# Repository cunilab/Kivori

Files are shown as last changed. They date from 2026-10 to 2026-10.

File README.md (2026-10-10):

# Kivori

Kivori is a desk buddy you control your computer with: the buddy is why you want one, the physical knob and button are why you keep using it, and the display shows important desktop and system state around the buddy.

> **Product thesis:** Control the desktop physically. Understand the desktop visually.

## Project status

**M0 — Working foundation.** Connection, protocol, deterministic rendering, Device Studio, the ESP32-C3/ST7789 runtime, the rotary volume loop and the mascot with its activity log are built. Remaining physical acceptance rows live in [`docs/validation.md`](docs/validation.md).

**M1 — Useful desk device.** Software complete on Windows and macOS, host-tested end to end. The push switch does Press (Play/Pause), Hold (mute) and Double press (next view); holding it ~10 s reboots the device with no app needed. The display has Buddy, Clock, Volume, Media and CPU/RAM views, and every action outcome is shown honestly as Confirmed, Started, Unverified or Failed. **Physical validation is outstanding:** the M0 rows and the Phase 4 rows in [`docs/validation.md`](docs/validation.md) need one human session.

**M2 and M2.5.** Three contextual buttons (Press and Hold each), the bindings config UI and foreground-app profiles are software complete and host-tested, awaiting hardware validation (Phase 5 and 6 rows).

**M3 — Paid beta.** Software complete: host takeovers, sleep and lock handling, firmware update and recovery, launch at login with a tray, the installer and an unsigned release pipeline ([`docs/release.md`](docs/release.md)), first-run onboarding, and per-unit provisioning ([`docs/provisioning.md`](docs/provisioning.md)).

Beta users start with the [user guide](docs/user-guide.md). Still open, and none of it is code: the hardware validation session (issue #38), signing the installer (needs certificates, #36), and the enclosure print (#33). See [`docs/roadmap.md`](docs/roadmap.md). Product behavior is defined in [`docs/product.md`](docs/product.md); durable technical choices are the ADRs in [`docs/architecture.md`](docs/architecture.md).

## Hardware

One ESP32-C3, one ST7789 240×240 panel, one HW-040 rotary encoder, three momentary push buttons. USB provides power, flashing, and the product data link — no external UART bridge.

### Pin map

| Signal | GPIO | Notes |
|---|---:|---|
| SPI SCK | 6 | SPI2, 20 MHz, Mode 3 |
| SPI MOSI | 7 | |
| Display D/C | 2 | strapping pin, driven after boot |
| Display RST | 3 | |
| Backlight | 8 | active-high; strapping pin, must be high at reset anyway |
| Encoder CLK (A) | 4 | |
| Encoder DT (B) | 5 | |
| Encoder SW | 10 | push switch: Press, Hold, ~10 s recovery reboot |
| Button left / middle / right | 0 / 1 / 20 | to GND, internal pull-up, no resistor; GPIO0/1 need a devkit without a 32 kHz crystal |
| USB D− / D+ | 18 / 19 | native USB Serial/JTAG, `0x303A:0x1001` |

Encoder COM to **GND**, VCC to **3V3**. **Not 5V — ESP32-C3 GPIOs are not 5 V tolerant.** Firmware enables internal pull-ups and reads all three encoder lines active-low, so it works whether or not your HW-040 board populates its own pull-ups.

### Two things worth knowing about these pins

**GPIO9 is deliberately avoided for the switch**, even though it is the BOOT button on most devkits. Holding GPIO9 low at reset enters the ROM download mode, and the encoder switch is Kivori's recovery control — a user power-cycling while holding it for recovery would land in the downloader instead of booting Kivori.

**The display pins are measured evidence; the encoder pins are not.** The display profile was physically verified on 2026-08-11 and is recorded in [`docs/validation.md`](docs/validation.md) (rows 1.9, 1.24, 1.25). The encoder pin map is a *specification* wired to on request, pending physical confirmation — row 3.15 of the same checklist. Do not treat the two as equally settled.

Both live in one place, [`firmware/esp32-c3/src/profile.rs`](firmware/esp32-c3/src/profile.rs), so a rewire is a single constant change.

## Getting started

### Prerequisites

- **Rust** stable (both workspaces pin it; the firmware workspace adds the `riscv32imc-unknown-none-elf` target automatically)
- **[Bun](https://bun.sh)** for the frontend
- **[just](https://github.com/casey/just)** as the command runner
- **[espflash](https://github.com/esp-rs/espflash)** only if you are flashing hardware — `cargo install espflash`
- **jq** for the dependency guard scripts
- A `WOKWI_CLI_TOKEN` only if you intend to run the Wokwi simulation gate

### Run the desktop app

```bash
bun install
just desktop                   # UI dev server + native app with the bundled firmware, one command
```

The native core owns the serial link; the webview receives only typed IPC commands. Device discovery is automatic — there is no COM-port picker by design.

### Flash the device

```bash
just fw-build                  # builds the product firmware (physical-st7789)
just fw-flash                  # flash + monitor over USB
```

Both recipes select the `physical-st7789` feature, which is what reaches the real display-and-input runtime. A plain `--features embedded` build compiles, but falls through to a bare fallback with no display and no input — useful to know if you invoke cargo directly.

### Verify without hardware

Most of the system is provable on a host machine:

```bash
just test                      # host workspace + frontend
just fw-test                   # firmware core against host-sim adapters
just golden                    # deterministic rendering, frame-hash goldens
just sim-test                  # Wokwi scenarios (needs a token)
```

Host-sim, Wokwi simulation, and physical hardware are **separate classes of evidence** in this project, and simulation never gets promoted to physical proof. Hardware results are recorded in [`docs/validation.md`](docs/validation.md).

## Documentation

One file per topic:

| File | What it answers |
|---|---|
| [`docs/product.md`](docs/product.md) | What Kivori must do: scope, behavior rules, numbered invariants, acceptance gates |
| [`docs/architecture.md`](docs/architecture.md) | How it works: components, wire protocol, IPC, rendering, rotary loop, decisions, principles |
| [`docs/roadmap.md`](docs/roadmap.md) | What gets built next, milestone by milestone (M0 to paid beta to v1) |
| [`docs/validation.md`](docs/validation.md) | The hardware checklist and how to run a validation session |
| [`docs/release.md`](docs/release.md) | How to cut a Windows or macOS release, and the unsigned-installer limits |
| [`docs/provisioning.md`](docs/provisioning.md) | Flashing and checking each new unit (`just provision`) |
| [`docs/user-guide.md`](docs/user-guide.md) | Short guide for a beta customer: install, setup, controls, recovery |
| [`docs/bom.md`](docs/bom.md) | Draft bill of materials (prices still to fill in) |

Wokwi simulation setup lives in [`sim/wokwi/README.md`](sim/wokwi/README.md). If the docs disagree,
`product.md` wins on behavior and the code wins on facts. Older plans, specs and research are in Git
history.

## Repository layout

```text
Kivori/
├── docs/        product, architecture, roadmap, validation, release, provisioning, user guide, BOM
├── apps/        Tauri desktop app (native core + Device Studio webview)
├── crates/      shared no_std crates: model, protocol, renderer, assets, framebuffer
├── firmware/    ESP32-C3 firmware
├── hardware/    3D-printable enclosure and printed prototype PCB (FreeCAD, parametric)
├── sim/         Wokwi simulation
├── tests/       golden frames and cross-crate tests
└── tools/       asset compiler and generators
```

## Common commands

The repository uses [`just`](https://github.com/casey/just) as a convenience command runner.

```bash
just dev               # Vite dev server for the Device Studio UI
just lint              # Rust + TypeScript formatting/lint/type checks
just test              # host workspace + frontend tests
just build             # host workspace + frontend build
just fw-check          # shared no_std crates compiled for RISC-V (isolation proof)
just fw-test           # firmware core against host-sim adapters
just fw-build          # build the product ESP32-C3 firmware (physical-st7789)
just fw-flash          # flash + monitor the product firmware over USB
just sim-test          # Wokwi integration scenarios (needs WOKWI_CLI_TOKEN)
just desktop           # UI dev server + native app with the bundled firmware
just provision         # flash and check one new unit (docs/provisioning.md)
just bundle-windows    # build the unsigned Windows installer (docs/release.md)
just bundle-macos      # build the macOS .app/.dmg (docs/release.md)
just golden            # deterministic rendering golden-frame tests
just check-boundaries  # shared-crate dependency firewall
just assets            # recompile the canonical asset blob
```

Three guard scripts run in CI and are worth running locally before pushing — they fail for reasons ordinary tests do not catch:

```bash
bash scripts/check-release-surface.sh   # dev-only surfaces absent from production builds
bash scripts/check-crate-boundaries.sh  # no std/OS deps in the shared no_std crates
bash scripts/check-offline-deps.sh      # no first-party crate pulls a network client
```

`check-release-surface.sh` compiles the shared crates for the device target on purpose, including a positive control that proves the absence checks are not vacuous. It is the one gate most likely to catch a change that every test suite still passes.

See [`docs/validation.md`](docs/validation.md) and [`sim/wokwi/README.md`](sim/wokwi/README.md) for hardware and simulator setup.

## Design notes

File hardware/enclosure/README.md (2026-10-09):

# Kivori enclosure (prototype v3, "big keycap")

A 110 × 70 mm wedge case (30 mm thick at the far edge, 18 mm at the near edge, so the face tilts
about 10° towards you). It follows the blueprints in [`docs/assets/`](../../docs/assets/) and is
10 mm wider than drawn: at 100 mm, the Ø48 knob overlaps the left button.

The look is a big keycap, matching the keycap mascot on screen:

- **Shell:** the walls lean in 6° towards the face, and a 45° bevel frames it. The sides are
  clean: no latch windows or screws.
- **Visor:** a black panel, 1 mm proud of the face, carries the display window and the three
  button openings. Its edge follows the knob at an even gap.
- **Knob:** sits inside a thin groove ring. Fine ribs round the edge for grip, and a line marker
  on top.
- **Plinth:** dark and set back under the shell, so the light shell seems to float above the desk.
  The underside carries the wordmark, the RST/BOOT labels and recesses for rubber feet.
- **Colours:** light matte shell; black visor, knob and plinth; accent-colour caps.

Inside is a **printed PCB** (`Carrier`): a plate with the outline, mounting holes and part positions
a real PCB would have. Components sit on it and are hand-wired along engraved grooves on the
back. Once the prototype works, `export/pcb-outline.dxf` becomes the Edge.Cuts layer in KiCad.

No screws. Four hooks on the back plate catch ribs inside the walls. Each hook has 45° ramps
both ways, so the plate clicks in and pulls back out. The printed PCB is clamped between posts on
the faceplate and columns on the back plate.

How each part is held on the printed PCB, even with the case open:

| Part | Held by |
|---|---|
| HW-040 | A pocket stops it sliding. Two pegs go through its two M3 holes along the long edge. The pocket floor is open under the encoder legs and the three pull-up resistors. |
| Display | Four standoffs whose pegs go through its four corner holes. |
| SuperMini | A 1 mm recess in the back whose end wall takes the USB plug-in force. When closed, a pad on the back plate presses up under the USB connector. |
| 12×12 switches | Legs through the plate, bent over on the back before soldering. |

The pegs are 0.2 mm smaller than the holes (press fit) and stick out 1 mm past the module board.
To lock a part for good, touch each peg tip with the soldering iron so it melts into a small head
(heat-staking). To remove the part later, cut the head off. The faceplate has relief pockets over
the display pegs, so a staked head still fits.

## Files

| File | What |
|---|---|
| `build_case.py` | The whole model. Every dimension is a parameter at the top. |
| `kivori-case.FCStd` | Generated FreeCAD document (printed parts plus blue stand-ins for the bought parts). |
| `export/*.stl` | Printed parts, already in print orientation (binary STL). |
| `export/pcb-outline.dxf` | Printed PCB outline, mounting holes and pin holes, in mm. |

To rebuild after changing a parameter, run it headless from the repo root:

```bash
/Applications/FreeCAD.app/Contents/Resources/bin/freecadcmd hardware/enclosure/build_case.py
```

or in FreeCAD's Python console (or through the FreeCAD MCP):

```python
p = "<repo>/hardware/enclosure/build_case.py"
exec(open(p).read(), {"__file__": p, "__name__": "__main__"})
```

It prints an interference report (`interference: none` is the goal), regenerates the document
and rewrites `export/`.

## Parts to print

FDM, 0.4 mm nozzle, 0.2 mm layers, 3 walls, 20 % infill. None of the parts needs supports.

| Part | Material | Orientation (already applied in the STL) |
|---|---|---|
| `Shell` | matte light PLA (white or warm grey) | face down |
| `Visor` | black PLA; a smooth PEI sheet gives it a glossy face | top down |
| `BackPlate` (with the plinth) | black **PETG** (the hooks crack in PLA) | desk side down |
| `Carrier` (printed PCB) | any PLA (hidden) | back down, pegs and standoffs up |
| `Knob` | black PLA | top down |
| `CapLeft` / `CapMiddle` / `CapRight` | accent-colour PLA | flange down |

Every part is printed in a single colour; the two-tone look comes from printing the parts in
different filaments, so no filament change mid-print is needed.

## Bought parts

| Part | Notes |
|---|---|
| ESP32-C3 SuperMini | Flush in a recess in the back of the printed PCB, components facing the back plate. No header pins: solder wires to the pads. |
| ST7789 1.3" 240×240, 7-pin | On four standoffs with pegs, glass in a 0.6 mm pocket behind the window, header pins through the slot. |
| HW-040 rotary encoder | In a pocket on the front of the printed PCB, on two pegs. Its right-angle header points towards the middle of the case; wires drop to the back through the slot past the pin tips. The nut is optional. |
| 3 × 12×12 mm push switch, 10 mm tall | Legs go through the printed PCB. |
| Thin wire (26–30 AWG) | Laid in the grooves on the back. |
| 4 × 10 mm stick-on rubber feet | In the recesses under the plinth. |

## Assembly

1. Press the HW-040 onto its two pegs in the pocket on the front of the printed PCB. Press the
   display onto its four pegs, header through the slot. Optionally heat-stake the six peg tips.
2. Put the three switches through their holes and bend the legs over on the back.
3. Press the SuperMini into the recess on the back, components facing out and USB-C towards the
   open end.
4. Wire along the grooves (table below) and solder each wire to the pin where its groove ends.
5. Drop the three caps into the face openings from inside the shell, flange first.
6. Lower the printed PCB onto the four posts, encoder shaft through the face hole.
7. Press the back plate straight in until all four hooks click, then stick the feet on.
8. Press the visor's three pegs into the face. A drop of CA glue or thin double-sided tape keeps
   it there.
9. Push the knob onto the D-shaft.

To open: grip the plinth in the shadow gap and pull. The hooks release without tools. RST and
BOOT are pinholes in the plinth, labelled; a paperclip reaches the SuperMini's buttons.

## Wiring

These are the pins from [`profile.rs`](../../firmware/esp32-c3/src/profile.rs) and the README.

| SuperMini | Net | Goes to |
|---|---|---|
| IO6 | SCL | display SCL |
| IO7 | SDA | display SDA |
| IO2 | DC | display DC |
| IO3 | RES | display RES |
| IO8 | BLK | display BLK (backlight) |
| 3V3 | 3V3 | display VCC, encoder + (**never 5 V**) |
| GND | GND | display GND, encoder GND, one leg of each switch |
| IO4 | CLK | encoder CLK |
| IO5 | DT | encoder DT |
| IO10 | SW | encoder SW |
| IO0 / IO1 / IO20 | B1 / B2 / B3 | left / middle / right switch, other leg |

Validation row 5.1 still applies: check that the SuperMini has no 32.768 kHz crystal on
GPIO0/GPIO1.

## Dimensions to verify (NOMINAL in `build_case.py`)

Nothing here was measured on the real parts. The HW-040 and display layouts are scaled from a
dimensioned drawing and product photos (about ±0.5 mm). The rest comes from KiCad footprints and
seller listings. Ranked by risk:

1. **Display module** (`DISP_*`):
   - 4 corner holes, Ø2, centres 2 mm in from both edges.
   - Board 39.22 × 27.78 mm, 3.0 mm thick with the glass.
   - Glass 27.6 mm long including the FPC ledge, centre 1.6 mm from the board centre towards the
     end away from the header. Active area centre 0.5 mm the same way.
   - Header row 2.2 mm in from its end, header on the right as mounted (`DISP_HEADER_SIDE`).
2. **HW-040** (`HW040_*`, in the module's own frame, origin at the board centre):
   - Board 26 × 18.5 × 1.3 mm.
   - Shaft at (−3.7, +1.25).
   - M3 holes at (−8.4, −7.45) and (+5.8, −7.45).
   - Header row at x = +10.35.
   - Shaft top 21 mm above the board underside. EC11 body 6.5 mm and bushing 7 mm are NOMINAL.
3. **SuperMini**: BOOT/RST positions (`SM_BTN_*`), header pin order (`SM_COL_A/B`), USB-C size.
4. **12 mm switch**: projected-plunger type, seller drawing TS-G005, 10 mm tall version.
   - Housing 12 × 12 × 3.5 mm with a round Ø7 platform up to 4.3 mm.
   - Stem: a 3 mm square neck, then a wider 4 × 4 mm head about 1.8 mm tall, top at 10 mm.
   - The cap socket is 4.3 mm square. It slips over the head and stops the cap turning; the
     flange behind the faceplate is what holds the cap in.
   - Pins on a 12.5 × 5 mm grid (land pattern Ø1.5). Two extra Ø2 holes, 9 mm apart, clear the
     locating bosses some 12 × 12 switches have (Omron B3F); TS-G005 shows none.

A cheap check before the full print: print only the `Carrier` first (about 1 h), then press the
parts on. If a peg misses its hole, measure the hole position, change the parameter and rebuild.

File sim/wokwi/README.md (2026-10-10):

# Wokwi pre-hardware simulation gate

Runs the **real** Kivori ESP32-C3 firmware in the [Wokwi](https://wokwi.com) simulator so the embedded
runtime, protocol loop, lifecycle state machine, and renderer integration can be exercised **before**
anyone flashes a board.

> **Simulation does not replace physical validation.** A green Wokwi run says the firmware's logic
> executes correctly on a simulated RISC-V core. It says nothing about whether the product works on real
> hardware. The physical checks in [`docs/validation.md`](../../docs/validation.md)
> remain mandatory and unchecked until someone runs them on a device.

## Four modes, four artifacts

| Mode | Feature | Artifact | Diagram | What drives the device |
|---|---|---|---|---|
| **Internal on-target self-test** | `wokwi` | `target/wokwi/kivori-selftest.elf` | `diagram.json` (UART0 monitor) | an in-firmware harness — this is an *integration self-test*, **not** an external serial-transport test |
| **External serial test** | `wokwi-serial` | `target/wokwi/kivori-serial.elf` | `diagram-usb-serial.json` (`serialInterface: USB_SERIAL_JTAG`) | Wokwi `write-serial` injects **real wire frames** from outside; the firmware's real USB Serial/JTAG rx/tx loop, decoder, sequence policy, and `Dispatcher` handle them |
| **Production runtime** | `wokwi-runtime` | `target/wokwi/kivori-runtime.elf` | `diagram-runtime.json` (USB Serial/JTAG + generic display + logic analyser) | **the real `runtime::run` loop** — the same function the physical firmware calls, with a simulation-only board profile. The strongest evidence in the gate: it is the shipping loop, not a harness |
| **Generic SPI display probe** | `wokwi-spi` | `target/wokwi/kivori-spi.elf` | `diagram-spi.json` (`wokwi-ili9341` as a *generic* SPI sink) | the real T072 `mipidsi` `DisplaySink` over the real esp-hal SPI peripheral; counted at the `embedded-hal` boundary and captured as a VCD |

The external mode is the stronger evidence: bytes genuinely enter the device from outside. Injected bytes
are generated by [`tools/wokwi-vectors`](../../tools/wokwi-vectors) from the real `kivori-protocol` codec,
so no wire-format constant is duplicated for tests. Regenerate with:

```bash
cargo run -p kivori-wokwi-vectors     # writes sim/wokwi/generated/ (CI fails on a stale diff)
```

Neither mode creates an operating-system serial port: **the Tauri desktop cannot open a Wokwi device.**

## How it works

Wokwi automation supports both directions: `wait-serial` asserts on serial **output**, and `write-serial`
accepts a **byte array**, so real binary frames can be injected as serial **input**. The supported step
vocabulary was verified against the CLI's own validator (v0.26.1): `wait-serial`, `write-serial`, `delay`,
`set-control`, `expect-pin` are accepted; `wait-pin`, `screenshot`, `wait-text` are not.

* The **internal** self-test ([`selftest.rs`](../../firmware/esp32-c3/src/selftest.rs)) drives the core
  from inside via [`LoopbackTransport`](../../firmware/esp32-c3/src/sim_probe.rs), printing one
  `KIVORI-SIM …` line per check. Useful, but it is an on-target *integration* self-test — it does not
  exercise the serial peripheral.
* The **external** mode ([`external.rs`](../../firmware/esp32-c3/src/external.rs)) is the real thing:
  injected bytes arrive through the USB Serial/JTAG peripheral via
  [`transport.rs`](../../firmware/esp32-c3/src/transport.rs) (the same adapter the hardware run loop will
  use), pass through the real decoder + sequence policy + `Dispatcher`, and the device's real response
  frames go back out over the same peripheral. Redacted `KIVORI-EXT …` markers report the semantics.

Nothing under test is simulation-specific:

| Layer | In simulation | On hardware |
|---|---|---|
| Protocol codec, dispatcher, lifecycle FSM | identical (`kivori-protocol`, `proto.rs`, `state.rs`) | identical |
| Renderer, scene model, compiled asset bundle, RGB565 tiles | identical (`kivori-renderer`, same blob bytes) | identical |
| Clock | `EspClock` (esp-hal system timer) | same `EspClock` |
| Transport | **real `UsbJtagTransport`** (external mode); `LoopbackTransport` probe (internal mode) | same `UsbJtagTransport` |
| Display | `TileProbe` (internal mode); **real `MipidsiSink`** over real SPI (`wokwi-spi` mode) against a *generic* display part | same `MipidsiSink`, with the **confirmed** panel model and its real offsets |

There is **no separate simulation renderer** — that would violate Constitution II.

## Usage

```bash
bash scripts/build-wokwi-firmware.sh              # builds all FOUR ELFs into target/wokwi/
export WOKWI_CLI_TOKEN=...                        # CI token; never committed, never in argv
bash scripts/test-wokwi.sh                        # runs all eight scenarios
bash scripts/test-wokwi.sh boot spi-display-probe  # or a subset, matched by name
```

`wokwi-cli` must be installed (`curl -L https://wokwi.com/ci/install.sh | sh`, then
`export PATH="$HOME/.wokwi/bin:$PATH"`). Both the CLI and the token are required; the script exits with
status 2 and an explanation rather than reporting a false pass.

### The token must be a CI token

`WOKWI_CLI_TOKEN` must be a **CI token** from <https://wokwi.com/dashboard/ci> (short, `wok_…` shaped).
An interactive user/session credential — for example the long JWT that `wokwi-cli` writes to
`~/.wokwi/user.tok` after a browser login — is **not** a CI token: the CLI connects to the Simulation API
and the API answers `Unauthorized`. If you see:

```
Connected to Wokwi Simulation API 1.0.0-…
API Error: Unauthorized
```

the transport and the project are fine; the credential is the wrong type, revoked, expired, or from a
different account. Mint a CI token and re-export it. Never commit a token; never put it in workflow YAML
(CI reads `secrets.WOKWI_CLI_TOKEN`).

## Scenarios

Internal self-test (hand-written, no injection):

| Scenario | Asserts |
|---|---|
| [`boot.yaml`](scenarios/boot.yaml) | firmware boot, monotonic/advancing clock, `booting` → `offline` |
| [`protocol.yaml`](scenarios/protocol.yaml) | dispatch loop, `Hello`/`HelloAck` + nonce, identity, capability advertisement, major-version rejection, `Ping`/`Pong`, malformed-frame recovery |
| [`state-cycle.yaml`](scenarios/state-cycle.yaml) | `SetState`/`StateReport`, `booting`/`offline` never sendable, compiled-asset parse, 6×240×40 RGB565 tiles, change-driven refresh, safe diagnostics |

External serial injection (generated — contain real wire bytes):

| Scenario | Asserts |
|---|---|
| [`generated/serial-smoke.yaml`](generated/serial-smoke.yaml) | readiness marker, one real `Ping` frame received over USB Serial/JTAG, `Pong` response path |
| [`generated/protocol-serial.yaml`](generated/protocol-serial.yaml) | handshake, compatible-minor accept, unsupported-capability intersection, unsupported-major drop, CRC-invalid drop, malformed-COBS drop, truncated-frame drop, recovery with the next valid frame, sequence duplicate/gap/wraparound classes |
| [`generated/state-cycle-serial.yaml`](generated/state-cycle-serial.yaml) | `SetState(idle)` → `StateReport(idle)`, `SetState(happy)` → `StateReport(happy)`, structural sendable guard |

Generic SPI display probe (hand-written; real SPI traffic):

| Scenario | Asserts |
|---|---|
| [`generated/production-runtime.yaml`](generated/production-runtime.yaml) | the **production** loop: device-owned `booting` → `offline`, the first full frame, change-driven refresh, health cadence, `Hello`→`HelloAck`, `SetState`→`StateReport` for idle and happy, a malformed frame dropped and reported as a SAFE `Diagnostic` (category+code only), recovery on the next valid frame, and `ALL PASS production-runtime` only once all ten hold |
| [`spi-display-probe.yaml`](scenarios/spi-display-probe.yaml) | SPI peripheral + GPIO bring-up, panel reset sequenced, command/data phases distinguishable (D/C), CS-framed transactions, solid red/green/blue and checkerboard RGB565 frames, six 240×40 tiles of 9,600 pixels in top-to-bottom order, an **exact** per-frame byte volume (115,248 data + 18 command bytes), no retransmission for an unchanged frame, retransmission on a state change |

### VCD capture requires a logic analyzer part

`--vcd-file` alone produces **nothing**. Verified from an actual run: the CLI reported
`Error exporting VCD: Error 6: No logic analyzer in diagram` and wrote no file. `diagram-spi.json`
therefore includes a `wokwi-logic-analyzer` with `channelNames: "SCK,MOSI,CS,DC,RST"` on `D0`–`D4` plus
`GND`; `triggerMode` defaults to `off`, which records from the start, so no trigger wiring is needed.

Two things a real capture taught us, both now encoded in the checker and its tests:

* **Every line reads `1` at time 0.** The pins float high until the firmware configures them ~164 ms into
  boot, so the first sample is not bus activity. Measuring from time 0 made "data follows command" fail on
  a perfectly good bus. Every activity measurement is now taken **after the panel reset is released**.
* **The capture is a truncated window.** `bufferSize` is 500,000 samples (≈6.7 MB), while a full run clocks
  ~691 KB of pixel data. The checker's thresholds are deliberately below a full frame's worth for that
  reason — the VCD proves the bus behaves, and the firmware's own counters prove the exact volume.

`wokwi-cli lint` warns `Unknown attribute "channelNames"`; its attribute list is stale, and the simulator
honours it — the produced VCD declares `SCK`/`MOSI`/`CS`/`DC`/`RST`, not `D0`–`D4`.

That scenario also writes `target/wokwi-vcd/spi-display-probe.vcd`, which
[`tools/wokwi-vcd`](../../tools/wokwi-vcd) then parses: clock activity, CS/D/C transitions, a reset pulse,
data following a command phase, a minimum clocked-bit volume, and monotonic stage ordering. A capture that
cannot be parsed — or whose signals cannot be identified — **fails**; it is never accepted for existing.
Run `cargo run -p kivori-wokwi-vcd -- --list-signals <file.vcd>` to see the real signal names and adapt
`Role::candidates` from evidence.

### Marker order is part of the contract

`wait-serial` scans **forward only**, so a scenario must await markers in the order the firmware genuinely
emits them. The production-runtime scenario's first draft awaited `health-report` after
`unchanged-frame-no-reflush`; the runtime emits health on tick 1 and the first quiet frame on tick 2, so the
run hung to timeout — the same defect that once broke `state-cycle-serial`. The order now matches real
behaviour and is pinned by a host test (`emission_order_is_stable`), plus marker/firmware coupling tests in
`tools/wokwi-vectors/tests/scenario_files.rs`.

Timeouts are per-scenario wall-clock budgets, because Wokwi runs slower than real time and the production
runtime re-hashes six tiles every simulated 33 ms. Budgets never change what a scenario asserts.

A scenario fails when a `wait-serial` line never arrives (panic, hang, decode failure, missing handshake
reply, missing `Pong`, render-loop stall) or when `--fail-text` matches `KIVORI-SIM FAIL` / `panicked`.

## What this gate does **not** prove

Simulation is **not** evidence for any of the following. Each remains a physical-hardware task:

- real USB VID/PID enumeration (`0x303A:0x1001`) — T115
- Tauri opening a real serial device / desktop↔device end-to-end — T115, T117
- electrical correctness, signal integrity, pull-ups, level shifting
- **the identity of the physical panel controller** (measured on the real board as an ST7789, validation rows 1.9, 1.24, 1.25; simulation says nothing about it) — T118
- real display offsets, colour order, orientation, or any panel init sequence — T118
- the Kivori board's real SPI/CS/D/C/RST pin map — the `wokwi-spi` pins are a *simulation-only* profile
- anything analog: a VCD is a digital event list, so no signal integrity, timing margin, or level checks
- physical SPI integrity and timing — T119
- sustainable physical frame rate over SPI — T119
- physical unplug/reconnect reliability — T116, T117
- power consumption or thermal behaviour
- esp-hal `unstable` API behaviour on real silicon — T122

## Display strategy (staged)

**Stage 1 (implemented).** No display part in [`diagram.json`](diagram.json). `TileProbe` proves the
canonical renderer produces the right RGB565 tile geometry and that unchanged frames flush nothing —
without asserting anything about a controller.

**Stage 2 (implemented — T131).** [`diagram-spi.json`](diagram-spi.json) adds Wokwi's built-in
`wokwi-ili9341` and the `wokwi-spi` firmware drives it through the real T072 adapter
([`display.rs`](../../firmware/esp32-c3/src/display.rs)), so genuine SPI traffic exists to observe. Three
scopes, and only the first two are claimed:

| Scope | Claimed? | Content |
|---|---|---|
| **A — generic SPI transactions** | ✅ | peripheral init, reset sequencing, command/data phases, CS framing, transfer boundaries |
| **B — generic RGB565 tile stream** | ✅ | six 240×40 tiles, 9,600 pixels each, deterministic byte volume and order, tile Y offsets, change-driven refresh |
| **C — controller-specific behaviour** | ❌ **not claimed** | any ST7789/GC9A01/ILI9341 init sequence, panel offsets, orientation, colour order, backlight |

`wokwi-ili9341` is used **only** as a generic SPI/RGB565 sink. It does **not** validate an ST7789 (or
GC9A01) initialisation sequence — the controllers differ in init, offsets, and colour order — and a green
probe run is therefore not evidence that any real panel will light up. The adapter itself is generic over
`mipidsi`'s `Model`, so no controller is hard-coded anywhere in the firmware.

The pin numbers in `diagram-spi.json` (`SCK=4, MOSI=5, CS=6, D/C=7, RST=10`) are a **simulation-only**
profile (`WokwiSpiPins`). They were chosen from the board part's valid pins as reported by
`wokwi-cli lint` — `0–10, 18, 19, RST, RX, TX` — excluding `18`/`19` (USB Serial/JTAG on this SoC) and
`2`/`8`/`9` (ESP32-C3 strapping pins). They are **not** the Kivori hardware pin map (SCK 6, MOSI 7, D/C 2, RST 3, backlight 8, see
[`profile.rs`](../../firmware/esp32-c3/src/profile.rs)).

**Custom ST7789 chip: deliberately not created.** The physical controller is confirmed as an ST7789
(validation rows 1.9, 1.24, 1.25), but no chip model is needed yet. If one is, implement only the command subset Kivori uses — `SWRESET`, `SLPOUT`, `COLMOD`, `MADCTL`, `CASET`,
`RASET`, `RAMWR`, `DISPON` — with the Wokwi Custom Chips SPI/framebuffer APIs, and treat that chip as a
development tool, never a production dependency.

## Relationship to the other gates

```
host tests (primary)        cargo test --workspace, firmware --features host-sim, golden frames
        │
        ▼
Wokwi simulation (this)     embedded runtime + protocol/lifecycle/render on a simulated C3
        │
        ▼
physical hardware (final)   docs/validation.md — still required, still unchecked
```

Simulation may fail a change that host tests pass (e.g. a real linker/runtime problem), which is exactly
its value. It may also pass a change that a real board rejects — which is why it is never the last gate.

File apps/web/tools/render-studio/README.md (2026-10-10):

# Studio renders (dev only)

Renders the product pictures in `apps/web/public/media/renders/`. The WebP/PNG results are committed; this
tool is not part of the web build and CI never runs it.

```bash
bun apps/web/tools/render-studio/render.mjs            # all shots
bun apps/web/tools/render-studio/render.mjs hero-34    # selected shots by name
```

Needs the installed Google Chrome (`/Applications/Google Chrome.app`, or set `CHROME_PATH`). No browser is
downloaded. `three` and `puppeteer-core` are pinned devDependencies of `apps/web`.

How it works:

- `render.mjs` serves `scene.html` on 127.0.0.1 while it runs and drives Chrome with `puppeteer-core`.
- The enclosure STLs are read from `hardware/enclosure/export/` at render time only (Carrier is left out). They
  are never copied into `public/` or served by the site.
- `scene.js` puts every part back in its assembled place. The STLs are in print orientation, so each part gets
  the inverse of `print_pose` in `hardware/enclosure/build_case.py` plus its original bounding-box minimum
  (taken from the build script). If the enclosure model changes, re-derive those offsets (the numbers in
  `PARTS`), then re-render.
- The screen texture comes from `public/media/screens/` (see `../export-screens.mjs`).
- Output: 2400 px wide WebP (quality 90) and a `-1200` variant, plus a transparent `hero-34-transparent` PNG/WebP.

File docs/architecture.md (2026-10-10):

# Kivori architecture

How Kivori is built today. Product goals are in [product.md](./product.md), open work in [roadmap.md](./roadmap.md), test and hardware evidence in [validation.md](./validation.md).

## 1. Overview

Kivori is a small desk companion. A keycap-shaped mascot lives on a 240x240 screen, reacts to what the desktop tells it, a rotary knob turns volume (or per-profile shortcuts), its push switch runs actions (Press, Hold, Double press) and the out-of-band recovery hold, and three contextual buttons run per-profile actions. The display can also show a clock, volume, media and CPU/RAM view.

| Component | What it is |
|---|---|
| Firmware | ESP32-C3, ST7789 240x240 panel, HW-040 rotary encoder, three buttons. Version 1.3.0, protocol 1.5. `no_std`, no heap, `riscv32imc`. |
| Desktop native core | Tauri 2.12 Rust process. Owns the serial port, the connection, OS integration, preview rendering, flashing. |
| Desktop webview | React UI. Only calls a fixed set of typed commands. No serial, filesystem or shell access. |
| Shared crates | One copy of the model, protocol, renderer and asset reader, used by both firmware and desktop. |

```text
                  USB Serial/JTAG (COBS + CRC-32 + postcard frames)
  +--------------------+  <------------------------------------>  +---------------------+
  | Desktop native core|                                           | Firmware (ESP32-C3) |
  |  device thread     |   Hello/HelloAck/Ready, SetState,         |  ports: Clock,      |
  |  orchestrator      |   InputEvent, Presentation, ...           |  Transport, Display,|
  |  platform backends |                                           |  Input              |
  +---------+----------+                                           |  renderer -> ST7789 |
            | typed Tauri IPC (commands, events, binary channel)   +----------+----------+
  +---------+----------+                                                      |
  | React webview      |                                        HW-040 A/B/SW + panel
  +--------------------+
```

The wire carries meaning (state, input, presentation), never pixels. Both sides render with the same crates, so the Device Studio preview matches the panel.

### Repo layout

Two Cargo workspaces. Shared crates are `no_std`, no-alloc, and the single source of truth.

| Path | Purpose |
|---|---|
| `crates/kivori-model` | State enums, device profile, timeline, version and capabilities, mascot animator, input and presentation types. |
| `crates/kivori-protocol` | Wire codec: COBS, header, CRC-32, postcard `Message`, handshake and negotiation, sequence policy. |
| `crates/kivori-framebuffer` | RGB565 tile bands and content hashing (change detection). |
| `crates/kivori-renderer` | Deterministic scene compositor and volume overlay (`embedded-graphics` `DrawTarget`). |
| `crates/kivori-assets` | Zero-copy reader for the compiled asset blob. |
| `apps/desktop/src-tauri` | `kivori-desktop`: `device/` (discovery, session, reconnect, heartbeat, nonce), `runtime/` (device task), `orchestrator/`, `input/`, `action/`, `platform/`, `presentation/`, `desk/` (profiles, bindings, catalog, actions), `config/` (store, schema, resolve, migrate), `companion.rs`, `activity/`, `firmware.rs`, `firmware_marker.rs`, `window_lifecycle.rs`, `provision.rs` (dev-only `just provision`), `ipc/`, `render/`. |
| `apps/desktop/src` | React frontend and typed IPC wrappers. |
| `firmware/esp32-c3` | Separate workspace: `ports.rs`, `input/` (quadrature, gesture), `physical_st7789.rs`, `physical_rotary.rs`, `runtime.rs`, `proto.rs`, plus host simulation adapters in `sim/`. |
| `tools/asset-compiler` | SVG to deterministic RGB565 blob (host build tool). |
| `tools/wokwi-*`, `tests/e2e-host-sim`, `tests/golden-frames` | Simulation vectors, host-sim end-to-end tests, cross-OS frame-hash harness. |
| `.github/workflows/` | CI, see below. |
| `scripts/` | Boundary guards (`check-crate-boundaries.sh`, `check-offline-deps.sh`, `check-frontend-offline.mjs`) and firmware/desktop build scripts. |

CI workflows (`.github/workflows/`):

| Workflow | What it runs |
|---|---|
| `host` | Rust on Ubuntu and Windows, the frontend, and the Windows Device Studio startup smoke test: format, clippy, tests, the boundary, offline and release-surface guards. |
| `firmware` | no_std isolation proof, firmware host-sim tests and RISC-V builds and clippy per feature set. |
| `determinism` | Golden-frame hashes across operating systems and the byte-reproducible asset blob. |
| `wokwi` | The Wokwi simulation gate. Path-filtered (`firmware/**`, `crates/**`, `sim/**`, Wokwi tools and scripts) because its minutes are metered. |
| `release` | The unsigned Windows installer and draft release on a `v*` tag, manually with an optional macOS build; also on pull requests that touch packaging files ([release.md](./release.md)). |

`scripts/check-crate-boundaries.sh` fails CI if a shared crate gains a std, host or OS dependency. Compiling the shared crates for RISC-V is the hard backstop.

### State axes

Three separate axes. Never merge them into one enum.

- Companion (6): `booting, idle, happy, busy, sleeping, offline`. What the device shows.
- Sendable (4): `idle, happy, busy, sleeping`. The subset the desktop may command. `booting` and `offline` come from the device.
- Connection (5): `disconnected, connecting, connected, incompatible, error`. The link lifecycle.

Desktop state is in memory only. `desired` defaults to `idle` and is re-sent after a reconnect. `reported` is what the device says and never overwrites `desired`.

### Chosen platform APIs

- Transport: ESP32-C3 native USB Serial/JTAG (VID:PID `0x303A:0x1001`). It has a 64-byte FIFO and TX can stall if the host does not drain, so frames are small and writes are bounded.
- Firmware HAL: `esp-hal`, bare metal. Display: `mipidsi` with windowed writes.
- Desktop serial: blocking `serialport` on a dedicated device thread.
- Windows volume and mute: Core Audio `IAudioEndpointVolume` with callbacks, on its own COM thread.
- macOS volume and mute: CoreAudio `kAudioHardwareServiceDeviceProperty_VirtualMainVolume` and `kAudioDevicePropertyMute` on the default output device, with HAL property listeners, on its own `kivori-audio` thread (FFI declared by hand in `platform/macos/audio.rs`).
- Media keys and shortcuts: `enigo` (Windows `SendInput`, macOS Quartz events; macOS needs Accessibility permission). On macOS every synthesized input runs on the app's main thread via Tauri's `run_on_main_thread`: since macOS 15 the HIToolbox layout lookups it uses assert the main queue and kill the process otherwise.
- Media playback observation (state, title, artist): Windows Global System Media Transport Controls, polled on a `kivori-media` thread. macOS has no public API, so it is layered (ADR-0009): the vendored MediaRemote adapter, then AppleScript for Spotify and Music, then unknown.
- CPU/RAM: Windows `GetSystemTimes` / `GlobalMemoryStatusEx`; macOS per-CPU `host_processor_info` (`host_statistics` is rate-limited for third-party apps) and Activity Monitor's "Memory Used". Local time: `GetLocalTime` / `localtime_r`.
- Sleep, wake, lock and console changes: Windows `PowerRegisterSuspendResumeNotification` (callback) plus `WTSRegisterSessionNotification` on a message-only window thread; macOS IOKit `IORegisterForSystemPower` on a CFRunLoop thread (hand-declared FFI) plus a 4 Hz poll of the session lock flag. See Host presence.
- Flashing: a pinned `espflash` sidecar, driven by the native core (see Firmware update and recovery).
- Not built yet: a Linux backend, desktop self-update, a factory-provisioned device id.
- Device id (#24): the firmware derives its 16-byte `device_id` from the chip's factory eFuse unique ID, falling back to the base MAC, through a domain-separated SHA-256 (`kivori-device-id-v1`); raw eFuse bytes never go on the wire. The raw id stays in the transport layer; UI and logs only show the short hash (ADR-0005). Simulator and Wokwi images keep fixed ids.

## 2. Wire protocol

Contract crate: `kivori-protocol`. Both peers compile the same `Message` enum.

### Framing

One packet is `COBS(frame) || 0x00`. COBS makes the stream self-synchronizing, so the decoder resyncs after corruption. Decoded frame, little-endian:

| Field | Type | Notes |
|---|---|---|
| `magic` | u16 | `0x4B56` ("KV") |
| `ver_major`, `ver_minor` | u16, u16 | Sender protocol version. Outside the payload so a major mismatch is caught before decoding. |
| `seq` | u16 | Wrapping sequence number |
| `payload_len` | u16 | At most `MAX_PAYLOAD` = 512 |
| `payload` | bytes | postcard-encoded `Message` |
| `crc32` | u32 | CRC-32/IEEE over header and payload |

Constants: `PROTOCOL_MAJOR` 1, `PROTOCOL_MINOR` 5. COBS and CRC are implemented in-crate.

Every decode failure is a typed `ProtoError` (`BufferOverflow, Cobs, TooShort, BadMagic, UnsupportedVersion, PayloadTooLarge, LengthMismatch, BadCrc, Postcard`). The decoder never panics, always makes forward progress, and never dispatches a frame that failed CRC.

### Handshake

```text
Desktop                                   Device
  | Hello { desktop_version, desktop_caps, nonce } -> |
  | <- HelloAck { device_caps, device_id, firmware_version, nonce_echo } |
  |  nonce mismatch or unsupported major: Bye, Incompatible/Error       |
  | Ready { negotiated_minor, negotiated_caps } ->    |   Connected
  | SetState { desired } ->  <- StateReport { reported, elapsed_ms }    |
```

- A device counts as Kivori only after a well-formed `HelloAck` with the matching nonce. VID:PID alone is not identity.
- The desktop gives up on a missing `HelloAck` after 5 s, closes the link, and retries with backoff.
- After connecting, the desktop pings every 1 s and treats 3 misses as a lost link. `Pong.t_ms_echo` matches a ping.
- The desktop never sends state commands to an `Incompatible` device.
- Discovery rotates through every VID:PID match (`CandidateRotator`), because a stock ESP32-C3 shares the ids. Each port has its own backoff; a port that fails to open or answer is passed over for the others, and after 3 handshake timeouts in a row it is only retried when no other candidate exists. A single never-failed candidate is tried immediately.
- On an `Incompatible` handshake the UI shows the state, then the desktop closes that link and skips the port until it is unplugged, so another candidate can connect (`Incompatible` -> `Connecting`). With only the incompatible board plugged in, the state stays and no attempt is made. Port names are never logged or recorded in the activity log.

### Nonce is the session identity

The handshake nonce also identifies the connection. It is minted fresh from OS randomness (`getrandom`, one `u32` per attempt; `device/nonce.rs`), so two desktop processes cannot collide.

- Firmware stamps every `InputEvent` with the nonce of the `Hello` it accepted. The desktop drops any `InputEvent` with another session.
- The desktop stamps every `Presentation`. Firmware drops any with another session, or with a revision that is not newer.
- Firmware clears input state and its revision high-water mark on a new `Hello`, on `Bye`, and on link loss. The desktop clears open gestures whenever it leaves `Connected`.
- `Presentation.revision` increases within a session and restarts at 1 in a new session.
- The nonce is a freshness token. It is not secret and authenticates nothing.

### Negotiation and compatibility

- Compatible if the device major is one the desktop supports. Otherwise `Incompatible`.
- `negotiated_minor = min(desktop, device)`. `negotiated_caps = desktop_caps & device_caps`.
- A capability set on one side only stays off. An unnegotiated peer never sends or acts on the gated message.
- Evolution is append-only: the postcard variant index is the wire tag, and this also holds for every type nested inside a message. Add variants at the end, gate new behavior with a capability. Reordering or removing anything needs a new major.
- Unknown input: a bad frame or an undecodable payload (`Postcard`, including an unknown variant) is rejected and counted, never dispatched. A message that is invalid for the current session phase is rejected too. Unknown capability bits are preserved and ignored.
- Sequence policy: a duplicate `seq` does not re-apply side effects, a gap is counted and the newer frame accepted, wrap `0xFFFF` to `0` is normal. USB CDC is ordered, so there are no retransmits. This is not enough for a firmware-image transfer protocol, which would need its own offsets and acks.
- Frame and blob format changes (asset format v2) require updating desktop and firmware together.

### Firmware update and recovery

- The webview only ever asks for "flash the bundled image" (`flash_firmware`) or "restore" (`restore_firmware`). Ports, paths and `espflash` output never leave the native process. `FirmwareStatus` carries a phase, a safe message, the image size, a `failure` token, the bundled version and an update `advice` token; the UI owns all wording.
- Sidecar lookup (`find_espflash`): `espflash[.exe]` beside the application executable first (where the installer puts it). `PATH` and `~/.cargo/bin` are searched only when built with the `device-studio` feature (the dev default). Release builds use `--no-default-features`, so they never run whatever `espflash` sits on `PATH`. A missing tool is `ToolMissing`. The installer bundles the pinned binary (see Release pipeline).
- Flash: on `FlashFirmware` the device task sends `Bye(FirmwareUpdate)` (only when `supports_host_takeovers()`, so the panel shows Updating), drops the serial handle, runs `espflash` and then waits up to 20 s for the same port to handshake. The device identity must match (`FlashTarget::Verified { port, hash }`), so a swapped board is not reported as success.
- Failures: stderr is captured in-process through a reader thread, bounded to the last 8 KiB, classified by the pure `classify_espflash(exit, stderr)` and dropped; it is never logged or emitted. Classes: `ToolMissing`, `PortBusy`, `NoDownloadMode`, `Timeout`, `Cancelled`, `ImageUnavailable`, `ReconnectTimedOut`, `Unknown`. Matching is conservative (case-insensitive fragments of known `espflash` 4.x and OS messages); anything else is `Unknown`. Refresh the fixtures from real output in the hardware session.
- Recovery: a unit that cannot handshake (wrong-major firmware, or held in ROM download mode with BOOT) is restored with `FlashTarget::Recovery { port }`. `request_recovery` refuses unless exactly one allowlisted (`DEFAULT_ALLOWLIST`) port is present, so the flasher cannot be pointed at the wrong board. After the flash, any compatible device on that port is accepted and its new short hash recorded. A flash requested while the connection is `incompatible` takes this path too. A verified flash still rejects a different hash.
- Version advice: `build.rs` scans the embedded firmware image (`KIVORI_FIRMWARE_PATH`) for `KIVORI-FW-VERSION:<x.y.z>\0` with the pure `scan_firmware_version` and sets `KIVORI_BUNDLED_FIRMWARE_VERSION` (empty with no firmware). `update_advice(device, bundled)` returns `UpToDate`, `UpdateAvailable`, `DeviceNewer` or `Unknown`. It is advice only: nothing flashes without an explicit request.

### Host takeovers (protocol 1.5, `HOST_TAKEOVERS_V1`)

- `ByeReason` gains `HostSleeping` (3) and `FirmwareUpdate` (4), appended after the original three. The desktop sends them only when `Session::supports_host_takeovers()`; an older device never sees them. `Session::close(link, reason)` writes the `Bye` and ends the session. The desktop sends `Bye(HostSleeping)` on suspend (see Host presence) and `Bye(Shutdown)` on Quit; the flash sends `Bye(FirmwareUpdate)` first (see Firmware update and recovery).
- `Bye(HostSleeping)`: the device shows Sleeping and keeps showing it across the link loss that follows (`DeviceEvent::HostSleep` latches it). A new `Hello` clears the latch. Without the capability negotiated, the reason acts like any other `Bye` and the device goes Offline.
- `Bye(FirmwareUpdate)`: the device drops to Offline and the runtime renders the Updating screen (`render_updating`; below recovery, above the pose). It lapses after 120 s (`UPDATING_MAX_MS`) so it cannot stick if the host dies, and a new session ends it at once.
- Host-silence timeout: with an accepted session and no valid inbound frame for 4 s (`HOST_SILENCE_MS`), the firmware calls `link_lost` and goes Offline. The desktop pings every second (`HEARTBEAT_INTERVAL`), so a killed or crashed desktop never leaves a frozen "connected" frame. This applies to every session, whatever was negotiated.
- The firmware version comes from the firmware crate's own `Cargo.toml` (1.3.0) and is also embedded as `KIVORI-FW-VERSION:<ver>` text in the image.

### Messages (tag = postcard variant index)

| Tag | Message | Dir | Payload | Capability |
|---:|---|---|---|---|
| 0 | `Hello` | D to V | desktop_version, desktop_caps, nonce | |
| 1 | `HelloAck` | V to D | device_caps, device_id, firmware_version, nonce_echo | |
| 2 | `Ready` | D to V | negotiated_minor, negotiated_caps | |
| 3 | `Bye` | both | reason (`IncompatibleVersion`, `Shutdown`, `ProtocolError`, `HostSleeping`, `FirmwareUpdate`) | `HOST_TAKEOVERS_V1` for the last two |
| 4 | `SetState` | D to V | desired (`SendableState`), at_ms (optional) | |
| 5 | `StateReport` | V to D | reported (`CompanionState`), elapsed_ms | |
| 6 | `Ping` | D to V | t_ms | |
| 7 | `Pong` | V to D | t_ms_echo, uptime_ms | |
| 8 | `Health` | V to D | free_bytes | |
| 9 | `Diagnostic` | V to D | category, code | |
| 10 | `Error` | both | category, code | |
| 11 | `PlayMascotAction` | D to V | action, personality, seed | `MASCOT_INTERACTION` |
| 12 | `MascotActionApplied` | V to D | action, personality, seed, applied_at_ms | `MASCOT_INTERACTION` |
| 13 | `InputEvent` | V to D | session, gesture_id, control (`Rotary`), kind, device_ms | `PHYSICAL_INPUT_V1` |
| 14 | `Presentation` | D to V | session, revision, primary, value (optional), transient_ms | `PRESENTATION_V1` |
| 15 | `Status` | D to V | session, `DeskStatus` | `DESK_STATUS_V1` |
| 16 | `Feedback` | D to V | session, action, kind | `ACTION_FEEDBACK_V1` |
| 17 | `MediaInfo` | D to V | session, `Option<MediaInfo>` (title, artist) | `MEDIA_INFO_V1` |
| 18 | `ControlLabels` | D to V | session, `ControlLabels` (rotate, press, hold) | `CONTROL_LABELS_V1` |

`InputEvent.control` is `Rotary`, `Button` or `ContextButton(0..3)` (the three contextual buttons, left to right; needs `CONTEXT_BUTTONS_V1`; `Press` and `Hold` only, an index of 3 or more is rejected). With `Rotary`, `kind` is `GestureStarted`, `Detent(Cw|Ccw)` or `GestureEnded`; with `Button` (needs `BUTTON_INPUT_V1` too), it is `Press`, `Hold` or `DoublePress` (needs `DOUBLE_PRESS_V1`), sent once per gesture. The desktop rejects a kind that does not belong to its control. `Presentation.primary` is `Idle, Active, Error, Unknown`. `value` is `{ kind: Volume, current_percent, confidence, at_boundary }`.

`DeskStatus` (`kivori-model::desk`) is `{ mode, clock, volume_percent, muted, media, cpu_percent, ram_percent, high_load }`; every value is an `Option` and `None` is rendered as unknown. `mode` is `Buddy, Clock, Volume, Media, System`; `media` is `Playing, Paused, Stopped`. `Feedback.kind` is `Processing, StateConfirmed, ExecutionConfirmed, Unverified, Error` and `action` is `Volume, PlayPause, Mute, Shortcut, Launch`. `MediaInfo` text is `MediaText`: at most 32 ISO-8859-1 characters (what the device's Latin-1 font can draw), sanitized on the desktop (other characters become `?`, control characters dropped, a cut ends in `~`). `ControlLabels` holds one `MediaText` per control (rotate, press, hold, and the three contextual buttons, empty until that hardware lands), derived on the desktop from its live bindings (`Bindings::labels`) and sent once per session and again when a binding changes; an empty label means "draw nothing", never a guess. Status, feedback, media info and control labels are session-scoped like `Presentation`: the device drops any from another session and forgets them all on every session boundary.

| Bit | Capability |
|---:|---|
| 0 | `MASCOT_INTERACTION` |
| 1 | `PHYSICAL_INPUT_V1` |
| 2 | `PRESENTATION_V1` |
| 3 | `BUTTON_INPUT_V1` |
| 4 | `DESK_STATUS_V1` |
| 5 | `ACTION_FEEDBACK_V1` |
| 6 | `DOUBLE_PRESS_V1` |
| 7 | `MEDIA_INFO_V1` |
| 8 | `CONTROL_LABELS_V1` |
| 9 | `CONTEXT_BUTTONS_V1` |
| 10 | `HOST_TAKEOVERS_V1` |

`Capabilities` is a `u32` set in `kivori-model`. Bits are allocated centrally and never reused.

## 3. Desktop and webview IPC

The webview may call only these commands and listen to these events. No command exposes raw serial bytes, port choice, filesystem, shell, environment, raw `device_id`, or the network. DTOs carry no internals (device id is a short hash only). TS wrappers live in `apps/desktop/src/lib/ipc/`.

| Command | Purpose | Build |
|---|---|---|
| `get_app_info` | App version, protocol version, supported majors, Device Studio flag | all |
| `get_connection_status` | Connection, desired, reported, device info, retry count, connection generation, negotiated mascot flag, last mascot action, `host` (`active, locked, sleeping`) | all |
| `list_states` | Companion states | all |
| `set_desired_state` | Set `desired`; sends `SetState` when connected | all |
| `get_onboarding`, `complete_onboarding`, `restart_onboarding` | First-run state (`completed`), finish it, reopen it ("Run setup again"); see First-run onboarding | all |
| `get_accessibility`, `request_accessibility`, `open_accessibility_settings` | macOS Accessibility status (`granted, missing, notApplicable`), the system prompt, and the settings pane; see First-run onboarding | all |
| `get_startup_settings`, `set_launch_at_login` | Launch-at-login state and switch (`startup://changed`); see Launch at login and tray | all |
| `get_config` | Saved settings: `version`, `revision`, `notice`, `profiles` (every profile as resolved, each slot with `deviceLabel` and `overridden`), `display`, `buddy` | all |
| `set_display_settings` | `defaultView`, `secondaryView` (a view, or `cycle`); returns the config | all |
| `set_buddy_settings` | `reactions`, `intensity` (`low, normal, high`); returns the config | all |
| `set_binding` | `profile`, `control` (`press, hold, button1Press, button1Hold, button2Press, button3Press, button3Hold`), `slot` (a replacement slot, or `null` to reset it); `button2Hold` is refused (reserved for the profile pin); returns the config | all |
| `set_rotate` | `profile`, `rotate` (`systemVolume` or `shortcuts`, or `null` to reset); returns the config | all |
| `reset_profile` | `profile`; drops every override of that profile; returns the config | all |
| `reset_config` | Every setting back to its default; returns the config | all |
| `save_macro`, `delete_macro` | Create or replace a macro by id; delete one (refused while a binding names it); returns the config | all |
| `play_mascot_action` | `greet, pet, tickle, surprise, comfort` | all |
| `get_activity_log` | Newest N activity records | all |
| `get_diagnostics` | None; returns `DiagnosticsDto` (see Diagnostics) | all |
| `get_firmware_status`, `flash_firmware`, `restore_firmware` | Firmware update status, update request and recovery request (no arguments, no port or path) | all |
| `render_preview_frame`, `open_preview_stream`, `update_preview_stream`, `ack_preview_frame`, `close_preview_stream` | Native-rendered RGBA frames for Device Studio | `device-studio` only |
| `mirror_state` | Dev-labelled `set_desired_state` | `device-studio` only |
| `get_desk_status` | Display mode, monitored values (`null` = unknown), Press/Hold bindings, last action outcome | all |
| `set_display_mode` | `buddy, clock, volume, media, system` | all |
| `list_action_catalog` | Every bindable action with `slot`, `scope`, `verification`, `params`, `availability`, `reason`, `runsWhenProtected`. Availability is the device thread's latest backend snapshot (system volume and per-app volume); until its first publish, and for key input, it is what the OS is expected to provide | all |
| `test_action` | `action` (an `ActionSpec`, validated natively like a saved binding); runs it now through the device thread, exactly as if its control fired. Returns nothing: the outcome arrives in `desk://status` `lastAction`. A protected foreground refuses everything but system actions | all |
| `test_rotate` | `rotate` (a `RotateSpec`, validated natively). Tests the knob once: a volume knob (system or one app) steps one detent up and back to exactly where it was (down first when already at the top), so the net change is zero; a shortcut pair sends its clockwise shortcut once. Same outcome path and Protected rule as `test_action` (the shortcut is refused, a volume nudge injects no keys and runs). The UI counts down 3 seconds first for a shortcut pair | all |

| Event | Payload | When |
|---|---|---|
| `connection://status` | `ConnectionStatusDto` | Any change to connection, desired or reported |
| `activity-log://event` | `ActivityEventDto` | A new activity record |
| `desk://status` | `DeskStatusDto` | Any change to the desk projection |
| `config://changed` | `ConfigDto` | After every successful save or reset |
| `startup://changed` | `StartupSettingsDto` | After launch at login changes, from the tray item or `set_launch_at_login` (the OS entry's state) |

- Events are small JSON. Frame bytes travel as raw RGBA8888 (240x240, no JSON or base64) through a `tauri::ipc::Response` or a `Channel<ArrayBuffer>`. The canvas only blits. RGB565 to RGBA happens in Rust.
- Dev-only commands are compiled out of release builds, and so is the Device Studio route.
- Preview animation input: `{ initialState, events: [{ atMs, state }], actionEvents: [{ atMs, action, personality, seed }] }`, at most 256 events, integer milliseconds. Supplying it selects externally clocked playback, which supports pause, step and backward seek. Streaming keeps at most two in-flight frames and drops frames that were superseded while rendering.
- `connectionGeneration` changes whenever device uptime may have reset. Device Studio maps applied-action acknowledgments onto its own monotonic clock per generation.

## 4. Timing, rendering and assets

### Timing (ADR-0003)

- Canonical time is integer `elapsed_ms: u32`. The renderer never sees wall-clock time or floats.
- Device Studio keeps an integer step index `n` and derives `ms = (n * 1000 + 15) / 30`. It never accumulates a float, so it has no drift.
- Per-scene frame selection: `floor(elapsed_ms * num / (1000 * den)) mod frame_count`. The 30 FPS step is only an inspection cadence.
- Implementation: `crates/kivori-model/src/timeline.rs`. Negative indices clamp to 0 and results saturate at `u32::MAX`.

### Rendering path

- `render_scene(blob, scene, elapsed_ms, tile)` composites into an RGB565 tile with integer math only. Stitched tiles must equal the full-frame output.
- In simulation firmware can render through small tile buffers. On the physical ST7789 it stages one full RGB565 pose (115,200 bytes, 112.5 KiB) in static SRAM, then sends only changed 40x40 tiles by SPI DMA. Composing and hashing never overlap the transfer. Tile hashes (`kivori-framebuffer`) skip unchanged tiles.
- The unwired TE pin means no refresh sync, and this is not panel double buffering.
- Golden frames (`tests/golden-frames`) pin frame hashes across OSes. An intentional pixel change updates the goldens in the same change.

### Assets (ADR-0004)

- SVG is a build input only. `tools/asset-compiler` (pinned `resvg`/`tiny-skia`, stable ordering, no timestamps) writes a byte-reproducible blob. CI recompiles and diffs its hash.
- Blob: fixed header (magic, `format_version` = 2, offsets, hash), a postcard structured section (scenes, layers, keyframes, tables) loaded into bounded `heapless` structures, and a data pool read zero-copy from flash.
- Format v2: sprites are cropped RGB565 with an optional packed alpha4 pool. Layer roles: `Static, Body, Eyes, Mouth, Cap`. Readers reject v1 blobs. The mascot pack is capped at 128 KiB at build time.
- Bitmap fonts are compiled into the blob, so text does not depend on host fonts.
- Layers use integer keyframe transforms and sprite-frame selection. Generic layers are step-held. The mascot uses Q8 fixed-point transforms and cubic smoothstep.

### Mascot: the keycap buddy

- Layers, in draw order: `Body` (the fixed base: side walls and front lip), `Cap` (top face, upper wall wedges, legend), both eyes, then the mouth. Base and cap are shared by all six states. One eye texture serves both eyes.
- `face::buddy_face(state, view)` (`kivori-model`, #13) maps observed desk truth to a face override (Error, celebrate, Strained, Muted, Listening, Attentive; rules in product.md). The firmware applies it to the pose on the Buddy view only. Faces are eye/mouth sprite frames compiled from `assets/mascot.svg`; the blob is ~126 KB of its 128 KiB cap, so new faces need art or crop trimming first.
- A pose's `press_q8` sinks the cap and the face printed on it while the base stays put, so the walls visibly shorten. Happy holds a 16 px press.
- `MascotAnimator` (in `kivori-model`) resolves blinking, per-state motion, and eased transitions (350 ms, 600 ms into sleep). Expression changes are hidden inside a blink. Firmware keeps the animator between state changes and renders through the same compositor as Device Studio.
- Volume overlay room: `MascotPose::with_overlay_room` scales the body by 0.72 (184/256) and lifts it 34 px so the keycap sits above the bar. The switch is instant, not eased.

### Companion and personality rules

- Personalities: `cozy` (default), `playful`, `calm`. They scale motion amplitude and the self-play interval (calm 18-30 s, cozy 8-16 s, playful 4-8 s). They never change the reported state.
- Reactions: `greet, pet, tickle, surprise, comfort`. The companion director (desktop) runs self-play only in `idle` and `happy`. Device Studio reactions are forwarded to a connected device that negotiated `MASCOT_INTERACTION`.
- Personality never looks like a desktop state. No reaction may use the same `(eye_frame, mouth_frame)` as any state face. A test enforces this.
- A state change interrupts a running reaction.
- Reactions over `busy`, `booting` and `offline` are refused (`CompanionState::allows_reaction`). Firmware sends no `MascotActionApplied` for a refused one, so the desktop never assumes it played. A poke over `sleeping` gives a sleepy `Affectionate` response, then returns to sleeping.
- Higher layers win. When v1 adds Success and Error primary states, rerun the face-uniqueness check.

## 5. Rotary volume loop

```text
HW-040 A/B/SW -> InputSource port -> QuadratureDecoder -> RotaryGesture -> InputEvent (tag 13)
  -> wire -> Session decode -> InputIngress -> resolve_binding -> apply_step
  -> GestureValue -> VolumeBackend -> PresentationResolver -> Presentation (tag 14)
  -> wire -> firmware expires value after transient_ms -> render_volume_overlay -> panel / preview
```

Everything between the two hardware adapters (`PhysicalRotary` in firmware, the Windows backend on the desktop) is a pure function or state machine and is host-testable.

- Input port: `InputSource::sample() -> { a, b, sw }`. `PhysicalRotary` only reads and inverts the pins. All three lines are active-low with internal pull-ups. Pins: CLK GPIO4, DT GPIO5, SW GPIO10 (the push switch, read since M1). GPIO9 is avoided because it is the BOOT strap. Power the HW-040 from 3V3, not 5V. This pin map is a specification until a dated physical check closes it (see validation.md).
- Decoder: a Gray-code state machine on phase `(a << 1) | b`, resting at `00`. It emits a `Direction` only when the knob returns to rest after four quarter-steps in one sense. The accumulator resets at every rest arrival. Bounce and partial motion emit nothing. An impossible transition (both bits change) is counted as `invalid_transitions`, resets the accumulator, and is a diagnostic only.
- Gesture: the first detent opens a gesture (`gesture_id`, unique within the session, never 0). 250 ms without a detent (`GESTURE_END_MS`) emits exactly one `GestureEnded`. A direction reversal does not split a gesture.
- Ingress: `InputIngress` rejects an event with a stale session (`StaleSession`). It also requires an observed `GestureStarted` before a `Detent` or `GestureEnded` (`UnknownGesture`), as defence in depth.
- Freshness (#26, `input/freshness.rs`): `Session` turns each `Pong` into a device-to-host clock offset (`uptime_ms` plus half the round trip, against the host time the `Pong` was read; the latest sample with a round trip of at most 500 ms wins, wrapping `u32` arithmetic throughout) and clears it on every session boundary. `RotaryPipeline::accept_inputs_fresh` runs after the session and gesture checks: a discrete `LogicalInput` (`Press`, `Hold`, `DoublePress`, `ButtonPress`, `ButtonHold`) whose age (host receive time converted to device time, minus `InputEvent.device_ms`) exceeds `MAX_ACTION_AGE` (750 ms) is dropped and logged as `InputStale` (no payload), with no device feedback, like other rejected input. Detents and gesture boundaries bypass the check. With no offset yet there is no age and nothing is dropped. The age left over (`remaining`) becomes the job's deadline in `ActionWorker`, whose single queue a slow launch can stall: a job dequeued past its deadline is skipped, logged as `InputStale` and its pending feedback cancelled. A stale action is dropped before `DeskRuntime::on_input`, so a focus or Protected change during a backlog cannot send it to the new app. Knob-shortcut detents carry no deadline.
- Binding and step: one global binding, rotate to master volume (`action::resolve_binding`). `apply_step` moves 2 points per detent (`BASE_STEP_PERCENT`), clamps to 0-100 and flags a boundary.
- `GestureValue` (preview to confirmed):
  - While a gesture is open it owns the displayed value. Each detent applies locally and is shown as `Preview`, even if the backend set succeeded.
  - At `GestureEnded` the desktop reads the value back and reconciles the display to it as `Confirmed`. Desktop truth wins.
  - An external change during a gesture is recorded but not drawn over the preview. An endpoint switch marks the gesture abandoned so it is not retargeted.
  - `Unverified` means the set was dispatched but the read-back failed.
- `VolumeBackend` trait: `availability`, `read`, `set` (returns the OS read-back value, so `StateConfirmed` is honest).
  - Windows: Core Audio `IAudioEndpointVolume` on the default render endpoint (`eRender` + `eConsole`). A dedicated `kivori-audio` thread owns COM and both callbacks (`IAudioEndpointVolumeCallback`, `IMMNotificationClient`). Callbacks only post to a channel. Kivori writes carry a Kivori GUID, so its own echo is ignored while external changes and endpoint switches are applied.
  - macOS: CoreAudio (see Chosen platform APIs). It has no event-context GUID, so a notification is tagged `Kivori` when it matches Kivori's own write within 250 ms.
  - Linux: `NotImplementedYet { target }`. A deterministic `FakeVolumeBackend` runs all host tests.
- `AppVolumeBackend` trait (per-app volume and mute): `availability`, `read(app)`, `set(app, pct)` (returns the read-back), `read_mute(app)`, `set_mute(app, muted)`, and `AppVolumeError::{NoSession, ReadBackUnavailable, Os}`. `app` is the lowercase foreground-style id (Windows: the executable file name, `spotify.exe`).
  - Windows: the same `kivori-audio` thread, through `Command::App*` arms (`platform/windows/app_volume.rs`). It takes the default render endpoint, `IAudioSessionManager2::GetSessionEnumerator`, then per session `IAudioSessionControl2::GetProcessId` and `QueryFullProcessImageNameW` for the lowercase exe file name (a session it cannot inspect, such as an elevated process, is skipped). Every matching session is written with `ISimpleAudioVolume::SetMasterVolume(level, &KIVORI_EVENT_CONTEXT)` and read back; the result is confirmed only if all read-backs agree, otherwise `ReadBackUnavailable` (Unverified). No session, or no endpoint, is `NoSession`.
  - macOS: `Unsupported { reason: "Per-app volume isn't available on macOS" }`; Linux: `NotImplementedYet`. `FakeAppVolumeBackend` runs all host tests.
  - Keep three ideas apart: `BackendAvailability` (implemented or not), `ConfirmationClass` (`StateConfirmed`, `ExecutionConfirmed`, `TriggeredUnverified`), and the derived `ActionAvailability`. An OS-level `PlatformCapability` is not a type: "this OS cannot do it" is `ActionAvailability::Unsupported { reason }`, decided by the action catalog.
- Presentation: `PresentationResolver` is a pure function from `ProductSnapshot` to `Presentation`. `value` is a transient overlay of 800 ms (`VALUE_TRANSIENT_MS`). Firmware expires it locally, so the overlay clears without a host timer. Firmware stores `primary` but does not render it; a failed volume write is shown through `Feedback { Volume, Error }` instead (section 5b).
- Overlay: `render_volume_overlay` (`kivori-renderer/src/overlay.rs`) draws a solid-rect bar with no glyphs. `Confirmed` is a solid fill, `Preview` is hollow (top and bottom rows only), and the track outline turns white at a boundary. It is composited over the mascot in the same tile pass.
- Firmware owns raw input truth (conditioning, detents, gestures). The desktop owns action meaning.
- Edge capture: every edge on CLK, DT or SW raises the GPIO interrupt, whose handler only stores a timestamped level snapshot in a 128-entry queue (`physical_rotary.rs`). The run loop drains it each tick (`InputSource::drain`), so quarter-steps and switch edges during a frame compose or flush are not lost. On overflow new edges are dropped: the decoder counts one invalid transition, which can lose a detent but never invents one.
- Latency: the firmware renders on the tick a `Presentation` or `Feedback` arrives instead of waiting for the 33 ms frame cadence, and the desktop device thread blocks on serial bytes (bounded by its 50 ms tick) instead of sleeping. Row 3.14 measures the result.
- Every `SetState` is answered with a `StateReport` of the current state, changed or not, so a reconnecting desktop always learns it.

## 5b. Push switch, recovery hold and desk

```text
SW edge -> InputSource::drain -> ButtonGesture (debounce 20 ms, edge-timed)
  Press (< 500 ms) / Hold (500 ms - 2 s) -> InputEvent{Button} -> InputIngress -> Bindings
  -> ActionWorker (kivori-actions thread) -> Outcome -> FeedbackLadder -> Feedback (tag 16)
  2 s: recovery takeover (time-based progress) ... 10 s from key-down: Bye, software_reset
desktop 1 Hz: CPU/RAM, volume/mute, media, local time -> StatusPublisher -> Status (tag 15)
```

- `ButtonGesture` (`firmware/.../input/button.rs`) is pure and host-tested. Times are measured between debounced edges at the moment the switch first changed, and a release still inside its debounce window stops the hold clock. A press that starts while a rotary gesture is open never becomes Press or Hold (one gesture owns input) but can still recover. While the switch is down, detents are decoded but swallowed (invariant 33).
- The recovery hold needs no host, session or capability (invariant 24). A session boundary drops a half-done press but never a running recovery. On the reboot tick the device renders "Restarting", queues `Bye(Shutdown)` for an accepted session, flushes it for at most 20 ms and calls `esp_hal::system::software_reset`.
- Local acknowledgement: while the switch is down the keycap sinks 8 px (Buddy view) or the screen gets a white frame. This is the device's own < 50 ms acknowledgement, not a confirmation.
- Double press: with `DOUBLE_PRESS_V1` negotiated, a short press waits 250 ms (`DOUBLE_WINDOW_MS`) for a second key-down; two short presses are one `DoublePress`, which the desktop turns into the next display view. A long second press fires the first `Press`, then behaves normally (Hold, recovery). Without the capability a press fires on release with no wait.
- Contextual buttons (GPIO0, GPIO1, GPIO20 to GND, internal pull-ups) are captured by the same edge interrupt and each runs its own `ButtonGesture` with double press off. They never own recovery: a `RecoveryStarted` or `Reboot` from one is ignored, so a long hold fires nothing. One gesture owns all input: a switch going down while any other control is busy (raw or debounced) is ineligible, and knob detents are swallowed while any switch is down.
- Profiles (`desk/profile.rs`, #12): built-in `Profile`s matched by lowercase foreground id. `Context` polls `ForegroundObserver` (`platform/foreground.rs` pure rules; `windows/foreground.rs` Win32 foreground window, input-desktop name and token elevation; `macos/foreground.rs` NSWorkspace via raw Objective-C FFI plus the session lock flag) every 100 ms, commits after 400 ms stable, commits Protected at once, and resolves every input and every `ControlLabels` from one context so labels and bindings never disagree. A knob gesture records its binding (`KnobTarget::{Shortcuts, AppVolume}`) and the focused app at `GestureStarted`; `RotaryPipeline::accept_inputs` hands only system Volume gestures to the volume loop. An App Volume gesture stays in `DeskRuntime`: each detent is an `Action::AppVolumeStep` on the action worker (read, `action::volume::apply_step`, write with read-back), so a fast spin never reaches the batched system-volume path. The detents show nothing one by one: when the gesture has ended and every detent has finished, the device gets one `Feedback { Volume }` at the least-confirmed outcome, or the gesture's single Error (`knob_failure`) if any detent failed. It runs under Protected (it injects no input) and does not follow focus.
- Bindings (`desk/actions.rs`): a `Slot { action: Option<Action>, label: Option<String> }` per gesture; `Bindings` holds Press, Hold and three `ButtonSlots { press, hold }`. `Bindings::default()` is the General profile: Press = Play/Pause, Hold = master mute, Double press = next view (fixed); contextual buttons Press = Previous track, Play/Pause, Next track (media keys, always Unverified), Hold unbound. A button's Hold is bindable, except the middle button's, which `Context::resolve` checks first and keeps for cycling the pin. The device legend shows Press labels only; Hold labels are not on the wire (a later protocol change).
- Layering (`config/resolve.rs`): `resolve(builtins_for(os), &ConfigFile)` takes each built-in `Profile` (`Profile.id` keys the override; names, ids and labels are owned strings) and replaces only the slots an override sets, so untouched controls keep built-in fixes from app updates. A `SlotSpec` replaces the whole slot; `action: null` is an explicit unbind. Validation: labels are 1 to 32 Latin-1 characters (`MediaText`), shortcuts parse with `Shortcut::from_str` and are stored canonical, launch targets pass `launch::validate_target`, `button2Hold` is refused. `ConfigStore` resolves on open (a file that does not resolve is corrupt) and on every save, and caches the `ResolvedConfig`. The override entry is removed when it becomes empty, so a reset leaves no trace.
- Live pickup: after a save the device thread calls `DeskRuntime::apply_config`: `Context::set_profiles` swaps the profiles (the pin and the committed app's profile stay), the display settings are applied, and `sent_controls` is cleared so the next tick re-sends the labels even when they did not change. A knob gesture in progress keeps the keys it recorded at `GestureStarted`.
- Classification (`desk/actions.rs`): mute is State Confirmed only when the OS read-back shows the new state; play/pause and a shortcut are always Unverified (a matching media state can be stale or caused by something else, so it is never proof; the media indicator and view show what the OS reports); a launch is Execution Confirmed once the OS accepted it (`open -a` exit 0 on macOS, process created on Windows; no shell). A missing permission is Error with `permission_required`, never another mechanism.
- Action catalog (`desk/catalog.rs`): `CATALOG` lists every bindable action with its slot (`rotate` or `discrete`), scope (`system, app, media, keyboard, launch, macro`), verification, params and `runsWhenProtected`; `availability(os, &services)` derives `ActionAvailability` per entry (`list_action_catalog` shows it). Verification maps from `ConfirmationClass`: `StateConfirmed` is `confirmed`, `ExecutionConfirmed` is `started`, `TriggeredUnverified` is `unverified` (a macro is `leastOfSteps`). A table test runs each entry's action against the fakes and holds the entry to what `execute` classifies (macros are checked in their own test). Macros are `Available` on every OS (each step is checked when it runs). App Volume and App Mute are `Available` (confirmed) on Windows and `Unsupported` on macOS; pressing a binding that cannot run is an Error and nothing ever falls back to system volume or system mute. `runsWhenProtected` is `Action::is_system()`: system volume, media keys and mute run in a protected context, shortcuts, launches and knob shortcuts do not.
- Macros (`desk/actions.rs`, `config/{schema,resolve}.rs`): `MacroSpec { id, name, steps }` holds at most 8 `StepSpec`s (`Action { action }`, never a Macro, or `Delay { ms: 50..=2000 }`) and a config holds at most 32. `resolve` turns every macro into an `Arc<Macro>` by id and bindings (`ActionSpec::Macro { id }`, discrete slots only) hold the same `Arc`; an unknown id fails `save` and a stored file with one is corrupt on load (backed up, defaults). `execute_macro` runs on the action worker: steps in order, the least-confirmed outcome wins (Error < Unverified < Started < Confirmed), the first Error stops it and nothing is rolled back. Between steps it stops (Error) when the worker epoch moved (`cancel_pending`: the session ended) and before a shortcut or launch step when the foreground became Protected or is no longer the app the macro started in (invariants 9 and 12); a Delay sleeps in 10 ms slices so a cancel is seen at once. A macro is not `is_system`, so it is suspended under Protected like a shortcut. Its wire `ActionKind` is its first action step's kind (`FeedbackLadder::start_as`) and its UI token is `macro`. The #26 dequeue deadline applies unchanged: a macro longer than the device's 1.5 s Unverified window shows Unverified on the device and its late outcome is only logged. `save_macro` replaces by id (bindings keep working and see the new steps); `delete_macro` is refused while any binding names the macro, so nothing becomes unbound silently. `ConfigDto.macros` carries the specs; the UI edits them in `features/controls/MacroEditor.tsx`.
- Action tokens (`ActionToken`): the desktop-only identity used by `lastAction`, the activity log (`DeskAction { action }`) and the DTO tokens (`volume, playPause, mute, shortcut, launch, previousTrack, nextTrack, appVolume, appMute, macro`). `Action::wire_kind()` maps to the wire `ActionKind` for `Feedback`; the wire gains no variants (firmware's postcard decoding rejects an unknown one), so App Volume (`Volume`), App Mute (`Mute`) and macros reuse an existing kind. Metadata never carries keys, a launch target or an app id.
- Test action: `test_action` becomes `DeviceCommand::TestAction`, which calls `DeskRuntime::test`. It classifies Protected from the live foreground first and refuses a non-system action there (Error, no key sent, never a bypass), otherwise it goes through the same worker, feedback ladder and activity log as a device press.
- `FeedbackLadder` (`desk/mod.rs`): Processing at 500 ms, Unverified at 1.5 s, after which a late outcome is logged but not shown. Timeout is never Error. A newer action replaces the pending feedback; a session end clears it, and requests still queued for the worker are skipped (an epoch counter), so nothing from an old session runs later. A new streak of failed volume writes is shown once as a volume Error.
- `StatusPublisher`: sends `Status` when anything shown changes, when the minute rolls over, or every 1 s (bounded recovery from a dropped initial status); the device advances the clock locally in between. High load is CPU at or above 85 % for 3 samples, cleared below 70 % or when CPU is unknown.
- Device rendering order (`firmware/.../render.rs`, `kivori-renderer::desk`): recovery takeover, else the Buddy pose or the selected desk view, then the volume overlay (except in the Volume view, which shows the value itself), then the chrome: mute and media indicators, the high-load cue (Buddy only), the control legend (Buddy only, never shrinking the keycap: with a contextual button bound, the three button labels over ticks pointing at the buttons under the keycap and the knob label top left; otherwise `TURN` / `PRESS` / `HOLD` captions over the labels; three fixed 80 px columns, a label too wide for its column fades at the edge), the press frame and the feedback badge. Unverified is an amber ring with `?`, never a check mark.
- View switch (`desk::render_views`): for `VIEW_TRANSITION_MS` (320 ms) the outgoing view slides up and the new one pushes in from below (integer ease-out cubic). Each view is drawn into a row slice of the tile (`TileBand::split_at_row` + `scrolled`), so the mascot slides like any view, no extra buffer is needed and tiles still stitch to the full frame. The volume overlay and chrome stay fixed above it.

## 6. Activity log, flashing, offline rule

### Activity log (ADR-0005)

The typed session activity log is the only runtime log.

- Every record is an `ActivityEventDto`: native-issued `id`, ISO-8601 `at`, `summary`, and closed `type`, `severity` (`info, warning, error`), `source` (`connection, action, device, protocol, firmware`), `outcome` tokens.
- Optional `metadata` is a fixed allowlist: connection state, retry and elapsed counters, diagnostic category and code, versions, short device hash, capability mask, state, personality, action, seed, protocol counters, reported state. There is no free-form map.
- Never logged: raw payload bytes, raw device id, port or file paths, usernames, tokens, secrets, flasher output, raw error text. The UI reads only the fixed fields.
- Delivery: the webview subscribes to `activity-log://event` first, then calls `get_activity_log(limit)`. It dedupes by id (live copy wins), sorts by id, and keeps the newest 256. Nothing is persisted or uploaded.
- The raw device id stays inside the transport layer. Only a short non-reversible hash may appear.
- Raw payload output exists only behind the `debug-payloads` Cargo feature. It is off by default and must not ship.
- Tests: native redaction tests, frontend runtime-cast privacy tests, ordering and 256-entry retention tests.

### Host presence (sleep, lock, console; M3 S2)

- `platform/host_events.rs` is pure. A per-OS source turns notifications into `HostEvent`s (`Suspending, Resumed, Locked, Unlocked, ConsoleDisconnected, ConsoleConnected`) on a channel the device thread drains next to its commands (`HostSignal`, with an ack channel on `Suspending`). `HostPresenceTracker::on_event` returns the actions to take; an event that changes nothing returns none, so Windows' two resume notices and repeated lock events are harmless.
- Sleep: the OS callback sends `Suspending` and waits at most 500 ms (`SUSPEND_ACK_BUDGET`). The device thread writes `Bye(HostSleeping)` (`Bye(Shutdown)` if the device did not negotiate `HOST_TAKEOVERS_V1`) with `Session::close`, drops the link, clears the connection timers, leaves the manager `Disconnected` with no retry count, then acks. macOS answers `IOAllowPowerChange` after the ack or the timeout; `kIOMessageCanSystemSleep` is allowed at once. While asleep, or while another user session has the console, discovery does not run, so the port is never reopened before the machine is really suspended.
- Wake (`Resumed`): the pending retry is cleared and the candidate rotator is reset, so discovery runs on the next tick with no backoff. A resume with no suspend seen is ignored; the heartbeat covers it.
- Lock: not a link event. The orchestrator gets a host override (`Sleeping`) and the buddy's reactions pause. `Orchestrator::desired()` is the effective state (what is sent and resent on reconnect); `user_desired()` is the user's, which the UI shows and which returns on unlock. Changes made while locked wait behind the override. The knob and buttons keep working; the Protected rules in `foreground.rs` already suspend shortcuts.
- Console loss (Windows fast user switching): the link is released without a goodbye so another user's Kivori can claim the port; `ConsoleConnected` rediscovers.
- Input never runs across a sleep: closing the session discards queued input, and leaving `Connected` ends the session boundary in `synchronize_session` (gesture state, queued actions), so anything made before the sleep is rejected as `NoSession`.
- `ConnectionStatusDto.host` is `locked` while the override is set and `sleeping` while the link is released for a suspend. Activity records: `hostSuspending`, `hostResumed`, `hostLocked`, `hostUnlocked` (source `connection`, info).
- If the OS refuses the registration the app logs one warning and runs without it; the device then falls back to its host-silence timeout and shows Offline.

### Launch at login and tray (M3 S4)

- `tauri-plugin-autostart` is used from Rust only: `init(MacosLauncher::LaunchAgent, Some(["--autostart"]))` and `app.autolaunch()`. There is no JS package and no permission in `capabilities/default.json`, so the webview reaches it only through `get_startup_settings` and `set_launch_at_login(enabled)`. The OS entry (Windows `Run` key, macOS LaunchAgent) is the source of truth: nothing is stored in `config.json`, and each command returns what the OS reports after the change. Its own dependencies (`auto-launch`, `dirs`, `os_info`, registry and `smappservice` bindings) have no network crate.
- Hidden start: `tauri.conf.json` creates the window with `visible: false`. `setup` shows it unless `std::env::args()` contains `--autostart` (`window_lifecycle::launched_at_login`); a login launch starts `WindowLifecycle::hidden()` (tray only, a close request is a no-op, `Reactivated` shows the window). The device task runs either way.
- Tray (`runtime/lifecycle.rs`, id `kivori`): a disabled status line (`Connected`, `Not connected`, `Paused while locked`), `Open Kivori`, a `Launch at login` check item and `Quit`. The tooltip reads `Kivori · Desktop x.y.z · Firmware a.b.c` (firmware only while a device is connected, plus `Update available` when the advice says so). `tray_model(&ConnectionStatusDto, UpdateAdvice)` is pure; `refresh_tray` applies it from the device thread next to `emit_status`, so the tray follows the same snapshot as the UI. The check item is re-read from the OS after each toggle.
- A second launch while Kivori runs still goes to single-instance and surfaces the window.

### First-run onboarding (M3 S6)

- State: `config.json` gains `onboarding: { completed }` (`#[serde(default)]`, still schema v1). `get_onboarding`, `complete_onboarding` and `restart_onboarding` (the last backs the Device page's "Run setup again") read and save it; the two writers go through the normal config path, so they publish `config://changed` like any save.
- Existing users: a file that parses and has no `onboarding` key was written before the field existed, so `ConfigStore::open` loads it as `completed: true` and the stored settings are never questioned. A missing file (fresh install) or a file that is recovered as corrupt or newer starts at `completed: false`, so first-run setup shows once and can always be skipped. A file that does name the field is taken at its word. `reset` keeps `completed` as it was, so "Reset all settings" does not send anyone back through setup. Downgrading to a build older than this field makes the strict parser set the file aside as corrupt (the known M2 consequence of `deny_unknown_fields`, only before the beta).
- Permissions (`platform/permissions.rs`): `accessibility()` (`AXIsProcessTrusted`), `request_accessibility()` (`AXIsProcessTrustedWithOptions` with the prompt option, so macOS shows its own dialog) and `open_accessibility_settings()` (`/usr/bin/open` with one fixed `x-apple.systempreferences:` URL, no caller input) return `Granted`, `Missing` or `NotApplicable` (every other OS). The FFI is declared by hand like the other macOS code. The webview reaches them through `get_accessibility`, `request_accessibility` and `open_accessibility_settings`, which return the tokens `granted`, `missing`, `notApplicable`.
- Diagnostics: the "input permission" row reads `accessibility()` (cached for a second in the device loop): `granted` or `required` on macOS, `notNeeded` elsewhere, and `required` also while the last desk action was refused by the OS.
- UI (`features/onboarding/`): while `completed` is `false`, `App.tsx` renders `Onboarding` instead of the sidebar layout (until the native answer arrives, which is a few milliseconds, the normal layout shows). Steps: Welcome, Plug in, Permissions, Tour, Make it yours, Done. A step moves on only from real status (connected, Accessibility granted, a control seen on the device) or its Skip button, and "Skip setup" is always in the header. Plug in follows `ConnectionStatusDto`; an incompatible device, or three or more failed reconnects (`needsRecovery`), offers the S3 `RecoveryDialog`, and the update hint appears when the advice says `updateAvailable`. Permissions is dropped from the step list when `get_accessibility` says `notApplicable` (Windows). The Tour needs no new input event: `useTour` watches `desk://status` and ticks Turn the knob on a change of `volumePercent`, then Press the knob and Press a button on a new settled (not `processing`) `lastAction`, in that order. A repeated identical action does not change the status, so the button hint asks for the side buttons. Make it yours saves the default view and buddy intensity immediately (`setDisplaySettings`, `setBuddySettings`); Launch at login is on by default but is only applied (`set_launch_at_login`) when the person presses Finish, and not at all on Skip setup.

### Config

- One JSON file, `config.json`, in the per-user app data directory (`app_local_data_dir`: `%LOCALAPPDATA%\id.immer.kivori` on Windows, `~/Library/Application Support/id.immer.kivori` on macOS). It is Local, not Roaming, so settings stay per user and per machine. Installers never touch it. A missing file means defaults, and nothing is written until the first change.
- Atomic write: write `config.json.tmp` in the same directory, flush it to disk, then rename it over `config.json` (retried 3 times, 50 ms apart, for antivirus locks). There is no non-atomic fallback. A stale `.tmp` is deleted at load.
- Save first, then apply: a command validates and saves, and only then sends the new config to the device thread. A failed save changes nothing and returns a fixed, path-free error.
- Recovery (`ConfigStore::open` never fails): a file over 256 KiB, not JSON, without a numeric `version`, with an unknown field or an invalid value is renamed to `config.corrupt-<unix_secs>.json` and defaults are used (`notice: recoveredCorrupt`). A `version` above this build's is renamed to `config.v<N>-<unix_secs>.json` with its bytes intact (`recoveredNewerVersion`). The newest 5 of these backups are kept. Each recovery is a `configRecovered` activity record and a `notice` on `ConfigDto`. Paths never cross IPC.
- Versioning: `version` is read first. An older file is copied to `config.v<old>.bak`, migrated step by step (`config/migrate.rs`, one function per version) and written back (`notice: migrated`). The schema rejects unknown fields, so during M2 new fields stay in version 1 with `#[serde(default)]`; after the beta ships, any field change bumps `CONFIG_VERSION`.
- Reset copies the current file to `config.before-reset.json` (one slot) and writes defaults.
- The file holds `profiles` (sparse overrides by profile id: `rotate`, `press`, `hold` and three `buttons` of `press` and `hold`) and `macros` (at most 32, see Macros), `display` (`defaultView`, `secondaryView`) and `buddy` (`reactions`, `intensity`). Intensity is the mascot personality: low, normal, high are calm, cozy, playful. Reactions turn the companion director's self-play on or off. A double press toggles between the default and the chosen view (from any other view it returns to the default), or steps through every view when `secondaryView` is `cycle`.

### Diagnostics

- `get_diagnostics` returns `DiagnosticsDto`, shown as a card on the Device page (polled every 1 s while visible) and copied as JSON by "Copy diagnostics". Groups: `versions` (app, firmware, protocol, negotiated minor, capability names, short device hash), `connection` (state, connected-for, reconnects, retry count, last pong age, round trip), `health` (device uptime, free SRAM, malformed frames, sequence gaps, device errors), `host` (system volume, app volume, media observation, focus detection, input permission) and `config` (status, schema version, custom bindings, macros). Unknown values are `null`.
- Privacy: no ports, paths or raw device ids. The device appears only as its short hash. A DTO allowlist test pins the serialised keys.
- Sources: `Session` keeps `Health.free_bytes`, `Pong.uptime_ms` with its receive instant, and counters for malformed frames, sequence gaps and device `Error`s. All of it is connection-scoped and reset by `Session::open` (the free-memory and uptime figures also clear when the link drops). The round trip comes from `HeartbeatMonitor` (`on_ping_sent(t_ms)`, `on_pong(t_ms_echo, now_ms)`), taken only from the echo of the latest ping.
- The device thread writes a `DiagnosticsSnapshot` (raw figures and `Instant`s) at most once a second; `get_diagnostics` turns it into ages and adds the config summary from the config store at read time. Host-service tokens come from the live backends (`available`, `unsupported`, `unavailable`; media `observable`; focus `detecting`; input permission `required`, `granted`, `notNeeded` or `unknown`). Input permission is `granted` or `required` on macOS (from the Accessibility check, see First-run onboarding), `required` also after the OS refused synthesized input, and `notNeeded` elsewhere.
- Firmware update advice (bundled version, update available) belongs in `FirmwareStatus` (M3); diagnostics will read it from there rather than duplicate it.

### Firmware flashing from the app

- Overview has a Flash firmware button, enabled when connected and no update is running. `flash_firmware` takes no arguments. It installs only the firmware embedded in the desktop build.
- Native flow: reject a disconnected or concurrent request, release the serial port, run `espflash` on that port with verification on, wait for a compatible handshake from the same device, then report `succeeded`. Failure returns `failed` and connection handling resumes. Accepting a request is not completion.
- `FirmwareStatusDto`: `available`, `phase` (`idle, preparing, flashing, reconnecting, succeeded, failed`), `message`, `imageSize`. The UI polls it every 750 ms. Timeouts: flash 90 s, reconnect 20 s.
- Embedding: `scripts/build-desktop-firmware.ps1` builds the firmware release ELF with `physical-st7789`, then builds the desktop with it embedded. For other pipelines set `KIVORI_FIRMWARE_PATH`. The build rejects a non-RISC-V or non-ELF32 image. A host build without the variable disables the action, so a stale artifact cannot slip in.
- `espflash` is the pinned sidecar shipped in the installer (dev builds may use one on `PATH`). Mirror to device sends a state command only. It does not install anything.

### Release pipeline (M3 S5)

- Versions: the Cargo workspace version is the only app version. `tauri.conf.json` has no `version`, so Tauri takes it from `kivori-desktop`; the installer name, `CFBundleShortVersionString` and the tag check all follow it.
- Config split: the base `tauri.conf.json` stays dev-safe (`bundle.active: false`, no `externalBin` or `resources`), because Tauri's build script checks those paths at compile time and would break every dev and CI `cargo build`. Packaging lives in `tauri.release.conf.json` (NSIS, per-user install, embedded WebView2 bootstrapper, the `espflash` sidecar, `THIRD_PARTY_NOTICES.md`) and `tauri.release.macos.conf.json` (app and dmg, the adapter resource, `Info.plist`, `Entitlements.plist`, hardened runtime), merged with `tauri build --config`. Release builds pass `-- --no-default-features`, so Device Studio and the PATH fallback are compiled out.
- Sidecar: `scripts/fetch-espflash.{sh,ps1}` download espflash 4.6.0 from the official GitHub release, check a pinned SHA-256 and write `src-tauri/binaries/espflash-<triple>[.exe]` (gitignored). Tauri installs it as `espflash[.exe]` next to the app, which is where `find_espflash` looks first. Bump the version and hashes together, in both scripts and `release.yml`.
- Windows: `.github/workflows/release.yml` builds the firmware ELF on Ubuntu, then on Windows builds the NSIS installer with `KIVORI_FIRMWARE_PATH`, runs `check-release-surface.sh --desktop-artifact` (dev symbols absent, firmware version marker present), silently installs, checks the exe and `espflash --version`, runs the startup smoke test with `--autostart`, and silently uninstalls. `nsis/hooks.nsh` removes the HKCU `Run\Kivori` value that `tauri-plugin-autostart` writes; the workflow plants that value before uninstalling to prove it. A `v*` tag (which must equal the workspace version) uploads the installer and `SHA256SUMS` to a draft GitHub release. Nothing is published automatically.
- Signing is not implemented: the installer is unsigned and a placeholder step (repository variable `WINDOWS_SIGNING`) fails closed until owner certificates exist (#36). Unsigned binaries trigger SmartScreen, and Defender may flag `espflash.exe`.
- macOS (ADR-0009): `scripts/bundle-macos.sh` is the main path; CI only builds it on a manual dispatch. The adapter is staged by `build.rs` in `target/release/mediaremote-adapter/` and bundled to `Contents/Resources/mediaremote-adapter`, which is what `adapter_dir()` resolves. With `APPLE_SIGNING_IDENTITY` set the script signs the two Mach-O helpers, then the app, with hardened runtime. Notarization is not done.

### Offline-first rule

Core function needs no internet, cloud, CDN, telemetry or licence check. Discovery, handshake, reconnect, rendering, Device Studio, state control, the activity log and app launch all work offline.

- No first-party crate may depend on a network client. Firmware, shared crates and the webview never get network access.
- The webview loads no remote scripts, styles, fonts, images, fetches or sockets (localhost in dev is the exception).
- No telemetry, and no startup wait on the network.
- If update discovery is added, it goes in one isolated native module, and the guards are narrowed for that module only.
- Guards: `scripts/check-offline-deps.sh`, `scripts/check-frontend-offline.mjs`, `apps/desktop/src-tauri/tests/offline_smoke.rs`.

## 7. Decisions

- **ADR-0001 Two cargo workspaces.** The root workspace holds the host crates, the desktop, tools and tests. `firmware/esp32-c3` has its own `[workspace]` and reaches shared crates by path. Because one workspace unifies features, and a std feature enabled by the desktop would silently break the firmware `no_std` build. The firmware also needs its own target, panic strategy and runner.
- **ADR-0002 One wire protocol crate.** COBS framing, CRC-32, postcard payloads, an append-only `Message` enum, major-gated compatibility, minor and capability negotiation. Because both peers share one schema, COBS resyncs after corruption where a length prefix cannot, and postcard is `no_std` with a stable format. Reordering or removing anything is a major change.
- **ADR-0003 Integer-millisecond timebase.** Time is `u32` ms, and Device Studio derives it from a step index with `(n*1000+15)/30`. Because accumulating 33.33 ms as a float or 33 ms as an integer drifts and differs across platforms. Any frame is directly addressable.
- **ADR-0004 Layered scenes and a compiled asset blob.** Scenes are layers with integer keyframes, drawn with `embedded-graphics`, and compiled from SVG into a deterministic blob (format v2 adds alpha4 and the mascot roles, and allows Q8 interpolation for the mascot). Because baked frames cost too much flash and fight tile rendering, and byte-reproducible assets keep host and device pixels equal.
- **ADR-0005 Typed activity log with an allowlist.** Closed types, fixed metadata, hashed device id, raw payloads compiled out, session-only history. Because payloads, identity, paths and tool output are sensitive. Support loses raw-byte detail in release builds on purpose.
- **ADR-0006 The handshake nonce is the session identity.** One OS-random `u32` per connection attempt stamps `InputEvent` and `Presentation`, and `revision` is session-scoped. Because a complete stale gesture pair buffered across a disconnect would otherwise pass the observed-`GestureStarted` check and change the volume. A dedicated `SessionEpoch` message was rejected because the nonce already has the right lifecycle. `gesture_id` only needs to be unique inside a session.

- **ADR-0007 Interrupt-captured input edges.** The GPIO interrupt records a timestamped level snapshot on every edge of CLK, DT and SW into a bounded queue; decoding stays above the port. Because the loop only returns to input between render passes, and composing plus flushing a frame takes longer than the quarter-steps of a detent, so polling once per tick loses detents and mistimes presses. Rejected: sampling between tile writes (still blind during composition) and a timer-sampled ISR (fixed cost whether or not anything moves).
- **ADR-0008 Desk state as two new messages.** Display mode plus monitored values travel as `Status` (tag 15, the whole snapshot on every change) and action outcomes as `Feedback` (tag 16, transient, newest wins), each behind its own capability. Because `Presentation` is a fixed wire struct (adding fields is a major change) whose job is the rotary overlay, and persistent truth and transient outcomes expire differently. Rejected: a per-field delta protocol (more states to get wrong for a payload under 64 bytes).

- **ADR-0009 macOS now-playing observation is layered: MediaRemote adapter, then AppleScript, then unknown.** macOS has no public system-wide now-playing API: `MPNowPlayingInfoCenter` only publishes, and the private MediaRemote framework has refused unentitled callers since 15.4. Kivori therefore (1) runs the BSD-3 [ungive/mediaremote-adapter](https://github.com/ungive/mediaremote-adapter), copied into `apps/desktop/src-tauri/vendor/` at a pinned commit and compiled from source by `build.rs` with plain clang (no prebuilt binaries, no extra build tool, no network; a missing toolchain is a warning, not a failed build). Apple's own entitled `/usr/bin/perl` loads the helper and streams JSON lines, read by a `kivori-media` thread that owns the long-running child. Each start first runs the adapter's `test` command, so an empty payload, once it has lasted 1 s, is an honest system-wide Stopped. (2) While the adapter is unavailable (test fails, process dies, unexpected output) Kivori retries it with backoff (2 s doubling to 60 s) and meanwhile polls Spotify and Music through public Apple Events (`osascript` with a 3 s timeout, never launching either app, one-time Automation prompt); because AppleScript cannot see browsers, finding nothing there is unknown, never Stopped. (3) Otherwise status and title are `None`. Rejected: the Rust wrapper crates (they ship prebuilt binaries, need a Swift toolchain, or are barely maintained) and AppleScript alone (no browsers). Accepted risk: a private framework reached through an Apple binary that Apple may remove or lock down; then Kivori degrades to layer 2 or unknown and never reports a guessed state. Titles and artists are never logged (ADR-0005). Release builds must bundle and sign the helper (roadmap M3).

## 8. Engineering principles

1. Observable truth first. An acknowledgement is not confirmation, unknown stays unknown, stale input is never replayed.
2. One visual model. Preview and device use the same scenes, assets, timing and renderer. The frontend never re-implements device pixels.
3. Deterministic rendering. Same inputs give byte-identical RGB565. No wall clock, unseeded randomness or platform floats. Intentional pixel changes update the goldens in the same change.
4. Hardware limits are design inputs (RAM, flash, SPI, USB, boot straps, recovery). Shared crates stay `no_std` and no-alloc. Hardware claims need hardware evidence, and simulation is labelled as simulation.
5. Desktop owns desktop meaning (OS integration, bindings, actions, config, updates). Firmware owns what must work without a healthy desktop (input conditioning, gestures, local rendering, device health, recovery).
6. Send meaning across boundaries (state, input, presentation), not drawing commands or streamed frames.
7. Offline-first core. Network features are isolated, explicit, and never block startup or device operation.
8. Least privilege. The webview gets typed native capabilities only. Ask for OS permission only when a feature needs it. Missing permission is a capability state, not a reason to elevate. Diagnostics use allowlists.
9. Test across boundaries without hardware where possible, and validate for real where a mock cannot prove the claim. A test must not claim evidence for a layer it did not exercise.
10. Build the smallest complete vertical path. Extract a crate or service only when isolation, reuse, security or runtime ownership needs it.
11. Record hard-to-reverse decisions as a new entry in [Decisions](#7-decisions): what, why, and what was rejected.
12. Evidence beats earlier recommendations. If measurements or tests show a better approach, change the code and fix the docs.

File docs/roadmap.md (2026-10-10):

# Kivori Roadmap

The order Kivori is built in. What it must be is in [product.md](./product.md); how it works is in
[architecture.md](./architecture.md); hardware checks are in [validation.md](./validation.md).

**Direction:** a desk buddy you control your computer with. Two equal pillars, **buddy** (the
reason to buy) and **control** (the daily value), with **monitoring** in support. Next work must
serve at least one pillar and never make the buddy smaller to fit more text.

**Sequence:** working foundation → useful device → configurable device → paid beta → customer
feedback → v1 investment. The aim is to learn whether people pay for Kivori before building every
long-term concern. Engineering rigor stays; only the order changes.

**Beta platform:** Windows is supported. macOS is later or experimental. Linux is later.

## Rules
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

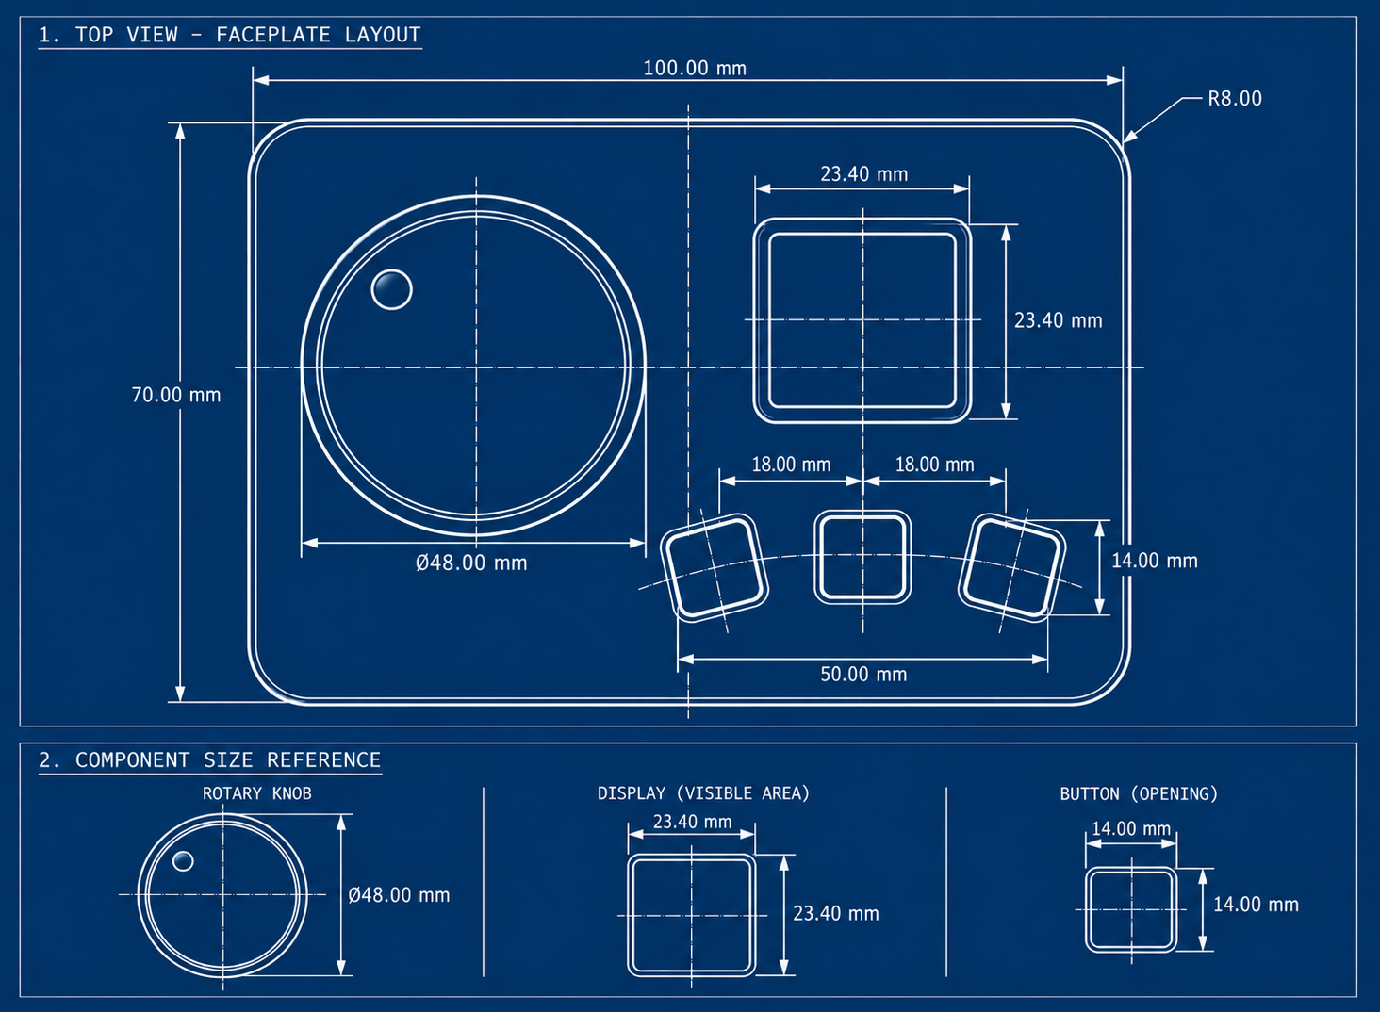
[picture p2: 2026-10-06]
docs/assets/soft-arc-faceplate-blueprint.png

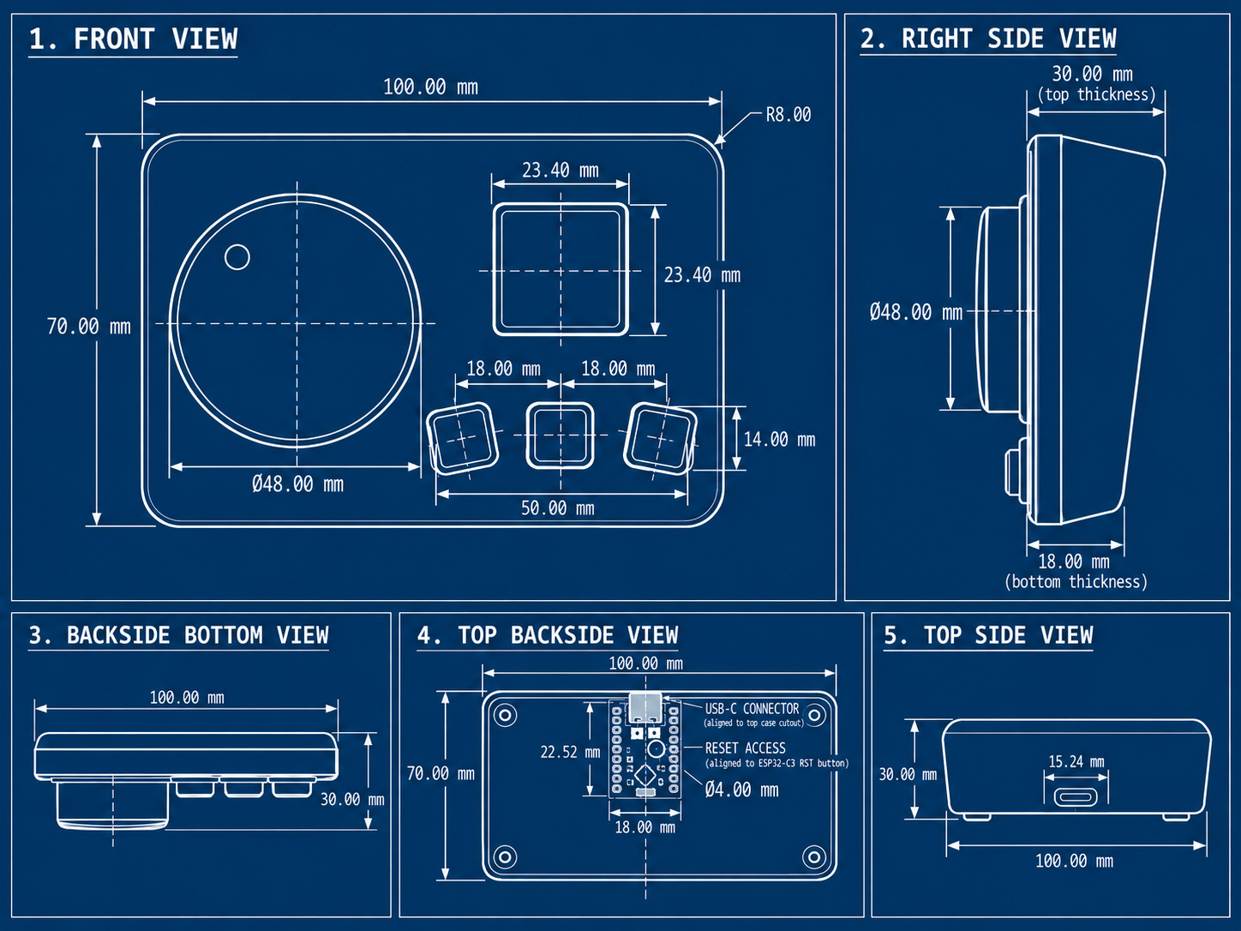
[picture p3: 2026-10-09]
docs/assets/image.png

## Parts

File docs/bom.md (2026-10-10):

# Kivori bill of materials (beta draft)

Drafted from the repo, not from purchase orders. Cells marked **OWNER** are blank on purpose:
prices and suppliers need the owner. Roadmap M3 item "BOM and real unit cost" stays open until they
are filled in. Related: [roadmap.md](./roadmap.md), [hardware/enclosure/README.md](../hardware/enclosure/README.md),
[validation.md](./validation.md).

## Electronics and bought parts

| Part | Exact type / spec as used | Qty | Notes | Unit price | Supplier |
|---|---|---:|---|---|---|
| ESP32-C3 board | ESP32-C3 SuperMini (the enclosure's target). Native USB Serial/JTAG (`0x303A:0x1001`), no header pins (wires soldered to the pads) | 1 | Must have **no 32.768 kHz crystal** on GPIO0/GPIO1 (validation 5.1); BOOT/RST reachable through the plinth pinholes. GPIO9 is not used by Kivori | **OWNER** | **OWNER** |
| Display | ST7789 1.3" 240x240 SPI module, 7-pin (SCL, SDA, RES, DC, BLK, VCC, GND), no CS | 1 | Verified on the board 2026-08-11 (offset 0,0, RGB order, inversion on). 3.3 V | **OWNER** | **OWNER** |
| Rotary encoder | HW-040 (EC11-type with push switch), CLK/DT/SW/+/GND, 3 pull-up resistors on the module | 1 | Beta part. Decision #8: HW-040 for beta, PEC11R/EC11 for v1. Power from 3V3, never 5 V. Pins CLK 4, DT 5, SW 10 are a spec until row 3.15 is ticked | **OWNER** | **OWNER** |
| Push buttons | Momentary tactile switch, 12×12 mm, 10 mm tall, projected plunger (seller drawing TS-G005), each between its GPIO and GND, no resistors | 3 | Left / middle / right on GPIO 0 / 1 / 20. The size the enclosure and its keycaps are built for | **OWNER** | **OWNER** |
| Wire | Thin wire, 26-30 AWG | 1 set | Hand-wired along the grooves on the back of the printed PCB | **OWNER** | **OWNER** |
| USB cable | USB-C **data** cable (not charge-only) | 1 | Power, flashing and the data link; no UART bridge | **OWNER** | **OWNER** |
| Rubber feet | 10 mm stick-on | 4 | In the recesses under the plinth | **OWNER** | **OWNER** |

## Printed parts

Source: `hardware/enclosure/export/*.stl`, already in print orientation. FDM, 0.4 mm nozzle, 0.2 mm
layers, 3 walls, 20 % infill, no supports. The enclosure README gives **no filament estimate**, so
the weight column is for the owner to fill from the slicer.

| Part (STL) | Material | Qty | Notes | Filament (g) | Unit cost |
|---|---|---:|---|---|---|
| `Shell` | Matte light PLA | 1 | Face down | **OWNER** | **OWNER** |
| `Visor` | Black PLA | 1 | Top down; glued or taped with three pegs | **OWNER** | **OWNER** |
| `BackPlate` (with plinth) | Black PETG | 1 | Hooks crack in PLA | **OWNER** | **OWNER** |
| `Carrier` (printed PCB) | Any PLA | 1 | Pegs and standoffs up | **OWNER** | **OWNER** |
| `Knob` | Black PLA | 1 | Pushes onto the D-shaft | **OWNER** | **OWNER** |
| `CapLeft`, `CapMiddle`, `CapRight` | Accent-colour PLA | 3 | One of each | **OWNER** | **OWNER** |

`export/pcb-outline.dxf` is not a printed part: it becomes the KiCad board outline later.

## Fasteners and consumables

The enclosure README lists **no screws or inserts**: the case is snap-fit (four hooks on the back
plate). Optional: a drop of CA glue or thin double-sided tape for the visor, and a soldering iron for
heat-staking the peg tips and soldering wires.

## Open questions

- **Totals.** No unit cost can be computed until the **OWNER** cells are filled in.
- Regulatory cost (FCC / CE, #36) and packaging are not in this list.

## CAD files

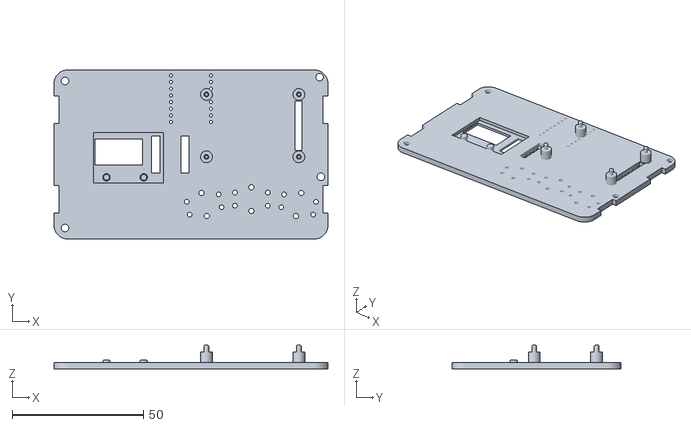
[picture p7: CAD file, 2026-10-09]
hardware/enclosure/export/Carrier.stl
104.4 x 64.4 x 9.10

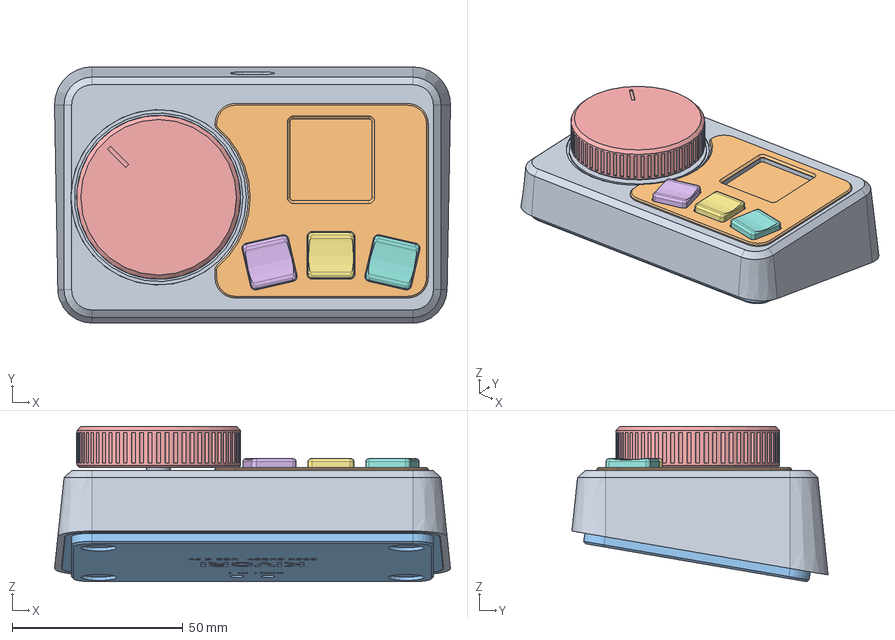
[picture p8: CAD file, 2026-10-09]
hardware/enclosure/kivori-case.FCStd
116.0 x 75.1 x 45.5 mm
Visor
BackPlate
Carrier
Knob
CapLeft
CapMiddle
CapRight
Dummy_Encoder
Dummy_Display
Dummy_SuperMini
Dummy_SwitchLeft
Dummy_SwitchMiddle
Dummy_SwitchRight

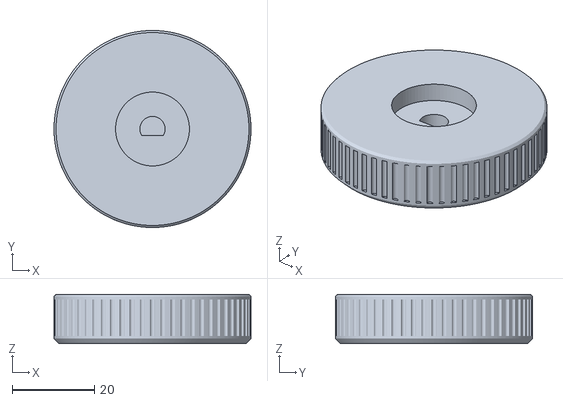
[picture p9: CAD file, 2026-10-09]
hardware/enclosure/export/Knob.stl
48.0 x 48.0 x 12.0

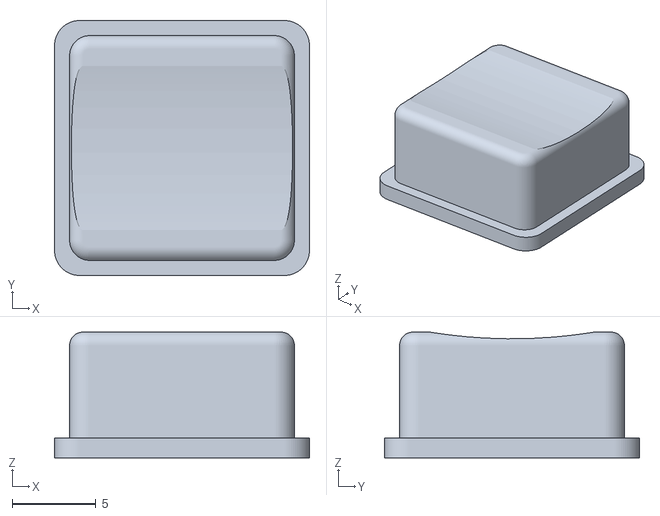
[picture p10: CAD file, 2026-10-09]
hardware/enclosure/export/CapMiddle.stl
15.2 x 15.2 x 7.50

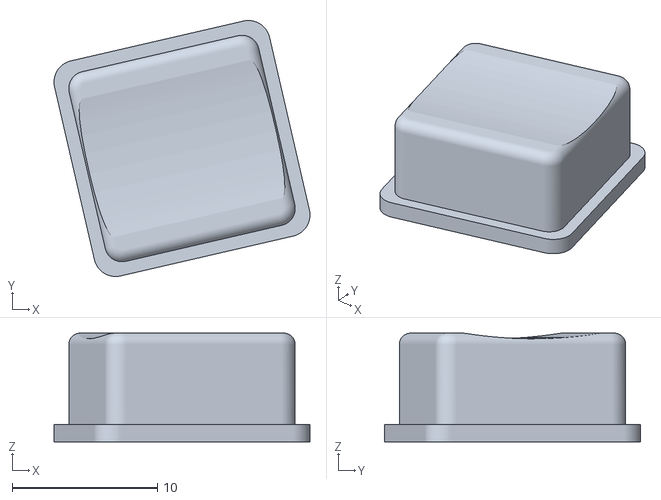
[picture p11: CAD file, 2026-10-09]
hardware/enclosure/export/CapLeft.stl
17.6 x 17.6 x 7.50

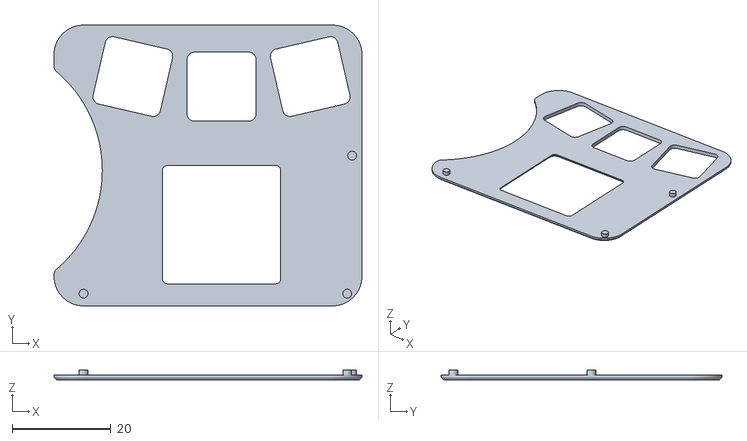
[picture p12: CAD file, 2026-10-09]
hardware/enclosure/export/Visor.stl
62.5 x 57.0 x 2.00

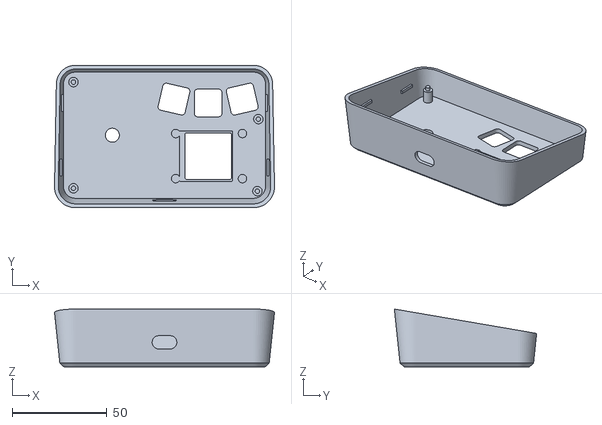
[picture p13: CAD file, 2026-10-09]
hardware/enclosure/export/Shell.stl
116.0 x 75.1 x 30.6

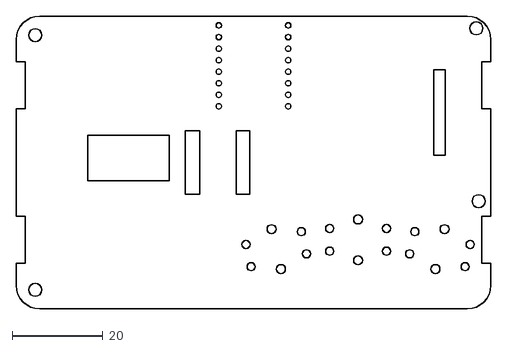
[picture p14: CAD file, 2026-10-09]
hardware/enclosure/export/pcb-outline.dxf
104.4 x 64.4

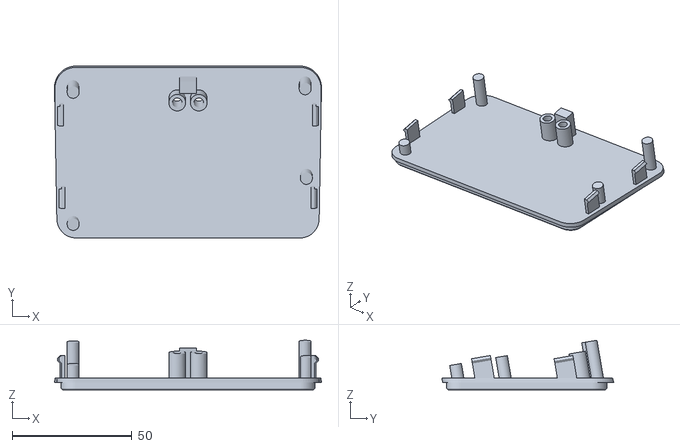
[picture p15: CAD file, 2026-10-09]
hardware/enclosure/export/BackPlate.stl
111.6 x 71.8 x 20.7

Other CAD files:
hardware/enclosure/export/CapRight.stl

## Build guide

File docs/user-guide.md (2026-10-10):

# Kivori user guide

A short guide for beta customers. Kivori is a desk buddy with a knob, three buttons and a small
screen. It controls your computer and shows what is going on. It is written for Windows; the few
macOS differences are called out.

## What's in the box

- Kivori unit (knob, three buttons, screen) _(to be confirmed)_
- USB-C data cable _(to be confirmed)_
- Installer download link or USB stick _(to be confirmed)_
- Quick-start card _(to be confirmed)_

## Install

1. Run the Kivori installer. It installs for your user only and does not ask for administrator
   rights.
2. This beta installer is not signed yet, so Windows SmartScreen may show "Windows protected your
   PC". This is expected for an unsigned app. If you got the installer from us, choose **More
   info**, then **Run anyway**.
3. Finish the installer and open Kivori.

A signed installer is coming, and the SmartScreen step will go away with it.

**macOS:** open the `.dmg` and drag Kivori to Applications.

## First run and setup

Kivori walks you through a short setup. You can skip any step, and "Skip setup" is always at the top.

1. **Welcome.**
2. **Plug in.** Connect Kivori with a USB-C **data** cable. Kivori finds it by itself; there is no
   port to choose.
3. **Permissions (macOS only).** Choose Allow access, then switch Kivori on under Privacy &
   Security, Accessibility. Without it, shortcuts and media keys will not work.
4. **Try it.** Turn the knob, press the knob and press a side button. Each step ticks when Kivori
   sees it.
5. **Make it yours.** Pick the starting screen, how lively the buddy is, and whether Kivori starts
   with Windows.

You can repeat setup any time: Device page, **Run setup again**.

## The controls

| Control | What it does by default |
|---|---|
| Turn the knob | Volume (faster turns take bigger steps) |
| Press the knob | Play / Pause |
| Hold the knob (about 1 second, then let go) | Mute |
| Double-press the knob | Switch screen view |
| Left / middle / right button | Previous track / Play-Pause / Next track |
| Hold the middle button | Pin a profile (see below) |
| Hold the knob for about 10 seconds | Restarts Kivori, even if the app is closed |

A short press means pressed and released within half a second. Holding the knob past about 2
seconds does nothing until the 10-second restart, and the screen shows its progress. The left and
right buttons can also be given a Hold action in the app; holding them for a long time never
restarts anything.

## Profiles

Kivori changes what the controls do to suit the app in front of you, for example media keys in a
player or tab switching in a browser. This is **Auto**, and the profile name shows at the top left of
the screen. The built-in profiles are General, Browser, Code, Media, Zoom and Teams.

To stay on one profile, hold the middle button. Each hold moves on: General, Browser, Code, Media,
Zoom, Teams, then back to Auto. A dot next to the name shows it is pinned. On a protected window
(such as a Windows permission prompt or the lock screen) shortcuts and app launches pause, while
volume, media keys and mute keep working.

## Customising controls and macros

Open the **Controls** page. Pick a profile, then **Edit** any control to choose a different action:
system or per-app volume, media, mute, a keyboard shortcut, launching an app, or a macro. **Test**
runs it right now. **Reset** puts the built-in action back. Changes are saved on this computer for
your Windows user.

A **macro** runs up to 8 steps in order, with optional waits. It stops at the first step that fails
and does not undo earlier steps. Create macros on the Controls page, then bind one to a control.

## Display views and the buddy

The screen is home to your buddy, with the profile, clock and control labels around it. Under
**Display** you choose the starting view and what a double press switches to. The views are Buddy,
Clock, Volume, Media and System (CPU and memory).

The buddy shows what your computer is really doing: it looks strained under heavy load, muted when
you are muted, and happy after a confirmed action. Under Display you can switch its reactions on or
off and set its intensity (Low, Normal, High).

## What the badges mean

After an action, the screen briefly shows a badge:

| Badge | Meaning |
|---|---|
| Green check | **Confirmed.** Kivori read the new state back from your computer. |
| Blue arrow | **Started.** The computer accepted it and started it (for example launching an app). |
| Amber "?" | **Unverified.** Sent, but the computer cannot confirm what happened. Keyboard shortcuts and media keys are always this. |
| Red cross | **Error.** It did not work, and nothing was changed. |

## Sleep and lock

- When your computer goes to sleep, the buddy shows **Sleeping**, then Kivori lets go of the USB
  port. On wake it reconnects by itself. Nothing you turned or pressed before sleep runs afterwards.
- Locking the screen puts the buddy to sleep. Unlocking brings back what you had.
- If the Kivori app stops or crashes, the screen shows **Offline** within about 4 seconds.
- Kivori can start with Windows and sits in the tray. The window is optional: close it and Kivori
  keeps working. Use the tray icon to open it or quit.

## Updating firmware

On the **Device** page, Kivori shows the firmware on your device and the firmware inside the app, and
says when an update is available. An update is never installed without you asking.

1. Choose **Flash firmware**, then **Flash now**.
2. Keep USB plugged in. The screen shows **Updating**. This takes a short while.
3. Kivori reconnects when it is done. A failed update says so.

## Recovery with the BOOT button

If an update failed or the device will not connect, use **Restore with the BOOT button** on the
Device page (or in setup). Connect only one Kivori, then follow the three steps in the app:

1. Unplug your Kivori from the computer.
2. Hold down the BOOT button, and keep holding it while you plug the USB cable back in.
3. Let go of the BOOT button, then choose **Restore now**.

BOOT is the pinhole in the base labelled BOOT; a paperclip reaches it.

## Troubleshooting

- **Not connecting.** Wait a few seconds, then try another USB port, plugged straight into the
  computer rather than through a hub.
- **Charge-only cable.** Some USB-C cables only carry power. Use a data cable.
- **Another program has the port.** Close serial monitors and other apps that use USB serial devices.
- **Shortcuts or media keys do nothing (macOS).** Allow Kivori under System Settings, Privacy &
  Security, Accessibility.
- **Still stuck.** Try the BOOT button recovery above.
- **Asking for help.** On the Device page choose **Copy diagnostics** and paste it into your message.
  It holds versions and status only: no port names, file paths or device IDs.

## Uninstall

Windows: Settings, Apps, Kivori, Uninstall. This also removes the start-with-Windows entry. Your
settings stay in your user data folder (`%LOCALAPPDATA%\id.immer.kivori`); delete it if you want
them gone. macOS: drag Kivori from Applications to the Bin.

## Privacy

Kivori works fully offline. It has no telemetry, no account and no cloud, and nothing in the app
needs the internet. Your settings and the session activity list stay on your computer.

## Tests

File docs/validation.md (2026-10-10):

# Hardware validation

The one checklist for everything CI cannot prove: real ESP32-C3 + ST7789 + HW-040 hardware, real
OS behavior, real timing. Simulation and host tests are never promoted to physical evidence.

Row numbers: `1.N` is row N of the old Phase 1 (device connection) checklist, `3.N` is row N of the old
rotary checklist, `2.N` are new Phase 2 rows, `G` rows are PRD gates. Tick a row only with a date and a
measurement or observation on the same line. A phase closes only when all its rows are ticked.

## How to run a session

**You need:** the board, a Windows PC and a Mac, one unrelated USB-serial device (Arduino or UART
adapter), and a phone that films slow motion (backup for latency only).

Pins (source of truth: `firmware/esp32-c3/src/profile.rs`). Display pins are measured; encoder pins are a
specification until row 3.15 is ticked.

| Signal | GPIO | Signal | GPIO |
|---|---:|---|---:|
| SPI SCK (SPI2, 20 MHz, Mode 3) | 6 | Encoder CLK | 4 |
| SPI MOSI | 7 | Encoder DT | 5 |
| Display D/C | 2 | Encoder SW | 10 |
| Display RST | 3 | USB D- / D+ | 18 / 19 |
| Backlight (active-high) | 8 | Encoder COM / VCC | GND / **3V3** (never 5 V) |
| Button left / middle / right | 0 / 1 / 20 | Button other leg | GND (no resistor) |

1. Once per machine: `bun install`, `cargo install espflash`, install `just`.
2. Flash the product firmware: `just fw-flash` (builds with `physical-st7789`, then flashes and monitors).
3. Start the app: `just desktop` (one command: builds the firmware, starts the UI dev server, runs the
   app with the firmware embedded so Flash firmware works, and stops the UI server when the app quits).
   Plain `cargo run -p kivori-desktop` bundles no firmware and logs `firmwareUnavailable`.
   Discovery is automatic; there is no port picker. Expect **Connected**, firmware 1.3.0, protocol 1.5.
   On macOS, shortcuts and media keys need Accessibility permission for the app that runs Kivori
   (during development, the terminal running `cargo run`): System Settings > Privacy & Security >
   Accessibility.
4. Latency only: `just fw-flash-latency` (dev-only probe build), then `just fw-flash` to restore the product build.

Suggested order: wiring (3.15) and flash, then Phase 1 (Windows, then macOS), Phase 2, Phase 3, latency,
then Phase 4 (M1), then Phases 5 to 12 in order (5b is the Config UI half of the M2 rows; 7 to 12 are the M3 rows). Rows marked macOS run on the Mac; everything else on Windows.

## Phase 1: Device connection

Windows unless a row says otherwise. Rows 1, 3, 4 passed on macOS but stay open until Windows runs.

**Background operation**

- [ ] 1.1 Close the window, then check the process | window hides, process keeps running. macOS 2026-09-25 done (debug build, no device; hidden not moved Space, checked with CGWindowList). Windows pending
- [ ] 1.2 While hidden for 2 minutes, watch the Log view | device heartbeat and synchronization stay active
- [ ] 1.3 Reactivate (taskbar or Dock, and a second launch) | one window reappears, one process. macOS 2026-09-25 done (Dock click needed a fix for `RunEvent::Reopen`, re-verified). Windows pending
- [ ] 1.4 Tray, then Quit | process exits and the device task stops. macOS 2026-09-25 done (exit code 0 in about 1 s). Windows pending

**Discovery and connection**

- [x] 1.5 Plug in the board | enumerates as `0x303A:0x1001`, auto-discovered with no port selection, handshake confirms identity. 2026-08-11: COM3, Connected, firmware 1.0.0, protocol 1.0
- [ ] 1.6 Plug in from cold and time it in the Log view timestamps | connected in under 5 s. Connection seen working, latency never measured
- [ ] 1.7 Plug in the unrelated USB-serial device | not reported as connected
- [ ] 1.8 Flash a wrong-major firmware | shows incompatible with a clear reason within 5 s, no state commands sent

**Companion states**

- [x] 1.9 Display init and panel offsets | 2026-08-11: ST7789 240x240 initialized, offset (0,0)
- [ ] 1.10 Show each of idle, happy, busy, sleeping from Device Studio | matching animated scene each time. Only idle confirmed so far
- [ ] 1.11 Change state and time it | appears on the device in under 1 s. Idle propagation seen, latency never measured
- [ ] 1.12 Freeze a fixed state and time in Device Studio, compare side by side with the panel | images match
- [ ] 1.13 Read the SPI frame rate from Health or Log output | a sustainable rate is recorded
- [ ] 1.14 Read the typed session activity view | only semantic state is sent, no raw payload bytes shown

**Recovery and restoration**

- [ ] 1.15 Unplug while busy | app shows Disconnected
- [ ] 1.16 Replug, do nothing | auto-reconnects and returns to busy within 10 s
- [ ] 1.17 Unplug and replug quickly 10 times | settles into one stable Connected
- [ ] 1.18 Run 30 min of sustained state changes | no USB stall, stall recovery works
- [ ] 1.19 Set happy, fully quit and restart the app | device returns to idle. Code review 2026-09-25 says it should (no persistence); needs a device to observe

**Platform and safety**

- [ ] 1.20 Collect the three timings | state change < 1 s, connect < 5 s, reconnect plus restore < 10 s
- [ ] 1.21 Confirm `usb_serial_jtag` behavior on the pinned esp-hal version | no drops or hangs under 1.18 traffic
- [ ] 1.22 Read the activity view while connected | no raw bytes, device id, paths or usernames; no log file is created. Partial macOS 2026-09-25: no log file created, only WebKit storage and stdout; connected part needs the device
- [x] 1.23 Identify the panel controller | 2026-08-11: ST7789
- [x] 1.24 Record the real SPI pin map | 2026-08-11: SCK 6, MOSI 7, no CS, D/C 2, RST 3, backlight 8 active-high; SPI2 20 MHz Mode 3
- [x] 1.25 Measure panel offsets | 2026-08-11: (0,0). Also verified: 90 degree rotation, RGB order, inversion on

## Phase 2: Mascot, reactions, flashing

Software is done (goldens, render parity, 204 workspace tests); these rows need eyes on the panel.
Desktop automation was unavailable, so no native click-through has been verified either.

- [ ] 2.1 Show each of the six states on the panel: booting, idle, happy, busy, sleeping, offline | each is recognisable and matches the Device Studio preview
- [ ] 2.2 Set happy | the keycap cap sinks in a deep press, face is the happy face
- [ ] 2.3 Play every reaction in Idle: Greet, Pet, Tickle, Surprise, Comfort | each plays, returns to idle, and no reaction looks like Happy or Booting (check the recombined Greet and Surprise faces in particular)
- [ ] 2.4 Play a reaction in Busy | nothing plays and Desktop does not claim it did
- [ ] 2.5 Play a reaction in Sleeping | gentle sleepy response, then back to Sleeping
- [ ] 2.6 Change state during a reaction | reaction stops and the normal eased transition runs
- [ ] 2.7 Turn the knob so the volume overlay shows, in each state | the keycap shrinks and lifts to clear the volume bar (y 180 to 196), no overlap or flicker
- [ ] 2.8 Watch idle for 2 minutes | blinks and expression swaps look smooth, no crawling edges, no full-screen flashes
- [ ] 2.9 Click Flash firmware in Device Studio | flashing completes and the app reconnects to the same port

## Phase 3: Rotary volume (Windows)

**Rotary input fidelity**

- [ ] 3.1 Turn one detent each way | exactly one volume step per detent
- [ ] 3.2 Turn slowly | no detent lost
- [ ] 3.3 Spin fast | no false reversals
- [ ] 3.4 Wiggle at a detent edge | no phantom detents, invalid-transition counter stays low

**Windows Core Audio**

- [ ] 3.5 Compare the Windows volume flyout with the device | values match
- [ ] 3.6 Change volume in the flyout | device updates with no Kivori input
- [ ] 3.7 Change the flyout during a turn | no fight with the preview; it applies at gesture end
- [ ] 3.8 Look at the panel during and after a turn | Preview and Confirmed look clearly different
- [ ] 3.9 Switch the default output device between turns | rebinds and shows the new device's volume
- [ ] 3.10 Switch the default output device mid-turn | the gesture is discarded, not retargeted

**Bounds and recovery**

- [ ] 3.11 Turn to 0 and to 100, then reverse | clamps at both ends, first reverse detent leaves the limit immediately
- [ ] 3.12 Unplug mid-turn, replug | the old gesture executes nothing
- [ ] 3.13 Restart Kivori Desktop with the device powered | presentation resumes, no stale overlay

**Latency and wiring**

- [ ] 3.14 Flash `just fw-flash-latency`, turn single detents about 30 times, read `L` (last) and `H` (max) off the panel corner | max under 50 ms detent to flush complete; record several readings plus `H`. This is a gate: the phase is not done while this fails or is unmeasured. Scan-out adds up to one refresh on top. Worst case predicted at about 85 ms (50 ms desktop tick, serial, 33 ms frame), so expect to tune; remedies in order: blocking serial read instead of the 50 ms tick, then a shorter frame interval, then device-local feedback. Re-measure after any change, then `just fw-flash`
- [ ] 3.15 Check wiring with a continuity test | CLK=GPIO4, DT=GPIO5, SW=GPIO10, COM to GND, VCC to 3V3. Do this first: rows 3.1 to 3.4 depend on it

**PRD gates**

- [ ] G1 No false confirmation | the panel never shows Confirmed for a volume Windows did not actually report, across 3.5 to 3.13
- [ ] G2 No stale replay | after unplug, restart or device switch, no old gesture or overlay is ever replayed (3.10, 3.12, 3.13)

## Phase 4: Push switch, actions, monitoring (M1)

Software is done and host-tested (button machine, recovery, desk pipeline, e2e host-sim round trip);
these rows need the real switch, the real OS and eyes on the panel. Default bindings: Press = Play/Pause,
Hold = master mute. Shortcut and launch run from Device Studio's Test action panel until M2.

**Switch and recovery**

- [ ] 4.1 Short press (well under 0.5 s), ten times | exactly one Play/Pause per press; the keycap dips (or a white frame shows) the moment you press; holding never auto-repeats
- [ ] 4.2 Hold about 1 s and release, five times | exactly one mute toggle each time; never also a Play/Pause
- [ ] 4.3 Hold 3 s, release | the recovery screen with a filling bar appears at about 2 s; release cancels it; nothing runs
- [ ] 4.4 Hold 10 s with Kivori Desktop running | "Restarting", the device reboots, the app shows the disconnect and reconnects by itself (gate 8)
- [ ] 4.5 Hold 10 s with Kivori Desktop quit | the device still reboots (gate 8, invariant 24)
- [ ] 4.6 Turn the knob while holding the switch | volume does not change and recovery is not cancelled (invariant 33)
- [ ] 4.7 Press while the knob is still turning | no Play/Pause fires
- [ ] 4.8 Unplug, press and hold during the outage, replug | nothing runs after reconnect (gate 2)

- [ ] 4.24 Double press, ten times at a natural speed | the device moves to the next view each time (Buddy, Clock, Volume, Media, System, Buddy); no Play/Pause fires
- [ ] 4.25 Single press after the double-press change | Play/Pause still fires once, about a quarter second after release; note whether the delay feels acceptable

- [ ] 4.26 Double press through every view and watch the slide | smooth vertical slide, no tearing or leftover pixels; the status-row time sliding past content is acceptable
- [ ] 4.27 Media view with a long title (macOS adapter or Windows) | title and artist correct, long text scrolls smoothly; accented Latin-1 letters render; other scripts show `?`
- [ ] 4.28 Frame cost of the redesigned views | `just fw-flash-latency`, show the Volume view and turn the knob: latency max still under 50 ms (row 3.14); note any visible stutter in Clock / System

**Actions and confirmation**

- [ ] 4.9 Hold to mute, then again to unmute; compare the OS mixer | OS mute matches each time; badge is the green check (State Confirmed). Windows and macOS
- [ ] 4.10 Mute or unmute from the OS (keyboard key, flyout, menu bar) | the panel's mute indicator follows with no Kivori input. Windows and macOS
- [ ] 4.11 Press while Spotify or a browser plays (Windows) | playback toggles; badge is the amber "?" (Unverified, never a check); the media indicator and Media view follow the real state within about 1 s
- [ ] 4.12 Press while something plays (macOS) | playback toggles; badge is the amber "?" (Unverified), never a check; Kivori does not crash (input runs on the main thread)
- [ ] 4.13 Test action: shortcut (Windows `Ctrl+Shift+Esc`, macOS `Cmd+Space`) | the shortcut happens; badge is the amber "?" (Unverified). Windows and macOS
- [ ] 4.14 Test action: launch (`notepad` / `Calculator`), then a name that does not exist | the app starts with the blue arrow (Execution Confirmed); the missing one shows the red cross. Windows and macOS
- [ ] 4.15 macOS with Accessibility permission removed: Press | red cross, the app says Accessibility permission is needed, nothing is sent another way (gate 5); after granting, Press works without restarting Kivori
- [ ] 4.16 Force a volume failure (Windows: disable the output device) and turn the knob | red cross on the panel, never a fake volume (gates 6 and 9)

**Monitoring and display**

- [ ] 4.17 Pick each mode in Overview | the panel shows Buddy, Clock, Volume, Media, System; each is recognisable. Windows and macOS
- [ ] 4.18 Clock view | matches the computer clock; still within a minute after 10 minutes
- [ ] 4.19 System view | CPU and RAM within about 10 points of Task Manager / Activity Monitor; a 10 s CPU stress turns the CPU bar amber and shows the heat cue over the buddy, which clears once load drops
- [ ] 4.20 Media view | Windows follows Playing / Paused / Stopped within about 1 s; macOS shows "No media info"
- [ ] 4.21 Volume view | follows the OS volume and mute; turning the knob shows the hollow preview, then the solid confirmed value
- [ ] 4.22 Quit Kivori Desktop | the device shows the offline buddy within the heartbeat timeout; no stale mode or values remain (gate 9)
- [ ] 4.23 Daily use for a few days (subjective, record notes) | press and hold timing feel natural; accidental holds or missed presses are noted for tuning

**PRD gates**

- [ ] G5 No hidden fallback | an action that cannot run says so and never switches mechanism (4.15)
- [ ] G6 No state invention | unknown values show as `--` on the panel and `—` in the app (4.17 to 4.20)
- [ ] G8 Recoverability | recovery works without healthy desktop software (4.4, 4.5)

## Phase 5: Contextual buttons (M2)

Software is done and host-tested (firmware gesture rules, wire, desktop bindings, e2e round trip).
Wiring: three momentary tactile switches (12×12 mm, 10 mm tall, seller drawing TS-G005: the size the enclosure in `hardware/enclosure/` is built for; any momentary switch works electrically), each between its GPIO and GND, no resistors or
capacitors; firmware enables the internal pull-ups and debounces 20 ms. Default bindings, left to
right: Previous track, Play/Pause, Next track (Press only; Hold unbound by default).

- [ ] 5.1 Before wiring: inspect the devkit near GPIO0/GPIO1 | no 32.768 kHz crystal fitted (if one is, stop: pick other pins before soldering)
- [ ] 5.2 Power on with each button held in turn | Kivori boots normally every time (none is a strapping pin); the boot log still appears on GPIO21
- [ ] 5.3 Each button, ten short presses while music plays | exactly one Previous / Play-Pause / Next per press; amber "?" badge (Unverified); a white frame on press
- [ ] 5.4 Each button held about 1 s | nothing runs (Hold is unbound); held 12 s | nothing runs and the device never reboots
- [ ] 5.5 Two buttons pressed together; a button pressed while the knob switch is down; a button pressed mid-turn | nothing fires from the second control (no chords)
- [ ] 5.6 Hold the knob switch 10 s while a button is held | the device still reboots (invariant 24)
- [ ] 5.7 Buddy view | button labels sit under the keycap, ticks line up with the physical buttons, `TURN Volume` top left; the keycap is full size
- [ ] 5.8 Unplug, press buttons during the outage, replug | nothing runs after reconnect (gate 2)

## Phase 5b: Config UI (M2)

Software is done and host-tested (config store, resolve, IPC, Controls page with the browser mock).
These rows need a person, the real device and the real OS.

- [ ] 5.9 Controls page: Edit Press, pick a keyboard shortcut, save | the "Custom" badge appears on the row and the device label updates within a moment; Reset puts the built-in back
- [ ] 5.10 Rebind a control, use it on the device, quit and restart Kivori Desktop | the binding is still there (Custom badge, device label) and still works
- [ ] 5.11 Install a newer build over the old one (settings kept) | the custom bindings are still there; no "settings were damaged" banner
- [ ] 5.12 Windows: bind the knob to App Volume `spotify.exe` while Spotify plays, turn the knob | Spotify's slider in the Windows volume mixer moves, the master volume does not; one badge at the end of the turn
- [ ] 5.13 Windows: bind a button to App Mute `spotify.exe`, press it twice | Spotify mutes and unmutes in the mixer, master mute is untouched; badge is the green check
- [ ] 5.14 Controls page Test on a keyboard shortcut | a 3-second countdown appears (Cancel stops it); after it, the shortcut lands in the app you clicked; badge is the amber "?"
- [ ] 5.15 Hold on a contextual button bound in the UI | the action runs; the device does not show a label for it yet (known gap)
- [ ] 5.16 Reset profile and Reset everything | each asks first; afterwards the Custom badges are gone and the device shows the built-in labels
- [ ] 5.17 macOS: open Edit on the knob | App volume is greyed out with a reason; nothing falls back to system volume
- [ ] 5.18 Controls page: create a macro (Mute, Wait 500 ms, Play / Pause), bind it to a button and press it; try to delete it while bound | the steps run in order; the badge is the amber "?" (the least certain step); Delete is refused with a message until the button is unbound; focusing another app mid-macro stops it before any shortcut or launch step

## Phase 6: Profiles and layout (M2.5)

- [ ] 6.1 Windows: focus Chrome, VS Code, Spotify, Zoom or Teams in turn | about half a second later the profile name and all labels change together; the knob does tabs in Chrome
- [ ] 6.2 Turn the knob in Chrome and Alt+Tab mid-turn | tab switching stops at once, one red cross, nothing lands in the new app
- [ ] 6.3 Trigger a UAC prompt, lock with Win+L, open an elevated app (regedit) | "Protected": button shortcut labels gone, pressing one shows the red cross, the volume knob still works
- [ ] 6.4 Hold the middle button repeatedly | General, Browser, Code, Media, Zoom, Teams, then back to following focus; a dot shows while pinned; a UAC prompt still wins over a pin
- [ ] 6.5 macOS: the same app switches (Safari, VS Code, Music) and the lock screen | same behaviour (daily test bed)
- [ ] 6.7 Buddy faces: mute the OS, play music, run a CPU stress, join a Zoom call, trigger a failing and a confirmed action | muted, listening, strained, attentive, error and celebrate faces each appear only for their real cause; a shortcut (Unverified) never celebrates; unplugging shows the offline face, distinct from sleeping; note whether the instant face swap looks like a pop
- [ ] 6.6 Layout at desk distance | profile, clock, knob label and button labels readable; button labels sit over their physical buttons; the buddy is full size

## Phase 7: Host presence (M3 S2)

Software is done (tracker, device-thread and Windows window tests, macOS IOKit registration test); these rows need a real sleep, lock and switch.

- [ ] 7.1 Windows: press Win+L | the buddy sleeps within 1 s; the volume knob still works; button shortcut labels are gone
- [ ] 7.2 Windows: unlock | back to normal, profile labels restored, the state you had chosen returns
- [ ] 7.3 Windows: Start, then Sleep (S3) | the device shows Sleeping, not Offline, before the PC goes dark
- [ ] 7.4 Windows: wake | reconnected and normal within 5 s; no knob turn or press made during sleep runs
- [ ] 7.5 Windows: Hibernate, then resume | same as 7.4
- [ ] 7.6 Windows: Modern Standby laptop, close the lid for 2 min, open it | Sleeping, then reconnect. Note whether the goodbye arrived in time (if not, the device shows Offline after about 4 s)
- [ ] 7.7 Windows: a machine that cuts USB power in sleep | the device boots and reconnects on wake
- [ ] 7.8 Windows: switch user | user A's Kivori releases the port; user B's Kivori connects
- [ ] 7.9 macOS: `cargo test -p kivori-desktop` on the Mac | passes, including the IOKit registration test
- [ ] 7.10 macOS: lock with Ctrl-Cmd-Q, then unlock | the buddy sleeps within about 1 s; unlock restores it
- [ ] 7.11 macOS: Apple menu, Sleep, then wake | Sleeping before the screen goes dark, then reconnect
- [ ] 7.12 macOS: close the lid on battery, then open | same as 7.11

## Phase 8: Firmware update and recovery (M3 S3)

Software is done (workflow, classifier fixtures, recovery rules, sidecar lookup, DTO allowlist, UI tests). The classifier fixtures are conservative guesses at `espflash` 4.x wording; row 8.7 refreshes them. Rows 8.1 to 8.6 need a real device and the installed app (the S5 installer bundles the `espflash` 4.6.0 sidecar) or a dev build with `espflash` on `PATH`.

- [ ] 8.1 Flash from the installed app on a machine with no Rust toolchain | it succeeds and the device reconnects (needs the S5 installer)
- [ ] 8.2 Unplug the board mid-flash | the app says it failed and offers Restore with the BOOT button
- [ ] 8.3 Erase the flash, then Restore with the BOOT steps | the unit recovers and shows its hash
- [ ] 8.4 Hold the port open in a serial monitor, then flash | the "close other apps" message appears
- [ ] 8.5 Flash a wrong-major firmware, then use Restore | Restore is offered on the Device page and works
- [ ] 8.6 Flash from the app | the panel shows Updating (or goes dark cleanly) during the flash, never garbage, then returns to the buddy
- [ ] 8.7 Capture `espflash` stderr for each failure above | add each as a classifier fixture in `tests/firmware_flash.rs`
- [ ] 8.8 With an older app-bundled version than the device, and with a newer one | the Device page and Home show "update available" only when the bundled firmware is newer

## Phase 9: Launch at login and tray (M3 S4)

Software is done (tray model table, hidden-start lifecycle, `--autostart` parsing, Device page switch). Every row needs a real sign-in, so none are checked yet. The Windows uninstall row needs a real uninstall of the S5 installer (its hook removes the Run entry).

- [ ] 9.1 Windows: turn on Start with Windows, sign out and back in | the tray icon is present, no window opens, the device connects
- [ ] 9.2 Windows: turn it off, sign in again | Kivori does not start
- [ ] 9.3 Windows: uninstall | the `HKCU\...\Run\Kivori` entry is gone (needs the S5 installer)
- [ ] 9.4 macOS: same as 9.1 and 9.2 through the LaunchAgent | and the "Background item" notice appears once
- [ ] 9.5 Tray menu: Launch at login, Open Kivori and Quit | each works; the check mark matches the Device page switch after reopening the window
- [ ] 9.6 Connect, unplug, lock the screen | the tray line reads Connected, Not connected, Paused while locked; the tooltip shows both versions
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

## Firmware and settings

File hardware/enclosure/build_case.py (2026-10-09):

"""Kivori enclosure: parametric build script (FreeCAD 1.1, Part workbench, no GUI needed).

Run it inside FreeCAD (GUI Python console, the FreeCAD MCP, or freecadcmd):

    p = "<repo>/hardware/enclosure/build_case.py"
    exec(open(p).read(), {"__file__": p, "__name__": "__main__"})

Every dimension lives in the parameter block below. Change a number, run again, the document is
rebuilt from scratch, re-checked for interference and re-exported.

Frame used everywhere (the "face frame"):
  * the outer face surface is z = 0, the case body is at z < 0 (z = depth behind the face),
  * x runs 0..W from left to right as you look at the face,
  * y runs 0..H from the near edge (user side, thin end of the wedge) to the far edge (USB side).

Values marked NOMINAL come from datasheets, KiCad footprints or seller listings, not from a
measured part. Fix them here after the fit-test print.
"""

import math
import os

import FreeCAD as App
import Part

V = App.Vector

# ---------------------------------------------------------------------------------------------
# Parameters
# ---------------------------------------------------------------------------------------------

# Case (blueprint, widened from 100 to 110 mm so the Ø48 knob clears the button arc).
# Design "big keycap": the walls lean in towards the face like a keycap, a 45° bevel frames the
# face, a dark visor carries the display and buttons, and the shell floats on a dark plinth.
W, H = 110.0, 70.0          # face outline (outer edge of the bevel)
R_CORNER = 8.0              # face corner radius
T_NEAR, T_FAR = 18.0, 30.0  # case thickness at the near (y=0) and far (y=H) edge -> ~9.7° wedge
WALL = 2.0                  # side wall thickness (horizontal)
WALL_TAPER = 6.0            # degrees the walls lean in towards the face (keycap draft)
FACE_T = 2.5                # faceplate thickness (room for the visor pocket in front)
FACE_BEVEL = 2.0            # 45° bevel round the face; prints cleanly face-down
BP_T = 2.0                  # back plate thickness
BP_CLR = 0.2                # back plate to wall clearance (per side)

# Knob + encoder (EC11 dimensions from KiCad RotaryEncoder_Alps_EC11E-Switch_Vertical_H20mm)
KNOB_C = (27.5, 35.0)       # knob / shaft centre on the face
KNOB_D = 48.0
KNOB_H = 12.0
KNOB_GAP = 1.0              # air gap between knob skirt and face (push travel is ~0.5)
KNOB_FLUTES, KNOB_FLUTE_D = 60, 1.2   # fine vertical grip ribs round the skirt
KNOB_MARK = (13.0, 20.5, 135.0, 1.2)   # radial line marker: from r, to r, angle, width
KNOB_HALO = (24.7, 25.7, 0.6)  # thin groove ring in the face round the knob: r in, r out, depth
EC11_BODY = (12.0, 11.6)    # NOMINAL body footprint
EC11_BODY_H = 6.5           # NOMINAL body height above its PCB
EC11_BUSH_D, EC11_BUSH_L = 7.0, 7.0   # M7 bushing, NOMINAL length
EC11_SHAFT_D, EC11_SHAFT_H = 6.0, 19.7  # D shaft, top 21 mm above the HW-040 board underside
EC11_FLAT = 1.5             # D-flat depth
ENC_HOLE_D = 7.4            # face hole for the bushing
# HW-040 module, in its own frame: origin at the board centre, +x towards the header end,
# -y towards the long edge carrying the two mounting holes. From a dimensioned drawing
# (26 x 18.5 x 1.3, shaft top 21 mm) and a back-side photo, scaled; NOMINAL to about ±0.5 mm.
HW040 = (26.0, 18.5, 1.3)   # board length, width, thickness
HW040_SHAFT = (-3.7, 1.25)  # shaft centre
HW040_HOLES = [(-8.4, -7.45), (5.8, -7.45)]  # two M3 holes along the long edge, ~14 mm apart
HW040_HOLE_D = 3.0
HW040_HDR_X = 10.35         # right-angle header pin row (pins point +x, along the board)
HW040_BACK_KEEPOUT = (-9.0, 9.0, -4.0, 6.0)  # shaft-relative: EC11 legs + 3 pull-up resistors underneath

# Display: ST7789 1.3" 240x240, 7-pin module, mounted rotated 90° (header on the right)
DISP_C = (78.0, 46.0)       # centre of the active area on the face
DISP_ACTIVE = 23.4          # active area (square), several sources agree
DISP_WIN_MARGIN = 0.3       # window opening beyond the active area, per side
DISP_WIN_CHAMFER = 0.8
# Module frame: u runs along the 39.22 mm length, + towards the header end. Positions from a
# product photo scaled to the 27.78 mm board width; NOMINAL to about ±0.5 mm.
DISP_PCB = (39.22, 27.78, 1.6)    # module PCB (length, width, thickness); 3.0 total with glass
DISP_GLASS = (27.6, 26.16, 1.4)   # glass incl. the FPC ledge at the end away from the header
DISP_ACTIVE_U = -0.5              # active-area centre from the board centre, along u
DISP_GLASS_U = -1.6               # glass centre from the board centre, along u (ledge side)
DISP_HDR_U = 2.2                  # 7-pin header row, from the header end
DISP_POCKET = 0.6           # glass pocket depth into the back of the faceplate
DISP_HEADER_SIDE = +1       # +1 header on the right end, -1 on the left end
DISP_HOLE_D = 2.0          # four corner holes, NOMINAL ("mounting holes: 2 mm")
DISP_HOLE_INSET = 2.0      # hole centres from both edges at each corner, NOMINAL
DISP_STANDOFF_D = 4.5
DISP_PINS = ["GND", "VCC", "SCL", "SDA", "RES", "DC", "BLK"]  # top to bottom as mounted

# Buttons: 12x12 tactile push switch, 10 mm tall (pads from KiCad SW_PUSH-12mm)
BTN_MID = (78.0, 18.0)      # middle button centre
BTN_PITCH = 18.0            # chord distance to the outer buttons (blueprint)
BTN_ARC_R = 80.0            # soft arc radius -> outer buttons ~2 mm lower, rotated ~13°
BTN_OPEN = 14.0             # face opening (blueprint)
BTN_CAP = 13.4              # cap body
BTN_FLANGE = 15.2           # retaining flange behind the face
BTN_FLANGE_T = 1.2
BTN_CAP_PROUD = 3.5         # cap top above the face
BTN_CAP_DISH = 0.4          # keycap-style cylindrical dish in the cap top
# 12x12 projected-plunger switch, seller drawing TS-G005 (7.5 mm version; this one is 10 mm tall)
SW_BODY, SW_BODY_H, SW_TOTAL_H = 12.0, 3.5, 10.0  # housing 12 x 12 x 3.5; head top 10 mm (seller)
SW_BOSS_D, SW_BOSS_H = 7.1, 4.3   # round platform on the housing, top 4.3 mm above the PCB
SW_NECK = 3.0               # stem neck, square, NOMINAL from the drawing
SW_HEAD, SW_HEAD_H = 4.0, 1.8  # square head, wider than the neck (caps slip over it), with a centre hole
SW_HEAD_CLR = 0.15          # cap socket clearance per side; the cap is held by its flange, not the stem
SW_PADS = [(-6.25, -2.5), (6.25, -2.5), (-6.25, 2.5), (6.25, 2.5)]  # pin 1,1,2,2 (land pattern Ø1.5)
SW_PEGS = [(0.0, -4.5), (0.0, 4.5)]  # clearance for locating bosses some 12x12 switches have (B3F)
SW_PEG_HOLE_D = 2.0
BTN_GPIO = ["IO0", "IO1", "IO20"]  # left, middle, right

# Printed PCB ("carrier"): same plane as a future real PCB
C_FRONT = -(FACE_T + EC11_BODY_H)  # -8.5: EC11 body sits on it and touches the face
C_T = 2.4                   # printed thickness (a real board is 1.6, it grows backwards)
C_BACK = C_FRONT - C_T
C_INSET = 0.8               # carrier outline inset from the inner walls
HOLE_D = 1.2                # 2.54 mm header holes
SW_HOLE_D = 1.8             # switch legs
POSTS = [(7.0, 7.0), (7.0, 63.0), (104.0, 64.5), (104.5, 26.5)]  # face posts locating the carrier
POST_D, PIN_D, PIN_HOLE_D, PIN_L = 5.0, 2.4, 2.9, 2.0
GROOVE_W, GROOVE_D = 1.2, 0.8
PEG_CLR = 0.1               # peg diameter = hole - 2 * clearance (press fit)
PEG_PROUD = 1.0             # peg tip past the module board: press fit, or melt it (heat-stake)
PEG_RELIEF = 0.7            # face-back relief over the display peg tips (room for a staked head)

# ESP32-C3 SuperMini, on the carrier back, components facing the back plate
SM = (18.0, 22.52, 1.0)     # outline, NOMINAL thickness
SM_X = 55.0                 # board centre x (USB-C centred on the far wall)
SM_USB_END = H - WALL - 0.5  # y of the USB end of the board
SM_ROW = 15.24              # header row spacing
SM_PIN_MARGIN = (SM[1] - 7 * 2.54) / 2  # NOMINAL first pin from the USB end
# Columns as seen from the BACK (component side up, USB at the top). Seen from the face they
# mirror, so the "left" column sits at +x in the face frame.
SM_COL_A = ["5V", "GND", "3V3", "IO4", "IO3", "IO2", "IO1", "IO0"]    # at x = SM_X + row/2
SM_COL_B = ["IO5", "IO6", "IO7", "IO8", "IO9", "IO10", "IO20", "IO21"]  # at x = SM_X - row/2
SM_USB = (8.94, 7.35, 3.2)  # receptacle (width, depth, height), NOMINAL
SM_BTN_FROM_USB = 9.5       # NOMINAL BOOT / RST distance from the USB end
SM_BTN_DX = 4.5             # NOMINAL offset either side of the board centre line
SM_BTN = (3.0, 4.0, 1.5)
SM_RECESS_CLR = 0.15        # SuperMini sits flush in a recess in the carrier back
USB_CUT = (13.0, 7.0)       # far-wall slot for a moulded USB-C plug

# Back plate
PINHOLE_D = 4.0             # blueprint Ø4, paperclip / SIM pin
TUBE_OD = 7.0
TUBE_GAP = 0.6              # tube top below the lowest part around it
COLUMN_D = 5.0              # columns clamping the carrier against the face posts
HOOKS = [(-1, 18.0), (-1, 52.0), (+1, 18.0), (+1, 52.0)]  # (side, y centre)
HOOK_W, HOOK_T, HOOK_L = 8.0, 1.4, 10.0
HOOK_BARB = 1.0             # barb with 45° ramps both ways: snaps in, pulls out (a detent)
HOOK_GAP = 1.2              # arm to inner wall
RIB_DEPTH, RIB_H = 1.0, 1.5  # catch rib on the inside of the wall: no windows, nothing visible

# Floating plinth under the shell (part of the back plate, printed dark)
PLINTH_H = 3.0
PLINTH_INSET = 2.0          # inset from the face outline; the flared walls make the shadow ~4-5 mm
PLINTH_R = 6.0
FOOT_D, FOOT_DEPTH = 10.5, 1.0  # recesses for 10 mm stick-on rubber feet

# Dark visor: separate black panel standing 1 mm proud of the face (a recess would need a 60 mm
# bridge in the face-down print), carrying the display window and the button openings
VISOR_T = 1.0
VISOR_BOX = (44.0, 5.5, 106.5, 62.5)  # x0, y0, x1, y1 before the knob cut-out
VISOR_R = 6.0
VISOR_KNOB_R = 26.3         # concentric cut-out round the knob (even gap ring)
VISOR_EDGE = 0.5            # chamfer round the visor top edge
VISOR_PEGS = [(50.0, 60.0), (103.5, 60.0), (104.5, 32.0)]  # locating pegs into the face
VISOR_PEG_D, VISOR_PEG_H, VISOR_HOLE_D, VISOR_HOLE_DEPTH = 1.8, 1.0, 2.1, 1.2
UNDER_CLR = 0.3             # face openings behind the visor are this much bigger per side

FONT = "/System/Library/Fonts/Supplemental/Arial Bold.ttf"
TEXT_D = 0.4

DOC_NAME = "KivoriCase"
EXPORT = True

# ---------------------------------------------------------------------------------------------
# Geometry helpers
# ---------------------------------------------------------------------------------------------

K_WEDGE = (T_FAR - T_NEAR) / H


def z_back(y):
    """Outer back surface (desk side) at y."""
    return -(T_NEAR + K_WEDGE * y)


def rr_wire(w, h, r, z=0.0):
    hw, hh = w / 2.0, h / 2.0
    r = min(r, hw - 1e-3, hh - 1e-3)
    if r <= 1e-6:
        return Part.makePolygon([V(-hw, -hh, z), V(hw, -hh, z), V(hw, hh, z), V(-hw, hh, z), V(-hw, -hh, z)])

    def arc(cx, cy, a0, a1):
        c = Part.Circle(V(cx, cy, z), V(0, 0, 1), r)
        return Part.ArcOfCircle(c, math.radians(a0), math.radians(a1)).toShape()

    def line(a, b):
        return Part.LineSegment(V(a[0], a[1], z), V(b[0], b[1], z)).toShape()

    e = [
        line((-hw + r, -hh), (hw - r, -hh)), arc(hw - r, -hh + r, -90, 0),
        line((hw, -hh + r), (hw, hh - r)), arc(hw - r, hh - r, 0, 90),
        line((hw - r, hh), (-hw + r, hh)), arc(-hw + r, hh - r, 90, 180),
        line((-hw, hh - r), (-hw, -hh + r)), arc(-hw + r, -hh + r, 180, 270),
    ]
    return Part.Wire(e)


def place(shape, cx, cy, ang=0.0):
    s = shape.copy()
    if ang:
        s.rotate(V(0, 0, 0), V(0, 0, 1), ang)
    s.translate(V(cx, cy, 0))
    return s


def rr_prism(w, h, r, cx, cy, z0, z1, ang=0.0):
    f = Part.Face(rr_wire(w, h, r, z0))
    return place(f.extrude(V(0, 0, z1 - z0)), cx, cy, ang)


def box(x0, y0, z0, x1, y1, z1):
    return Part.makeBox(abs(x1 - x0), abs(y1 - y0), abs(z1 - z0), V(min(x0, x1), min(y0, y1), min(z0, z1)))


def cbox(cx, cy, w, h, z0, z1, ang=0.0):
    return place(box(-w / 2, -h / 2, z0, w / 2, h / 2, z1), cx, cy, ang)


def cyl(d, cx, cy, z0, z1):
    return Part.makeCylinder(d / 2.0, z1 - z0, V(cx, cy, z0), V(0, 0, 1))


TAPER = math.tan(math.radians(WALL_TAPER))
ALPHA = math.atan(K_WEDGE)
H_DESK = H / math.cos(ALPHA)  # length of the back plane along the slope


def tapered(w, h, r, z0, z1, cx=W / 2, cy=H / 2):
    """Rounded-rectangle frustum: (w, h, r) at z0, growing outwards towards z1 < z0 at WALL_TAPER."""
    g = (z0 - z1) * TAPER
    lo = rr_wire(w + 2 * g, h + 2 * g, r + g, z1)
    hi = rr_wire(w, h, r, z0)
    return place(Part.makeLoft([lo, hi], True, True), cx, cy)


def inner_x(z):
    """x of the left inner wall at height z (the wall leans outwards going down)."""
    return WALL + z * TAPER


def desk_to_face(shape):
    """Map a shape built in the desk frame (back plane = z 0, +z into the case) to the face frame."""
    s = shape.copy()
    s.rotate(V(0, 0, 0), V(1, 0, 0), -math.degrees(ALPHA))
    s.translate(V(0, 0, -T_NEAR))
    return s


def above_back(offset):
    """Everything on the case side of (back surface + offset)."""
    m = 10.0
    pts = [V(0, -m, 60), V(0, H + m, 60), V(0, H + m, z_back(H + m) + offset), V(0, -m, z_back(-m) + offset)]
    f = Part.Face(Part.makePolygon(pts + [pts[0]]))
    s = f.extrude(V(W + 2 * m, 0, 0))
    s.translate(V(-m, 0, 0))
    return s


def fuse_all(shapes):
    shapes = [s for s in shapes if s is not None]
    if len(shapes) == 1:
        return shapes[0]
    return shapes[0].fuse(shapes[1:]).removeSplitter()


def seg(p, q, w, z0, z1):
    """A straight groove from p to q with round ends."""
    dx, dy = q[0] - p[0], q[1] - p[1]
    length = math.hypot(dx, dy)
    b = box(0, -w / 2, z0, length, w / 2, z1)
    b.rotate(V(0, 0, 0), V(0, 0, 1), math.degrees(math.atan2(dy, dx)))
    b.translate(V(p[0], p[1], 0))
    return fuse_all([b, cyl(w, p[0], p[1], z0, z1), cyl(w, q[0], q[1], z0, z1)])


def text_solid(s, x, y, size, z0, depth, mirror=False):
    if not os.path.exists(FONT):
        return None
    try:
        faces = []
        for ch in Part.makeWireString(s, FONT, size, 0):
            if not ch:
                continue
            wires = [w if isinstance(w, Part.Wire) else Part.Wire(w) for w in ch]
            faces.append(Part.makeFace(wires, "Part::FaceMakerBullseye"))
        comp = Part.makeCompound(faces)
        bb = comp.BoundBox
        sol = comp.extrude(V(0, 0, depth))
        sol.translate(V(x - (bb.XMin + bb.XMax) / 2, y - (bb.YMin + bb.YMax) / 2, z0))
        if mirror:
            sol = sol.mirror(V(x, 0, 0), V(1, 0, 0))
        return sol
    except Exception as exc:  # text is cosmetic, never fail the build on it
        print("text skipped:", s, exc)
        return None


def rot(pt, ang):
    a = math.radians(ang)
    return (pt[0] * math.cos(a) - pt[1] * math.sin(a), pt[0] * math.sin(a) + pt[1] * math.cos(a))


# ---------------------------------------------------------------------------------------------
# Derived layout
# ---------------------------------------------------------------------------------------------

def button_poses():
    """(x, y, angle) for left, middle, right along the soft arc."""
    th = math.degrees(math.asin(BTN_PITCH / BTN_ARC_R))
    cy = BTN_MID[1] - BTN_ARC_R
    drop = BTN_ARC_R * math.cos(math.radians(th))
    return [
        (BTN_MID[0] - BTN_PITCH, cy + drop, th),
        (BTN_MID[0], BTN_MID[1], 0.0),
        (BTN_MID[0] + BTN_PITCH, cy + drop, -th),
    ]


BTNS = button_poses()
SW_PLUNGER_TOP = C_FRONT + SW_TOTAL_H

# Display: module u axis lies along face x (DISP_HEADER_SIDE says which way the header points)
dpcb_c = (DISP_C[0] - DISP_HEADER_SIDE * DISP_ACTIVE_U, DISP_C[1])
glass_c = (dpcb_c[0] + DISP_HEADER_SIDE * DISP_GLASS_U, DISP_C[1])
glass_z0 = -FACE_T + DISP_POCKET          # glass front
glass_z1 = glass_z0 - DISP_GLASS[2]       # glass back = module PCB front
dpcb_z1 = glass_z1 - DISP_PCB[2]          # module PCB back
disp_hdr_x = dpcb_c[0] + DISP_HEADER_SIDE * (DISP_PCB[0] / 2 - DISP_HDR_U)
disp_pins = {n: (disp_hdr_x, dpcb_c[1] + (3 - i) * 2.54) for i, n in enumerate(DISP_PINS)}
disp_holes = [(dpcb_c[0] + su * (DISP_PCB[0] / 2 - DISP_HOLE_INSET), dpcb_c[1] + sv * (DISP_PCB[1] / 2 - DISP_HOLE_INSET))
              for su in (-1, 1) for sv in (-1, 1)]

# HW-040: module frame axes match the face frame (header end towards +x, holes towards the near edge)
hw_c = (KNOB_C[0] - HW040_SHAFT[0], KNOB_C[1] - HW040_SHAFT[1])
hw_holes = [(hw_c[0] + hx, hw_c[1] + hy) for (hx, hy) in HW040_HOLES]
hw_hdr = (hw_c[0] + HW040_HDR_X, hw_c[1] + HW040_SHAFT[1])  # header row centre
hw_pin_tip_x = hw_c[0] + HW040[0] / 2 + 6.0                    # right-angle pins end about here
hw_wire_slot = (hw_pin_tip_x + 1.0, hw_pin_tip_x + 4.0)        # wires drop to the back through this
enc_pins = {n: ((hw_wire_slot[0] + hw_wire_slot[1]) / 2, hw_hdr[1] + (2 - i) * 2.54)
            for i, n in enumerate(["CLK", "DT", "SW", "+", "GND"])}
hw_floor = C_FRONT - HW040[2] - 0.1        # HW-040 pocket floor

sm_c = (SM_X, SM_USB_END - SM[1] / 2)
sm_z_comp = C_BACK                         # component side, flush with the carrier back
sm_pins = {}
for i, n in enumerate(SM_COL_A):
    sm_pins[n] = (SM_X + SM_ROW / 2, SM_USB_END - SM_PIN_MARGIN - i * 2.54)
for i, n in enumerate(SM_COL_B):
    sm_pins[n] = (SM_X - SM_ROW / 2, SM_USB_END - SM_PIN_MARGIN - i * 2.54)
sm_btns = [(SM_X - SM_BTN_DX, SM_USB_END - SM_BTN_FROM_USB), (SM_X + SM_BTN_DX, SM_USB_END - SM_BTN_FROM_USB)]
usb_z = sm_z_comp - SM_USB[2] / 2
tube_top = sm_z_comp - SM_USB[2] - TUBE_GAP


def btn_pin(idx, pad):
    x, y, a = BTNS[idx]
    dx, dy = rot(SW_PADS[pad], a)
    return (x + dx, y + dy)


def btn_peg(idx, k):
    x, y, a = BTNS[idx]
    dx, dy = rot(SW_PEGS[k], a)
    return (x + dx, y + dy)


# Nets: SuperMini pin -> list of component pins (pin map from README / profile.rs)
NETS = {
    "SCL": ("IO6", [disp_pins["SCL"]]),
    "SDA": ("IO7", [disp_pins["SDA"]]),
    "RES": ("IO3", [disp_pins["RES"]]),
    "DC": ("IO2", [disp_pins["DC"]]),
    "BLK": ("IO8", [disp_pins["BLK"]]),
    "3V3": ("3V3", [disp_pins["VCC"], enc_pins["+"]]),
    "GND": ("GND", [disp_pins["GND"], enc_pins["GND"], btn_pin(0, 0), btn_pin(1, 0), btn_pin(2, 0)]),
    "CLK": ("IO4", [enc_pins["CLK"]]),
    "DT": ("IO5", [enc_pins["DT"]]),
    "SW": ("IO10", [enc_pins["SW"]]),
    "B1": (BTN_GPIO[0], [btn_pin(0, 2)]),
    "B2": (BTN_GPIO[1], [btn_pin(1, 2)]),
    "B3": (BTN_GPIO[2], [btn_pin(2, 2)]),
}


def groove_routes():
    """Polylines for the wire grooves: SuperMini pad -> stub out of the recess -> each pin.

    A wire cannot run under the SuperMini, so a route whose straight line would cross the board
    drops into its own lane below the board first, and crosses over if it still has to.
    """
    stub = SM[0] / 2 + SM_RECESS_CLR + 1.5
    keep_out = (SM_X - stub + 0.5, SM_X + stub - 0.5, sm_c[1] - SM[1] / 2 - SM_RECESS_CLR - 0.8)

    def hits(p, q):
        for i in range(101):
            t = i / 100.0
            x, y = p[0] + (q[0] - p[0]) * t, p[1] + (q[1] - p[1]) * t
            if keep_out[0] < x < keep_out[1] and y > keep_out[2]:
                return True
        return False

    routes, lane = [], 0
    for net, (src, dests) in NETS.items():
        sx, sy = sm_pins[src]
        side = 1 if sx > SM_X else -1
        exit_pt = (SM_X + side * stub, sy)
        for d in dests:
            route = [exit_pt]
            if hits(exit_pt, d):
                y_lane = keep_out[2] - 1.6 - 1.7 * lane
                lane += 1
                route.append((exit_pt[0], y_lane))
                if hits(route[-1], d):
                    route.append((SM_X - side * stub, y_lane))
            route.append(d)
            routes.append(route)
    return routes


# ---------------------------------------------------------------------------------------------
# Parts
# ---------------------------------------------------------------------------------------------


def visor_outline(z0, z1, grow=0.0):
    x0, y0, x1, y1 = VISOR_BOX
    v = rr_prism(x1 - x0 + 2 * grow, y1 - y0 + 2 * grow, VISOR_R + grow, (x0 + x1) / 2, (y0 + y1) / 2, z0, z1)
    v = v.cut(cyl(2 * (VISOR_KNOB_R - grow), KNOB_C[0], KNOB_C[1], z0 - 1, z1 + 1))
    try:  # soften the two concave corners where the knob cut-out meets the edges
        sharp = [e for e in v.Edges if abs(e.BoundBox.ZLength - (z1 - z0)) < 1e-6
                 and e.Curve.TypeId == "Part::GeomLine" and e.BoundBox.XMax < KNOB_C[0] + VISOR_KNOB_R + 1]
        if sharp:
            v = v.makeFillet(1.5, sharp)
    except Exception as exc:
        print("visor corner fillet skipped:", exc)
    return v


def hook_geom(yc):
    """Left-side hook in the face frame: arm box, barb points and catch rib (mirror for the right)."""
    z0 = z_back(yc + HOOK_W / 2) + BP_T - 0.5
    zt = z0 + HOOK_L
    xa = inner_x(zt) + HOOK_GAP          # arm outer face
    b = HOOK_BARB
    barb = [(xa, zt - 2 * b), (xa - b, zt - b), (xa, zt)]
    x_r = inner_x(zt - 2.5) + RIB_DEPTH   # rib inner face
    z_rt = zt - 2 * b + (xa - x_r) - 0.05  # barb's lower ramp rests on the rib's top edge
    rib = (inner_x(z_rt - RIB_H) - 0.8, x_r, z_rt - RIB_H, z_rt)
    return z0, zt, xa, barb, rib


def mirror_x(shape, side):
    return shape.mirror(V(W / 2, 0, 0), V(1, 0, 0)) if side > 0 else shape
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

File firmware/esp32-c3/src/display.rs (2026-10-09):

//! SPI `DisplaySink` adapter via `mipidsi` (T072; research R-3).
//!
//! Implements the [`DisplaySink`] port on top of a `mipidsi` [`Display`], turning each change-driven
//! tile from [`crate::render::TileRenderer`] into one **windowed** `set_pixels` write — an address-window
//! command pair followed by exactly `w * h` RGB565 pixels. No framebuffer is held here (an ESP32-C3
//! cannot spare 115 KB); tiles stream straight over SPI.
//!
//! # Deliberately controller-agnostic
//!
//! This module never names a panel controller. It is generic over `mipidsi`'s [`Model`], so the same
//! adapter drives an ST7789, a GC9A01, or (in simulation only) an ILI9341, and the choice stays a
//! [`kivori_model::DeviceProfile`] parameter exactly as R-3 requires. The Kivori panel is a verified ST7789
//! (validation.md 1.23), but that choice lives in the board profile, so no controller is hard-coded and
//! no initialisation sequence is asserted in this module.
//!
//! # Deliberately hardware-neutral
//!
//! Nothing here depends on `esp-hal`: the adapter speaks only `embedded-hal` (`SpiDevice`, `OutputPin`,
//! `DelayNs`) through `mipidsi`. Consequences: it compiles for the host as well as `riscv32imc`, it is
//! unit-testable against a recording SPI device (see `tests/display_spi.rs`), and board bring-up (which
//! GPIO, which SPI peripheral, what clock) lives entirely outside it.
//!
//! # What this adapter does not decide
//!
//! Panel offsets are a **panel fact**, not a code default. [`PanelGeometry`] therefore takes the offset
//! explicitly — there is no `Default` — so an unknown offset cannot silently become `(0, 0)`.
//!
//! # Errors are never swallowed
//!
//! Every failed SPI write propagates as [`DisplayError::Interface`]. Geometry mistakes are rejected
//! *before* touching the bus: `mipidsi::Display::set_pixels` documents that it performs **no** bounds
//! checking and wraps around when handed the wrong pixel count, so this adapter checks both.

use crate::ports::DisplaySink;
use crate::render::{TILE_H, TILE_PIXELS, TILE_W};
use embedded_graphics_core::pixelcolor::raw::RawU16;
use embedded_graphics_core::pixelcolor::Rgb565 as EgRgb565;
use embedded_hal::delay::DelayNs;
use embedded_hal::digital::{ErrorType as PinErrorType, OutputPin};
use kivori_model::{DeviceProfile, Rect, Rgb565};
use mipidsi::interface::{Interface, InterfacePixelFormat};
use mipidsi::models::Model;
use mipidsi::{Builder, Display, InitError};

/// The visible panel window inside the controller's framebuffer.
///
/// `offset_x`/`offset_y` are the controller-frame origin of the visible area. They are a property of the
/// physical panel+controller pair (many 240x240 modules are offset inside a 240x320 or 132x162 frame) and
/// there is intentionally no default: pass what the panel's datasheet says, or `(0, 0)` only when that is
/// a verified fact.
#[derive(Debug, Clone, Copy, PartialEq, Eq)]
pub struct PanelGeometry {
    /// Visible width in pixels.
    pub width: u16,
    /// Visible height in pixels.
    pub height: u16,
    /// Visible-area x origin inside the controller framebuffer.
    pub offset_x: u16,
    /// Visible-area y origin inside the controller framebuffer.
    pub offset_y: u16,
}

impl PanelGeometry {
    /// Geometry from an explicit size and controller-frame offset.
    #[must_use]
    pub const fn new(width: u16, height: u16, offset_x: u16, offset_y: u16) -> Self {
        Self {
            width,
            height,
            offset_x,
            offset_y,
        }
    }

    /// Geometry taking the resolution from `profile` and the offset from the caller.
    ///
    /// The profile carries resolution and controller *choice*; it deliberately does not carry an offset,
    /// because that is a panel measurement rather than a rendering parameter.
    #[must_use]
    pub const fn from_profile(profile: &DeviceProfile, offset_x: u16, offset_y: u16) -> Self {
        Self::new(profile.width, profile.height, offset_x, offset_y)
    }
}

/// Why a tile could not be blitted.
#[derive(Debug, Clone, Copy, PartialEq, Eq)]
pub enum DisplayError<E> {
    /// The tile rectangle is empty, or extends past the visible panel area.
    TileOutOfBounds,
    /// `pixels.len()` did not equal `rect.w * rect.h`, so the window would under- or over-run.
    PixelCountMismatch,
    /// The display interface (SPI write or D/C toggle) failed.
    Interface(E),
}

/// A [`DisplaySink`] that writes tiles to a `mipidsi` display as windowed RGB565 transfers.
pub struct MipidsiSink<DI, M, RST>
where
    DI: Interface,
    M: Model<ColorFormat = EgRgb565>,
    EgRgb565: InterfacePixelFormat<DI::Word>,
    RST: OutputPin,
{
    display: Display<DI, M, RST>,
    geometry: PanelGeometry,
}

impl<DI, M, RST> MipidsiSink<DI, M, RST>
where
    DI: Interface,
    M: Model<ColorFormat = EgRgb565>,
    EgRgb565: InterfacePixelFormat<DI::Word>,
    RST: OutputPin,
{
    /// Wraps an already-initialised `mipidsi` display.
    ///
    /// `geometry` must match the `display_size`/`display_offset` the display was built with; it is what
    /// bounds checks are performed against.
    pub const fn new(display: Display<DI, M, RST>, geometry: PanelGeometry) -> Self {
        Self { display, geometry }
    }

    /// The geometry this sink validates tiles against.
    #[must_use]
    pub const fn geometry(&self) -> PanelGeometry {
        self.geometry
    }

    /// Borrows the underlying display (orientation, sleep/wake, tearing effect).
    pub fn display_mut(&mut self) -> &mut Display<DI, M, RST> {
        &mut self.display
    }

    /// Releases the display back to the caller.
    pub fn into_display(self) -> Display<DI, M, RST> {
        self.display
    }
}

/// The result of [`init_panel`]: a ready sink, or the reason the panel could not be brought up.
pub type InitResult<DI, M, RST> = Result<
    MipidsiSink<DI, M, RST>,
    InitError<<DI as Interface>::Error, <RST as PinErrorType>::Error>,
>;

/// Builds and initialises a panel, then wraps it as a [`MipidsiSink`].
///
/// `model` is supplied by the caller, so this function commits to no controller. The reset pin is driven
/// by `mipidsi` during init (low, then high) — a hardware reset the caller does not have to sequence.
///
/// # Errors
/// [`InitError`] if the reset pin fails, the interface fails, or `geometry` does not fit inside the
/// model's framebuffer.
pub fn init_panel<DI, M, RST, D>(
    model: M,
    interface: DI,
    reset: RST,
    delay: &mut D,
    geometry: PanelGeometry,
) -> InitResult<DI, M, RST>
where
    DI: Interface,
    M: Model<ColorFormat = EgRgb565>,
    EgRgb565: InterfacePixelFormat<DI::Word>,
    RST: OutputPin,
    D: DelayNs,
{
    let display = Builder::new(model, interface)
        .display_size(geometry.width, geometry.height)
        .display_offset(geometry.offset_x, geometry.offset_y)
        .reset_pin(reset)
        .init(delay)?;
    Ok(MipidsiSink::new(display, geometry))
}
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

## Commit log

2026-09-30 docs + Slice 002 rotary volume, consolidated on #3 (#2)
    * docs(product): add Kivori PRD
    * docs(product): add user story behavior contract
    * chore: placeholder
    * chore: remove accidental placeholder
    * chore: temp noop
    * chore: remove temporary file
    * chore: noop
    * chore: remove temporary file
    * chore: stop
    * chore: remove temporary file
    * chore: abort
    * chore: remove temporary file
    * docs(product): tighten interaction and display contracts
    * docs(product): refine interaction and execution edge cases
    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
    [lib.rs]
2026-09-30 feat(mascot): replace the blob with the keycap buddy (#4)
    * docs(product): refine gesture recovery and indicator contracts
    * docs(product): refine recovery testing and overlay behavior
    * docs(product): establish intentional visual feedb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
2026-10-02 fix(m0): harden the input and feedback path before hardware validation
    - Firmware captures encoder/switch edges in the GPIO interrupt into a bounded,
    timestamped queue, so quarter-steps during a frame compose/flush are no longer
    lost (rows 3.2-3.4). Decoding stays above the port.
    - Firmware renders on the tick a Presentation is applied instead of waiting out
    the 33 ms frame interval (row 3.14 latency remedy).
    - Desktop device thread blocks on serial bytes (bounded by the 50 ms tick)
    instead of sleeping a fixed tick (row 3.14 remedy 1).
    - Every SetState is answered with a StateReport, so a desktop reconnecting to
    a device already in the desired state learns it (row 1.16). Verified o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
    [physical_rotary.rs, physical_st7789.rs]
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2026-10-02 feat(firmware): push-switch Press/Hold, recovery hold, desk status and feedback
    - input::button: debounced (20 ms), edge-timed gesture machine. Press < 500 ms,
    Hold 500 ms..2 s, recovery takes the gesture at 2 s and reboots at 10 s from
    key-down. Fires once per press, no auto-repeat; a press that starts inside an
    open rotary gesture never becomes Press/Hold but can still recover.
    - Detents are swallowed while the switch is down (invariant 33). Recovery needs
    no host, session or capability (invariant 24); a session end drops a pending
    press but never a running recovery.
    - Press/Hold are sent only with PHYSICAL_INPUT_V1 + BUTTON_INPUT_V1 negotiated
    and a session accepted; nothing i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
    [physical_st7789.rs, wokwi_runtime.rs]
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2026-10-02 feat(desktop): M1 desk pipeline, macOS and Windows backends, desk IPC
    - desk: Press -> Play/Pause, Hold -> master mute (fixed bindings until M2).
    Actions run on a kivori-actions worker; the feedback ladder shows Processing
    at 500 ms and Unverified at 1.5 s (timeout is never Error); newest input
    replaces older feedback; nothing in flight survives a session end.
    Classification: mute StateConfirmed by read-back, play/pause StateConfirmed
    only when the media observer sees playback flip (else Unverified), shortcut
    always Unverified, launch ExecutionConfirmed, missing permission -> Error
    with permission_required. A failed volume streak is shown once as Error.
    - Status publisher: 1 Hz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
    [lib.rs]
2026-10-02 feat(ui): Desk panel, Device Studio test actions, validated desk IPC
    - Overview Desk panel: display-mode selector, volume/mute, media, CPU/RAM with
    high-load chip; every unknown value renders as an explicit dash. Last action
    shows Confirmed / Started / "Sent — result unknown" (neutral, no check) /
    Failed, plus the macOS Accessibility hint when permission is required.
    - Device Studio (dev builds only, tree-shaken from production) Test action
    panel: Play/Pause, Mute, Shortcut, Launch; native rejection strings shown.
    - lib/ipc: desk DTO types and wrappers, closed-vocabulary validation for desk
    status and activity events (unknown tokens rejected), stateful browser mock.
    - Ignore loca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
2026-10-02 docs: M0 hardening and M1 in architecture, roadmap, validation and README
    - architecture: protocol 1.3 (tags 15/16, Button input, bits 3-5), desk IPC,
    section 5b (push switch, recovery, desk pipeline, render order), macOS and
    Windows platform APIs, ADR-0007 (interrupt edge capture) and ADR-0008 (desk
    messages).
    - roadmap: M0 hardening recorded; M1 software items ticked, hardware rows and
    gates still open.
    - validation: firmware 1.1.0 / protocol 1.3 expectations, macOS Accessibility
    setup, Phase 4 (M1) checklist with gates G5/G6/G8, 2026-10-02 automated
    evidence (flash, handshake timings, StateReport fix, CoreAudio write path).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
2026-10-02 fix(firmware): review fixes and a lost HelloAck after an unread backlog
    - TX: TxBuffered accepts a whole frame or nothing, and a new Hello discards
    frames queued for no one (terminating any half-sent frame). After the host
    left the port unread ~50 s, the full queue used to truncate the HelloAck and
    every first connect waited out the 5 s retry. Reproduced and verified fixed
    on the ESP32-C3 (70 s idle -> Connected in 24 / 161 ms). TxBuffered moves to
    the hardware-neutral tx_buffer module so it is host-tested.
    - Clock wraps instead of saturating at ~49.7 days (a frozen clock would have
    disabled the recovery hold); frame/health deadlines are wrap-safe.
    - Each drained edge snapshot cl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
    [lib.rs, physical_rotary.rs]
2026-10-02 fix(desktop): review fixes — no stale actions, honest play/pause, macOS main thread
    - Requests still queued for the action worker are skipped after a session
    ends (epoch counter): no press from an old session runs later (gate 2).
    - Play/Pause is always Unverified: a matching media state can be stale or
    caused by something else, so it is never proof (gate 1). The worker no
    longer blocks for a confirmation window.
    - macOS input synthesis runs on the app main thread (run_on_main_thread):
    since macOS 15 enigo's HIToolbox layout lookups assert the main queue and
    abort the process otherwise.
    - VolumeChange.muted is Option: a device without readable mute still reports
    volume changes,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
2026-10-02 fix(dev): just app embeds the product firmware; explain firmwareUnavailable
    A plain cargo run bundles no firmware by design, so on macOS (no PowerShell
    bundling script) Flash firmware was always off and the log said only
    'Bundled firmware is unavailable'. The message now says why and how.
2026-10-03 feat(m1.1): double press = next view, now-playing text contract
    - Wire (protocol 1.4, append-only): InputKind::DoublePress (bit 6
    DOUBLE_PRESS_V1) and Message::MediaInfo tag 17 (bit 7 MEDIA_INFO_V1) carrying
    Latin-1 title/artist (MediaText, 32 chars, sanitized and cut with '~').
    - Firmware: a short press waits 250 ms for a second press only when the host
    negotiated DOUBLE_PRESS_V1 (otherwise it fires at once). A pair of short
    presses is one DoublePress; a long second press fires the first Press then
    Hold; recovery still runs from key-down. DeskState keeps a 60-sample CPU
    history, the previous view for a 320 ms switch animation, and media info.
    - Desktop: DoublePress cycles the di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
    [lib.rs]
2026-10-03 feat(ui): redesign Kivori Desktop as a product app (shadcn-first)
    - Sidebar shell with Home, Controls, Display, Activity, Device (+ dev-only
    Device Studio, gating unchanged), light/dark/system theme, connection toasts.
    - Home: device hero, CPU/RAM/volume cards with high-load and mute, now playing
    (title/artist), last action with honest result badges; plug-in guidance
    when disconnected; incompatible/connecting states.
    - Controls: Rotate / Press / Double press / Hold and the 10 s restart, result
    legend. Display: visual view cards with optimistic highlight that reverts
    on rejection or when desk://status disagrees. Activity: filters + search.
    Device: versions and confirm-before-flash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
2026-10-03 feat(display): redesigned desk views with view-switch slide
    One visual language around the #0c101c background: a single cyan accent
    for live values, amber for attention, anti-aliased integer primitives
    (coverage blended over the band, so tiles still stitch exactly), rounded
    monoline digits, 270-degree ring gauges and ISO-8859-1 fonts throughout.
    - Clock: large digits inside a 60-tick seconds ring driven by
    clock.second; VOL/CPU chips when known.
    - Volume: ring gauge; Confirmed solid, Preview hollow outline, Unverified
    dashed with grey digits; muted pill; unknown is a dashed gauge and "--".
    - Media: transport tile, PLAYING/PAUSED/STOPPED, title and artist from
    media_info with a determi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
    [lib.rs]
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2026-10-03 feat(ui): real keycap brand art and a hidden Developer mode
    - Brand: the sidebar mark, favicon, device picture's Buddy screen and the
    empty state use assets/icon/kivori-icon.svg and assets/mascot.svg directly
    (@brand Vite alias, single source); the old blue blob is gone. Accent tokens
    move to the keycap green (light primary #0f7a56, AA contrast).
    - Developer mode: a switch in Device > Advanced, off by default, remembered
    per computer (localStorage, off if storage fails). Off, it hides Device
    Studio and test actions, the Activity page, technical device rows
    (protocol, device ID, app protocol, buddy requested/on-device), buddy social
    reactions incl. Home's "Say hi", and the self-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
2026-10-04 feat(display): buddy home names the controls; issue #9 roadmap decisions
    The Buddy view now says what the knob, press and hold do (TURN / PRESS /
    HOLD under the keycap). Desktop derives the labels from the bindings it
    actually runs and sends them in a new ControlLabels message (tag 18,
    capability bit 8), once per session and on any binding change. The device
    only draws them: an empty label draws nothing, never a guessed action.
    Docs: the buddy is the home screen; app-aware profiles move before the
    paid beta as M2.5 (Windows, exe match, Protected first); "behavior modes"
    become pinned profiles; three extra buttons become a breadboard decision
    gate before M3 enclosure work; focus timer and ex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
    [lib.rs, physical_st7789.rs]
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2026-10-04 feat: app-aware profiles, buddy faces and the home layout (#12, #13, #14)
    Profiles (#12): foreground app on Windows (Win32, input desktop, token
    elevation) and macOS (NSWorkspace via raw Objective-C FFI, lock flag);
    400 ms stabilization; deliberate input commits a pending app; Protected
    commits at once, beats a pin and suspends shortcuts and launches with an
    Error while system actions keep working. Built-in General, Browser, Code,
    Media, Zoom, Teams. Hold the middle button to pin. Knob shortcuts send one
    key per detent with no badge; a knob gesture whose focus moves ends as
    Error / Context Lost, never retargeted. Labels and bindings come from one
    context. Controls page shows the active profi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
    [lib.rs, profile.rs]
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2026-10-09 fix: per-unit device id, multi-board discovery, firmware 1.2.0
    Device identity (#24): the product firmware derives its 16-byte device_id
    from the factory eFuse OPTIONAL_UNIQUE_ID (base MAC fallback) through a
    domain-separated SHA-256, so every board reports a distinct, stable id and
    raw eFuse bytes never go on the wire. A desktop test locks in that a board
    swapped onto the flashed port is never reported as a successful flash.
    Discovery (#23): a pure CandidateRotator replaces first_candidate. It tries
    every VID:PID match round-robin with per-port backoff, demotes a port after
    repeated handshake timeouts while another candidate exists, and skips an
    incompatible board until it is unplugged (ne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
    [display.rs, lib.rs, physical_st7789.rs]
2026-10-09 fix: drop stale discrete input actions (#26)
    A Press, Hold, DoublePress or contextual-button action older than 750 ms
    when the desktop is about to run it is dropped and logged as InputStale.
    Detents and gesture boundaries are always delivered.
    Session learns a device-to-host clock offset from Pong (wrapping u32,
    cleared on every session boundary; no offset means fail open). Age is
    checked after the session and gesture checks, and the remaining budget
    becomes an ActionWorker deadline so a job stalled behind a slow launch
    is skipped too. No wire change; InputEvent.device_ms is now documented.
2026-10-09 perf(desktop): batch same-gesture volume detents into one backend set (#18)
    Detents accepted in one loop pass are stepped per detent (clamping and
    reversal unchanged) and written with a single set + read-back and a
    single Presentation. Shortcut-bound detents are not batched.
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2026-10-09 feat(desktop): config store with display and buddy settings (M2 S1)
    Adds a versioned, atomically written config.json in the per-user app data
    directory with corrupt/newer-version recovery and a migration chain. Display
    default and double-press views and buddy reactions/intensity are now saved
    settings (get_config, set_display_settings, set_buddy_settings, reset_config,
    config://changed) that drive the desk runtime and companion director. Replaces
    configure_companion and the localStorage buddy settings, which migrate once.
    [lib.rs]
2026-10-09 feat(desktop): profile-shaped bindings with config overrides (M2 S2)
    Bindings are per-gesture slots (action plus label) and Hold is bindable
    except the middle button's, which stays reserved for the profile pin.
    Sparse config overrides are layered over the built-in profiles and
    validated (labels, shortcuts, launch targets). A saved change swaps the
    profiles live and forces a label re-send; a knob gesture in progress keeps
    its keys. IPC gains set_binding, set_rotate and reset_profile, and
    ConfigDto carries the resolved profiles. DeskStatusDto gets nullable
    press/hold, buttonHoldActions and profileId, with the TS types, parser,
    mock and Controls page updated in the same change.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
    [lib.rs, profile.rs]
2026-10-09 feat(desktop): action catalog, tokens and production Test Action (M2 S3)
    - desk/catalog.rs: ActionToken (desktop-only identity), the catalog with slot,
    scope, verification, params and runsWhenProtected, and availability(os, services).
    App Volume, App Mute and macros are listed as Unsupported "Coming soon".
    - ActionAvailability::Unsupported { reason }; Action::wire_kind()/token(), explicit is_system().
    - LastAction, Finished and activity DeskAction carry ActionToken; the wire gains no variants.
    - IPC: list_action_catalog and a production test_action (replaces the dev-only
    run_test_action) via DeviceCommand::TestAction and DeskRuntime::test, which refuses
    non-system actions while Prote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
    [lib.rs]
2026-10-09 feat(desktop): App Volume and App Mute through WASAPI sessions (M2 S4)
    Adds AppVolumeBackend (fake, unimplemented and macOS-unsupported stubs, Windows
    audio-session implementation on the kivori-audio thread), RotateSpec::AppVolume
    and ActionSpec::AppMute, Action::AppMute/AppVolumeStep and KnobTarget::AppVolume
    with one least-confirmed Volume feedback per gesture. Unsupported bindings
    error and never fall back to system volume.
    [profile.rs]
2026-10-09 feat(desktop): ordered macros with editor and bound-delete guard (M2 S6)
    Macros are resolved by id into shared Arcs and run on the action worker:
    steps in order, least-confirmed outcome, first Error stops with no rollback,
    stop on session end, and before a shortcut or launch if the foreground became
    Protected or left the starting app. save_macro and delete_macro (refused while
    bound) are exposed over IPC with TS types, validators, mock and vocabulary.
    Controls gains a Macros section, MacroEditor and a Macros group in the picker.
    [lib.rs]
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2026-10-09 feat(desktop): device status and diagnostics card (M2 S7)
    Keep Health free bytes, Pong uptime, round trip and malformed/gap/error
    counters in the session, publish them from the device thread once a second,
    and show them with host services and a config summary on the Device page.
    Copy diagnostics puts a path-free, port-free JSON on the clipboard.
    [lib.rs]
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2026-10-09 feat(desktop): firmware failure classes, recovery flash and bundled version (M3 S3)
    Sidecar lookup beside the executable (PATH only with device-studio), bounded
    in-process espflash stderr classified into FlashFailure tokens, recovery flash
    for the single allowlisted port (also from incompatible), Bye(FirmwareUpdate)
    before the port is released, and the bundled firmware version scanned from the
    image with update advice.
    [lib.rs]
2026-10-09 feat(desktop): firmware update and recovery UI (M3 S3)
    Failure copy, BOOT-button restore dialog (also on incompatible), bundled
    version and update advice on Device, an update hint on Home, mock scenarios,
    validation and docs.
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2026-10-09 feat(desktop): live catalog availability, knob Test, live startup switch
    - list_action_catalog reports the device thread's published backend availability, falling back to the OS expectation before the first snapshot
    - test_rotate tests the knob once: a volume nudge that ends where it began, or a shortcut pair's clockwise key
    - startup://changed keeps the Device page's launch-at-login switch in step with the tray
    [lib.rs]
2026-10-09 docs: fix stale phase/task references in comments and manifests
    [lib.rs, profile.rs]
2026-10-09 docs: post-M3 audit, user guide and BOM draft
    Fix stale roadmap notes, architecture IPC list/CI/versions, validation
    setup text, README docs table and Wokwi README. Add docs/user-guide.md
    and docs/bom.md.
2026-10-10 ci(web): call the build script with bun --filter <pkg> build
    Bun reads 'run' after --filter as a script name, so 'bun --filter kivori-web run
    build' failed with 'Script "run" not found'.
2026-10-10 feat(ui): shared @kivori/ui package; desktop to React 19; web uses shared primitives
    Move desktop's 26 shadcn components, cn, use-mobile and the theme into packages/ui
    (shadcn monorepo layout, source-only exports). Desktop and web import them via
    @kivori/ui; add Accordion and Textarea through the shadcn CLI. Web replaces its
    hand-rolled buttons, badges, FAQ, table, card and form controls with the shared ones.
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2026-10-11 feat(m2.6): quiet acknowledgement for trigger-only outcomes
    Appends FeedbackKind::Triggered behind capability bit 11 QUIET_ACK_V1 and
    bumps PROTOCOL_MINOR to 6. Media keys, shortcuts and macros whose weakest
    step is one report Triggered: a 400 ms keycap press and legend pulse, no
    badge, no celebration. State actions that cannot read back stay Unverified
    with the amber badge. Desktop downgrades Triggered to Unverified for devices
    that did not negotiate the bit; Activity and Test still say Unverified.
2026-10-11 feat(m2.6): device internals in developer mode
    Adds capability bit 12 DEVICE_INTERNALS_V1 and two appended messages
    (tag 19 InternalsRequest, tag 20 Internals) carrying one fixed-size,
    all-optional DeviceInternals snapshot. Physical firmware reports flash,
    RAM, stack high-water, load, frame timing, chip, temperature and link
    counters; desktop polls it once a second while the developer-mode
    Device internals card is visible and includes it in Copy diagnostics
    only with developer mode on.
2026-10-11 feat(m2.6): idle life on the device and a brightness setting
    Self-play scheduling moves into kivori-model (SelfPlay, IdleLife beside
    MascotAnimator) so the firmware runs the buddy's idle moments itself and
    keeps moving when the host stalls. New moments reuse the existing eye
    frames by moving the eye layer: glances left and right, a look towards a
    touched control (knob turn or press, each button) that starts on the touch
    before any feedback, and slower blinks late in the evening from the
    Desktop-supplied local clock. Eyes never close below 48/256 outside
    Sleeping. Deterministic: the integer timebase plus a seed (device id hash
    on a unit, fixed in Device Studio and golden frames).
    Adds capabi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
2026-10-11 feat(m2.6): profiles for any app
    Custom profiles matched by executable or bundle id, created from the app in
    front (the last non-Kivori foreground app) or a running app, as a one-time copy
    of General. Apps can be added to any profile and move between them; custom
    profiles can be renamed, deleted, reset to General and put in the pin cycle.
    App icons on macOS and Windows with a letter avatar fallback. Wider built-in
    matches for browsers and code editors.
2026-10-11 feat(m2.6): mic state on the wire and the device's mic indicator and face
    Adds capability bit 14 MIC_STATE_V1 and message tag 22 MicState (muted and in
    use, each optional; muted is Some(true) only when every microphone reads muted).
    The device draws the mic indicator in the top slot (slashed microphone muted,
    red microphone only when in use and unmuted, nothing when unknown) and wears a
    covered-mouth face (MicMuted, mouth frame 11) in the resting-face order after
    Error and celebrate and before strained. The mouth frame costs 780 bytes: the
    blob goes from 126,473 to 127,253 of 131,072, nothing trimmed. Golden frames
    added for the face and both indicator states; none changed.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
2026-10-11 feat(m2.6): truthful mic mute backend and action
    Mic Mute mutes every active capture device at the OS level and reads each back:
    Confirmed only if all read muted, Error if one stays live or has no mute control
    (macOS never falls back to input volume 0), Unverified if one cannot be read.
    A device that arrives while muted is muted and read back too. Outside changes
    arrive as External. macOS: CoreAudio input-scope mute per device, listeners,
    IsRunningSomewhere for in use. Windows: Core Audio endpoints with volume
    callbacks and an IMMNotificationClient, consent store for in use (unknown on
    failure). The desk sends MicState behind MIC_STATE_V1. Zoom and Teams bind the
    left button to Mic Mute by d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
2026-10-11 docs: plan M2.7 product identity, versioning and updates
    One app for several hardware products: a product/board registry, an
    Identity message, image identity records with a wrong-product guard,
    eFuse identity at provisioning, a compiled product catalog, and
    per-component versions through release-please. App updates through the
    Tauri updater and GitHub Releases (the one network exception) and a
    firmware offer on connect. Locking in tiers: software guard now, secure
    boot for v1 units with native USB. ADR-0014 to ADR-0016, validation
    Phase 14, planned release flow.
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2026-10-12 feat(m2.7): offer firmware updates when an older Kivori connects
    Step 6 of M2.7 (ADR-0015, product.md "Firmware updates (beta)"). A pure
    decision in src/firmware_offer.rs, evaluated by the device thread every tick,
    says none, offerOptional, required, updateApp or deferredForAppUpdate.
    - Only the bundled image whose identity record names the device's product
    and board counts; an unknown or foreign product, or an identity not yet
    reported, is offered nothing. The wrongProduct flash guard is unchanged.
    - The question appears after 5 s connected and idle (no gesture, no flash),
    keyed by device hash, bundled version and connection. "Later" hides it
    until the device next connects (in memo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
